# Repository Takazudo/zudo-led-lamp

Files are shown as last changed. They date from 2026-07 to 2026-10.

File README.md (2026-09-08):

# zudo-led-lamp

USB-PD powered LED lamp with fire/wave-like brightness modulation.

Docs: https://zudo-led-lamp.takazudomodular.com/

## Repo layout

- `doc/` — zudo-doc documentation site (source of truth for specs, notes, and build logs)
- `boards/board-p/` — KiCad project: USB-PD front end board
- `boards/board-l/` — KiCad project: driver + control + LED array board
- `boards/swd-adapter/` — KiCad project: ST-LINK/V2 20-pin to Board L 1x5 SWD adapter
- `enclosure/` — parametric starburst enclosure generator and [print/assembly guide](enclosure/README.md)
- `symbols/`, `footprints/` — shared KiCad symbol/footprint/3D libraries for all projects (see `footprints/CLAUDE.md`)

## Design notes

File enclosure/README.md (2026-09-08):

# Straight starburst bands — prototype 03

A **2.4 mm thin base plus six 13 mm single-piece bands**, approximately 116 mm across
and 86.4 mm tall excluding projecting fasteners. All star profiles align straight:
no twist and no assembly seams inside a band.

## Parts and color experiments

| File | Suggested color | Function |
| --- | --- | --- |
| 00-base | Clear | Thin mounting/access plate |
| 01-band-usb | Clear | 13 mm bottom band with USB notch |
| 02-band | Clear | 13 mm interchangeable middle band |
| 03-band | Amber | 13 mm interchangeable middle band |
| 04-band | Teal | 13 mm interchangeable middle band |
| 05-band | Clear | 13 mm interchangeable middle band |
| 06-band-top | Smoke | 13 mm top band without exposed pins |

Print each band in any color. **Bands 02–05 have identical geometry** and can be
reordered. Band body height excludes its 1 mm locating pins, which nest into the
next band and do not add to assembled height.

The current ZIP contains **21 assembly parts and eight fitting coupons**: seven
base/band pieces, eight PCB spacers, three feet and three flat-printable square posts. Replace your old extracted set.
The historical download name remains `smoke-reversing-stls.zip`; its contents are v3.
Find it in `doc/public/assets/enclosure/`, alongside `assembly-step.zip` containing
the complete assembled STEP. Reference electronics/hardware are excluded from print STLs.
The doc page `/docs/architecture/enclosure/` embeds the interactive preview.

## Connections and access

Three Ø2.4 × 1 mm pins enter Ø2.8 × 1.35 mm sockets and key the band orientation.
Three **printed 4 × 4 × 85.4 mm cuboid posts** pass through centered square holes
in the bands, base and feet. The default hole is exactly **4 × 4 mm** in CAD,
matching the requested post size. The posts are exported flat on an 85.4 × 4 mm
long face (only 4 mm tall on the print bed), but appear upright in the assembly.

The feet are **printed Ø12 × 6 mm round pads with centered square through-holes**,
without nut recesses. Try TPU for the feet and a rigid material for the posts.
Their intended assembled position leaves the post ends 1 mm above the bottoms
of the feet and flush with the top band; check that depth when fitting them.

There are no shell nuts, washers or threaded rods in this revision. Straight posts
provide fit-based retention, not positive axial locking or screw clamping. Support
the base when lifting the prototype; verify that parts do not slide unintentionally.

Print the 20 mm-long square-post coupon lying flat and the 13 mm-tall square-hole
coupons before the long posts. Holes of 4.0, 4.2 and 4.4 mm are supplied. Equal
nominal dimensions may bind after printing. If the 4.2 mm coupon fits best, regenerate
with `--post-clearance 0.2`; 0.4 selects 4.4 mm holes. The default remains zero.

The potentiometer opening is now a **30 × 38 mm rounded rectangular finger window**
instead of Ø24 mm. It extends toward the free side of the wheel while preserving the
nearby shared PCB mounting post. Corner radius is 6 mm. The switch retains its
20 × 24 mm opening. The wheel is still recessed: try actual fingertip adjustment
through a base print before committing to all bands.

The first band has an **18 × 13 mm full-height USB notch**. The second band closes
the roof during assembly, avoiding a wide printed bridge. Clearance checks use a
16 × 8 mm overmold to the PCB edge and an 8.4 × 2.6 mm metal-nose corridor.
Actual cable engagement is a physical check. Open top/base vents are not a thermal qualification.

## Print and assemble

1. Print the pin/socket coupons in the intended PETG. The 0.4 mm diametral-clearance
   coupon matches the enclosure. Adjust `socket_diameter` and regenerate if needed.
2. Print the base and spacers; dry-fit both boards and try operating the wheel by finger.
3. Board P uses three 5 mm spacers. Secure its independent hole before fitting the
   two 11 mm shared interboard spacers, three 17.6 mm Board L supports, and Board L.
   LEDs face upward, controls downward. The default 11 mm facing-surface gap is a
   prototype assumption: measure the naturally seated header pair before tightening.
4. PCB hardware: five approximately M3 × 25 mm nylon screws, one M3 × 14 mm nylon
   screw for Board P's independent hole, and six nylon nuts. Verify engagement and
   adjust lengths for your actual hardware.
5. Print the bands flat with pins upward, as separate objects in Bambu Studio.
   No additional rotation is required; an AMS is optional. Exchange middle bands freely.
6. Print the square posts in their supplied long-side-down orientation. Print the
   round feet flat, optionally in TPU using your filament/printer profile. Slide the
   feet, base and bands onto the square posts; keep the bottom post ends recessed
   1 mm above the feet bottoms. No metal shell fasteners are needed.
7. Check cable fit, slider travel, finger access, solder/lead clearance, retention
   and powered temperatures on the physical prototype.

Use the intended PETG profile, initially a 0.4 mm nozzle, 0.2 mm print layers and at
least three walls. Compare one thick band before the batch; solid/100% infill is an
optical starting point, not a tuned profile. Inspect the small locating-socket
bridges in the slicer; avoid supports inside sockets. The feet have open through-holes
and no internal nut-pocket roofs. Follow filament/plate instructions.
Material guidance: https://wiki.bambulab.com/en/knowledge-sharing/transparent-petg

## Regenerate and verify

`uv` and KiCad (`kicad-cli` on PATH) are enough; no CAD GUI is needed.

```sh
uv run enclosure/generate.py
# Optional measured facing-surface gap:
uv run enclosure/generate.py --board-gap 11.0
# Optional fit adjustment after testing the square-hole coupons:
uv run enclosure/generate.py --post-clearance 0.2
cd doc
pnpm generate:enclosure-viewer
pnpm build
```

Pinned CadQuery 2.6.1 and trimesh 4.8.3 run in an isolated uv environment.
The generator checks connected print bodies, watertight meshes, Z=0 placement,
PCB mounting/connector alignment, assembled solid interference and cable clearance.
The manifest records dimensions and source/mesh hashes and takes precedence after
custom regeneration. `--skip-pcb-models` is for debugging, not clearance validation.
Physical fit, fingertip ergonomics, solder, optical appearance and temperature still
need testing. Preview colors are illustrative; no optical or thermal simulation is claimed.

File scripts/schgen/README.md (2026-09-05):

# schgen — schematic generation from board spec modules

The `board-p`, `board-l`, and `swd-adapter` schematics are not hand-drawn. Each
is generated from a Python spec module (`board_p_spec.py`, `board_l_spec.py`,
or `swd_adapter_spec.py`) that lists components, positions, nets, and
no-connects. The spec is the source of truth; the `.kicad_sch` file is a build
artifact of it.

## Files

- `board_p_spec.py`, `board_l_spec.py`, `swd_adapter_spec.py` — per-project
  `COMPONENTS` / `NETS` / `NO_CONNECT` tables. Edit these, not the
  `.kicad_sch` directly.
- `schgen_core.py` — shared generator: reads symbols from
  `symbols/zudo-led-lamp.kicad_sym`, places components, and emits global
  labels for every net (no drawn wires) plus no-connect markers.
- `sexp.py` — tiny, dependency-free KiCad s-expression tokenizer/parser used
  by both the generator and the verifier. No KiCad install required.
- `gen_schematic.py` — CLI entry point: `generate()` a board from its spec.
- `verify_netlist.py` — diffs a kicad-cli netlist export against a spec's
  `NETS`/`NO_CONNECT` tables and prints `PASS`/`FAIL`.
- `verify_swd_adapter.py` — pure-Python end-to-end numeric orientation audit
  from the ST-LINK/V2 20-pin footprint through the adapter and straight cable
  to Board L J3; runs in CI.
- `verify.sh` — wraps the kicad-cli export + `verify_netlist.py` call for one
  board. Local-only (see below); not run in CI.

## Regen + verify workflow

1. Edit the relevant spec module — add/move a component, change a net, etc.
2. Regenerate the schematic:
   ```
   python3 scripts/schgen/gen_schematic.py swd_adapter_spec
   ```
   This rewrites `boards/<board>/<board>.kicad_sch` in place. No KiCad
   install needed — `gen_schematic.py` only depends on `sexp.py`.
3. Verify connectivity against a real netlist export (requires a local KiCad
   install with `kicad-cli` on `PATH`):
   ```
   scripts/schgen/verify.sh swd-adapter
   ```
   This runs `kicad-cli sch export netlist --format kicadsexpr` on the
   regenerated `.kicad_sch`, then diffs the result against the spec's `NETS`
   and `NO_CONNECT` tables via `verify_netlist.py`, printing `PASS`/`FAIL`.
4. Open the regenerated schematic in KiCad's Eeschema at least once (ERC,
   visual sanity) before committing.
5. Commit the spec module and the regenerated `.kicad_sch` together — never
   one without the other.

## kicad-cli availability

`verify.sh` degrades gracefully when `kicad-cli` is not on `PATH`: it prints
a `SKIPPED` marker and exits `0` rather than failing. This is intentional —
netlist verification is a local-only check that needs a real KiCad install
(the CI runner has no KiCad). Install KiCad (kicad-cli ships with the
desktop app; on macOS it resolves from `/Applications/KiCad/KiCad.app`) to
exercise the real path.

## What CI checks instead

CI cannot run kicad-cli, so it enforces a weaker but still useful invariant:
**regen-idempotency**. It runs `gen_schematic.py` for all three projects against the
checked-out tree and fails the build if that changes anything under
`boards/` (`git diff --exit-code boards/`). This catches "spec and committed
schematic have drifted apart" — e.g. someone edited a spec module and forgot
to regenerate, or hand-edited a `.kicad_sch` directly. It does **not** catch
wiring mistakes; only a local `verify.sh` run (or opening the file in KiCad)
does that.

## Low-profile rear controls

Board L fits G-Switch SS-12D01-G020 / C5446803 as SW2, with a reviewed through-hole PCB
footprint and 3D model. Common 2 receives V15_FUSED; pin 1 feeds V15; pin 3 is NC
on the board but becomes fused-feed live in OFF. No external-component export copy
is needed. `verify.sh board-l` checks the normal KiCad netlist and runs
`verify_power_switch.py` to verify fitted identity, NC and the ON/OFF supply graph.

RV1 is ALPS RK10J11E0034 / C470643 with physical stops. The wiper goes through
R27 to PA0 ADC_IN0, with R22 pull-down and C22 filtering. Four mechanical pads and
PA1 are NC. `scripts/pcb/verify-controls.py` checks the schematic/PCB net mapping,
corrected single-unit footprint pads, model bounds and two-board clearance.

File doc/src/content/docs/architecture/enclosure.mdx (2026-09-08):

---
title: Starburst Enclosure — Print and Assembly
description: A thin base plus six straight, interchangeable color bands, with larger fingertip access underneath.
sidebar_position: 37
---

**Prototype 03** combines the earlier thin panels into **six thick, single-piece
bands above a thin base**. All star profiles align straight, with no twist and no
assembly seams inside a band.

[Download current STLs](/assets/enclosure/smoke-reversing-stls.zip)
· [Open the full-size 3D preview](/assets/enclosure/index.html)
· [Assembled STEP (ZIP)](/assets/enclosure/assembly-step.zip)

[Assembled image](/assets/enclosure/assembled.png)
· [Exploded image](/assets/enclosure/exploded.png)
· [Underside controls](/assets/enclosure/underside.png)
· [Post in print orientation](/assets/enclosure/post-flat.png)
· [Original appearance reference](/assets/enclosure/selected-concept.png)

<iframe src="/assets/enclosure/index.html" title="Interactive starburst enclosure: assembled, exploded and underside views" width="100%" height="800" loading="lazy" style={{ border: "0" }} />

Use **Exploded** for the six bands, **PCB & base** for the mounts, and **Underside**
for the enlarged finger opening. Isolate individual parts to download their STLs.
The colors illustrate filament choices, not simulated light transmission.

## Thin base and six straight bands

The default size is approximately **116 mm across × 86.4 mm high**, excluding
projecting fasteners. Base thickness is **2.4 mm**, band thickness **13 mm**, and
foot height 6 mm. Locating pins add 1 mm of print height but nest into the next band.

| File | Body thickness | Suggested color | Function |
| --- | --- | --- | --- |
| `00-base` | 2.4 mm | Clear | PCB mounting and underside access |
| `01-band-usb` | 13 mm | Clear | Bottom band with USB notch |
| `02-band` | 13 mm | Clear | Interchangeable middle band |
| `03-band` | 13 mm | Amber | Interchangeable middle band |
| `04-band` | 13 mm | Teal | Interchangeable middle band |
| `05-band` | 13 mm | Clear | Interchangeable middle band |
| `06-band-top` | 13 mm | Smoke | Top band, no exposed locating pins |

**Bands 02–05 have identical geometry.** Print them in any colors and change their
order freely. The two clear pieces provide two independent color positions.
The first and last bands have distinct functional details; every outer profile aligns.

The ZIP contains **21 assembly parts and eight coupons**: seven base/band pieces,
eight PCB spacers, three round feet and three printed square posts. The historical filename is retained for existing
links, but the contents are v3. Replace the old extracted set rather than mixing revisions.

## Connections

Three **Ø2.4 × 1 mm pins** enter **Ø2.8 × 1.35 mm sockets**. Their asymmetric pattern
keys orientation. The broad band faces meet, with 0.4 mm diametral and 0.35 mm depth
clearance at the short pins. Each band prints flat with pins upward; the top band
has no upward pins.

Three **printed square posts, 4 × 4 × 85.4 mm**, pass through **4 × 4 mm square
holes** in the bands, base and feet. The nominal post and hole dimensions match
exactly, as requested. Each post is a plain cuboid exported on its long face:
**85.4 × 4 mm bed contact and only 4 mm print height**. The preview assembles it
upright; selecting an individual post shows its flat print orientation.

The feet are **Ø12 × 6 mm printed cylinders with centered square through-holes**,
without nut pockets. TPU is an option for the feet; use rigid filament for the posts.
In the assembly the posts end 1 mm above the bottoms of the feet and flush with the
top band. Check insertion depth and foot deformation on the physical print.

This is a **fit-based assembly**, without metal shell rods, nuts or washers. There
is no positive axial lock: straight posts cannot clamp the stack like threaded rods.
Support the base when lifting and check for unintended sliding.

Eight coupons cover both interfaces: the four existing short-pin/socket coupons,
plus a 20 mm flat square-post coupon and three 13 mm-high hole coupons with
**4.0, 4.2 and 4.4 mm square holes**. Exact nominal matching may bind in a real print.
If needed, `--post-clearance 0.2` produces 4.2 mm holes throughout the assembly;
`0.4` produces 4.4 mm holes. Default clearance is zero.

## Larger fingertip opening

The previous Ø24 mm potentiometer hole is replaced by a **30 × 38 mm rounded
rectangular window**, with 6 mm corner radii. It extends toward the free side of
the wheel to allow fingertip approach and sweeping movement. Its offset preserves
the nearby shared PCB post and the web supporting it.

In CAD coordinates, the window spans X14–44 and Y−6–32 mm before corner rounding;
the wheel center is approximately (21.9, 18). The switch has its separate
**20 × 24 mm** opening. Both controls remain recessed underneath. Print the base
first and actually turn the wheel by finger; CAD cannot establish comfort.

## PCB mounting and USB

Board L LEDs face up and its controls face down. Board P remains below it using
`xL = xP + 16.5`, `yL = yP`. Hole positions are read from the KiCad files.
See [Rear Controls](./rear-controls.mdx) for component placement and evidence.

| Spacer | Board L front-view coordinates (mm) | Supports |
| --- | --- | --- |
| `mount-01-17.6mm` | (4, 4) | Board L |
| `mount-02-17.6mm` | (4, 56) | Board L |
| `mount-03-5.0mm` | (20.5, 4) | Board P, shared hole |
| `mount-04-5.0mm` | (29.3, 32.6) | Board P, independent hole |
| `mount-05-5.0mm` | (39.5, 4) | Board P, shared hole |
| `mount-06-17.6mm` | (56, 56) | Board L |
| `interboard-01-11.0mm` | (20.5, 4) | Between boards |
| `interboard-02-11.0mm` | (39.5, 4) | Between boards |

The **11 mm facing-surface gap** remains provisional: measure the naturally seated
header pair before clamping. Do not pull the boards into an assumed spacing with
screws. An underside view mirrors left/right visually; do not mirror the STL files.

The bottom band has an **18 × 13 mm full-height USB notch**. The next band closes
its roof during assembly, so a wide horizontal bridge need not be printed.
The cable check reserves a 16 × 8 mm overmold corridor to the PCB edge and an
8.4 × 2.6 mm metal-nose corridor; actual insertion still needs physical verification.
The open top and base slots provide airflow, with powered thermal testing pending.

## Printing and assembly

1. Print pin/socket coupons in the intended filament. The 0.4 mm-clearance socket
   matches this version. Adjust `socket_diameter` and regenerate if needed.
2. Print the base and spacers; dry-fit the boards and test actual fingertip adjustment.
3. Mount Board P on three 5 mm spacers and secure its independent hole. Fit the two
   11 mm interboard spacers, three 17.6 mm Board L supports, then seat Board L LEDs up.
4. Print each band flat as a separate Bambu Studio object, pins upward. No extra
   rotation is required. Each band can use any color; an AMS is optional.
5. Print the long cuboid posts lying flat in the supplied STL orientation. Print
   the round feet flat, optionally in TPU. Slide feet, base and bands over the
   square posts; set the post bottoms 1 mm above the feet bottoms. Test retention.

PCB hardware starting point: **five M3 × 25 mm nylon screws, one M3 × 14 mm nylon
screw and six nylon nuts**. Check thread engagement and adjust for your hardware.
The shell connection posts and feet are now printed; no metal shell fasteners are
required. The PCB mount still uses the nylon screws listed above. The preview does
not model PCB screw threads or actual solder.

Start with the selected PETG profile, a 0.4 mm nozzle, 0.2 mm print layers and at least
three walls. Compare one thick band first: solid/100% infill is an optical starting
point, not a tuned prescription. Inspect the short locating-socket bridges and avoid supports
inside locating sockets. Follow filament/plate instructions and Bambu's
[transparent PETG guidance](https://wiki.bambulab.com/en/knowledge-sharing/transparent-petg).

## Source and verification

The source is `enclosure/generate.py`. `uv` installs pinned CadQuery and trimesh
in an isolated environment; KiCad exports the placed board/component geometry.
No desktop CAD application is needed to print these STLs.

```sh
uv run enclosure/generate.py
# Optional measured facing-board gap:
uv run enclosure/generate.py --board-gap 11.0
# Optional square-hole fit adjustment after the coupons:
uv run enclosure/generate.py --post-clearance 0.2
cd doc
pnpm generate:enclosure-viewer
pnpm build
```

The [manifest](/assets/enclosure/manifest.json) records dimensions, placements,
source/mesh hashes and verification results. It takes precedence over these default
dimensions after a custom regeneration. Checks cover connected print bodies,
watertight meshes, Z=0 placement, PCB mounts and connector alignment, assembled
interference and cable clearance. The docs build rejects stale source/mesh hashes.
Reference component meshes are excluded from the print ZIP.

The assembled-fit verdict remains **NEEDS BENCH**: verify actual seating, cable fit,
fingertip operation, solder/lead clearance, optical appearance and temperatures.
Existing component evidence and limitations are retained in
[Rear Controls](./rear-controls.mdx). The previous Board P guide correction on Board L
(`Edge.Cuts` → `Dwgs.User`) remains; this revision does not move components.

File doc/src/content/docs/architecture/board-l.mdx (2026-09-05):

---
title: Board L — Driver, Control, LED Array
description: The locked Board L design — 24 warm-white 2835 LEDs in 8 parallel 3-series strings at 500mA, an AL8860 constant-current buck, an AP63203 3.3V rail, an STM32G031 MCU and a stopped ALPS potentiometer, with a complete pin-level net table and worked component math.
sidebar_position: 30
---

Board L is everything that is not USB-PD negotiation: the constant-current LED driver,
the LED array itself, the 3.3 V logic rail, the control MCU, and the knob. It consumes
the switched 15 V rail from [Board P](./board-p.mdx) and nothing else.

The rear PCB [C5446803 slide switch](./power-switch.mdx) disconnects both
converters after F1. RV1 and SW2 are on the rear, leaving the LEDs facing the light chamber. See the
[rear-controls layout and enclosure handoff](./rear-controls.mdx).

## Block diagram

```mermaid
flowchart LR;
  J2["J2 PM254V female 6P\n15V x2, GND x2, ATT, PDOK"];
  F1["F1 PPTC\n750mA hold / 30V"];
  V15["V15 rail\nD10 SMAJ20A\nC10 C11 10uF"];
  RS1["RS1 200mR 2512\nhigh-side sense"];
  U2["U2 AL8860MP-13\nVIN pin 8"];
  SETN["SET node\nU2 pin 1"];
  L1["L1 33uH\n2.1A sat"];
  LEDP["LED_P\narray anode rail"];
  BAL["R30..R37\n8x 33R 2512 ballast"];
  STR["8 strings x 3 series\n24x HL-AM-2835H421W\n3000K, 62.5mA each"];
  LEDN["LED_N = switching node\nU2 SW pins 5,6"];
  D11["D11 SS26 60V\ncatch diode"];
  U4["U4 AP63203WU-7\n3.3V sync buck"];
  V33["V3P3 rail\nC16 C17 22uF"];
  U3["U3 STM32G031F8P6"];
  RV1["RV1 ALPS 10k potentiometer"];
  RT1["RT1 NTC 10k\nin the LED array"];
  RCF["R20 10k / R21 33k / C21 100n\nRC low-pass, 0 to 2.53V DC"];
  CTRL["U2 CTRL pin 4\nanalog dimming"];
  J3["J3 SWD pads"];
  J4["J4 UART pads"];

  J2 --> F1;
  F1 --> SW2["PCB slide switch C5446803\nmaintained ON-OFF"];
  SW2 --> V15;
  V15 --> RS1;
  V15 --> U2;
  RS1 --> SETN;
  SETN --> L1;
  L1 --> LEDP;
  LEDP --> BAL;
  BAL --> STR;
  STR --> LEDN;
  D11 --- LEDN;
  D11 --- V15;
  V15 --> U4;
  U4 --> V33;
  V33 --> U3;
  RV1 -->|"Wiper via RC filter\nPA0 ADC_IN0"| U3;
  RT1 -->|"PA4 ADC_IN4"| U3;
  J2 -->|"ATT / PDOK"| U3;
  U3 -->|"PA6 TIM3_CH1\n20kHz PWM"| RCF;
  RCF --> CTRL;
  J3 --- U3;
  J4 --- U3;
```

## LED array and the brightness number

The [LED candidates](/docs/research/led-candidates/) page left CCT open. For a
fire/candle effect the answer is **warm**, and warm is exactly where the JLCPCB stock
sits: `HL-AM-2835H421W-S1-08-HR3` ([C210315](https://jlcpcb.com/partdetail/C210315)) at
399,813 units, in the 2800–3100 K bin.

Its manufacturer specification (Honglitronic B-17-A-0596 Rev A/2) gives real optical
numbers, which the parts DB does not:

| Parameter | Value (at IF = 60 mA) |
|---|---|
| Luminous flux, 2800–3100 K bin | **27 lm min, 29 lm typical** |
| CCT typical | 3000 K |
| CRI (Ra) | 80 min |
| Forward voltage | 2.6 V min, 3.2 V max (±0.1 V measurement tolerance) |
| Viewing angle | 120° |
| Package rating | 306 mW |

### Arrangement

**8 parallel strings of 3 series LEDs = 24 emitters, 500 mA total, 62.5 mA per string.**

3-series was chosen over 4-series. The [headroom analysis](/docs/research/led-candidates/#voltage-headroom-analysis)
called 4s "tight"; with this part's datasheet Vf ceiling of 3.2 V a 4s string is 12.8 V,
which puts the buck at **~88% duty** by the datasheet's own equations — far outside the
AL8860's recommended 25–75% duty band (DS39014 Rev 5, "Recommended Duty Cycle Range").
3s plus a ballast resistor lands at **77%**, 2 points above the band and far below the
98% maximum — the trade this design accepts. (The worked figures are
[below](#al8860-constant-current-driver); the naive `Vout/Vin` reading gives 85%/74% and
understates both.)

### Brightness

| | Value |
|---|---|
| Typical flux | 24 x 29 lm = **~700 lm** |
| Worst-case bin | 24 x 27 lm = **648 lm** |
| System efficacy | ~700 lm / 6.16 W = **114 lm/W** |

For scale: a 60 W incandescent bulb is about 800 lm, and a typical decorative table lamp
is 300–600 lm. ~700 lm through a diffuser is a genuinely bright ambient lamp, and the
modulation spends most of its time below full scale.

The flux figures are read at the datasheet's 60 mA test point; the design runs 62.5 mA
(+4%), so the real number is marginally higher. It is quoted at the 60 mA value rather
than extrapolated.

### Ballast and current sharing

The parallel strings need ballast — [led-candidates](/docs/research/led-candidates/#current-sharing-considerations-for-parallel-strings)
lists three ways, and per-string resistors are the one that fits: one CC driver per
string would mean eight AL8860s and eight passive sets, and Vf-binned procurement is not
something the JLCPCB catalog can guarantee.

**R30–R37 = 33 Ω, 2512, 1 W** ([C2934070](https://jlcpcb.com/partdetail/C2934070), ±1%):

The design review moved this line from a 250 mW 1206
([C2907384](https://jlcpcb.com/partdetail/C2907384)) to a 1 W 2512. Resistor dissipation
goes as I², so the upsize is headroom against *peak* branch current, not nominal. At the
worst-case branch peak derived below — 88.19 mA, at the locked 0.30 V Vf spread — the
1206 would sit at **103% of its rating** (0.257 W);
at the LED's own 90 mA absolute-maximum forward current it would sit at 107% (0.267 W).
The 2512 runs at 26% of rating at that same 88.19 mA, and its larger copper helps spread
the array's heat.

| Quantity | Value |
|---|---|
| Ballast drop at 62.5 mA | 2.06 V |
| Dissipation per resistor | 129 mW — **13%** of the 2512 part's 1 W rating (was 52% of the old 1206's 250 mW) |
| Total ballast loss | 1.03 W (19% of delivered power) |

Current sharing across the eight strings is bounded by an **assembled-string Vf
spread** — `max(string total Vf) − min(string total Vf)` across the eight 3-LED
strings, not a ±-from-centre figure. And the driver's own datasheet worst case already
consumes most of the LED's headroom before any Vf mismatch exists: total peak current
is **0.6303 A** (the 0.5253 A maximum mean current at the AL8860's maximum sense
threshold over the sense resistor's minimum initial resistance, raised by half the
40% coil ripple the driver sets internally), against ballast of 33 Ω ±1% and a 90 mA
absolute-maximum LED forward current. Each input is a manufacturer-primary datasheet
limit, but the composed 0.6303 A is a calculated stack-up carrying a `NEEDS BENCH`
verdict — a datasheet worst case, not a measured or guaranteed one:

| Assembled-string Vf spread | Hottest branch, peak | vs the 90 mA absolute maximum |
|---|---|---|
| 0 V (perfectly matched) | 80.18 mA | 89.1% |
| **0.30 V (locked acceptance limit)** | **88.19 mA** | **98.0%** |
| 0.3677 V (computed bound) | 90.00 mA | 100.0% |
| 1.80 V (full retained 2.6–3.2 V window, unmitigated) | 128.27 mA | 142.5% |

**Even with perfectly matched strings the design sits at 89% of the LED's
absolute-maximum forward current on a peak basis.** The driver's own datasheet worst
case — maximum sense threshold, minimum sense resistor, full ripple peak — consumes 89%
of the limit before any Vf mismatch exists; the entire Vf-matching budget is the
remaining 9.8 mA. At the full retained 2.6–3.2 V window, unmitigated, the hottest LED
reaches 128.3 mA peak / 114.9 mA mean — 142% / 128% of the absolute maximum. The old
conclusion here landed on exactly 90 mA only because it used nominal current with no
ripple and no resistor tolerance — that result was an artifact of the assumption, not a
property of the design.

On a **mean** basis the picture is comfortable: at the locked 0.30 V limit the hot
branch averages 74.8 mA (83% of 90 mA) and dissipates 194.6 mW at Vf = 2.6 V — **64%**
of the 306 mW package rating (not the smaller derived-not-datasheet figure this page
previously used, from 3.2 V × 90 mA rather than the manufacturer spec). Peak-against-
absolute-maximum is the conservative gate (no pulsed-current rating is retained for this
part); mean is what governs junction temperature. Both readings belong here: peak is the
gate, mean is the thermal reality.

**Locked acceptance limit: 0.30 V**, defined as the full spread across the eight
assembled 3-LED strings, not ±0.30 V. It applies per assembled string, not per LED —
0.30 V over three LEDs is 0.10 V each, exactly the datasheet's own Vf measurement
tolerance. Measurement protocol, summarized: 60 mA DC ±1%, either a single 10 ms pulse at
≤1% duty or a 30 s DC soak, applied identically to all 24 LEDs, at 25 ±3 °C with ≤10 mV
differential instrument uncertainty; sort all 24 LEDs descending by Vf and greedily
assign each to whichever of the eight groups currently has the smallest running sum;
gate on the assembled string totals, not on individual LEDs. Full protocol and scope:
[#35](https://github.com/Takazudo/zudo-led-lamp/issues/35).

Ballast stays **33 Ω, 2512, 1 W** — this finding is about the driver's own current
headroom, not the ballast value, and within the existing inventory there is no lever for
more margin (raising RS1 or increasing the ballast both need a new part). Raised as a
follow-up issue rather than fixed here: see
[#52](https://github.com/Takazudo/zudo-led-lamp/issues/52).

Ballast resistors sit on the **anode side** (between `LED_P` and each string's top LED)
so that the common `LED_N` node — the driver's switching node — stays as one compact
net instead of eight. Note the review's correction to the original rationale: `LED_P`
is **not** a quiet DC rail. The string voltage is essentially fixed, so when `LED_N`
swings 0 → ~15.5 V, `LED_P` swings ~11 → ~26.6 V right along with it — every net in
the LED array is a switching node. The anode-side placement still wins (one compact
`LED_N` beats eight), but no LED-array net may be poured as a large plane.

## AL8860 constant-current driver

`AL8860MP-13` ([C500782](https://jlcpcb.com/partdetail/C500782)), MSOP-8EP.

The AL8860 is a hysteretic buck with **high-side current sensing**: the sense resistor
sits between `VIN` and `SET`, and the LED string floats above an internal low-side NDMOS
switch. That topology is the reason `LED_N` (the common cathode) is a switching node.

| Design point | Value | Source |
|---|---|---|
| Sense resistor RS1 | **200 mΩ** → `I = 0.1 / Rs` = **500 mA** | DS39014 Rev 5, "LED Current Configuration" |
| Output voltage | 3 x 3.0 V + 2.06 V ballast = **11.06 V** | — |
| Duty cycle | **~77%** by the datasheet's own equations (which include the diode and resistive drops; the naive 11.06/15 = 74% understates it) — 2 points above the recommended 25–75% band, far below the 98% max | DS39014 Rev 5, "Inductor Selection" |
| Inductor L1 | **33 µH** | ripple is set internally at ±20% of sense threshold; L sets frequency |
| Switching frequency | `T = ΔI·L·(1/(Vin−Vout) + 1/(Vout+Vd))` → **~440 kHz** | under the 1 MHz max |
| Minimum on-time | 1.69 µs | above the 500 ns recommended minimum |
| RS1 dissipation | 50 mW on a 2 W part | 2.5% |
| L1 DCR loss | 310 mΩ x 0.25 A² = 78 mW | |
| D11 conduction | 26% x 0.5 A x ~0.45 V = 59 mW | |
| Switch conduction | 0.2 Ω x 0.25 A² x 0.74 = 37 mW | |
| **Estimated efficiency** | **~95%** from component losses; **92% used in the budget** | conservative vs the research page's 88% assumption |

Duty cycle across the LED's full Vf bin:

| Vf per LED | String V | Vout with ballast | Duty (datasheet eqns) | Note |
|---|---|---|---|---|
| 2.6 V (bin min) | 7.8 V | 9.86 V | 69% | inside the band |
| 3.0 V (nominal) | 9.0 V | 11.06 V | 77% | design point — 2 points above the recommended 25–75% band |
| 3.2 V (bin max) | 9.6 V | 11.66 V | 81% | accepted, still far below the 98% max duty |

These figures are all against the AL8860's **DSW** parameter — the recommended
buck-switch operating duty-cycle range, 25–75%, guaranteed by design (DS39014 Rev 5,
primary-confirmed). That is a different number from **DSW(MAX)**, the 98%
absolute-maximum duty cycle, and from the separate 5–100% analog-dimming range on the
**CTRL** pin — three distinct datasheet figures that are easy to conflate. The
77%-nominal design point sits 2 points above the DSW band and is unchanged by this
distinction; it is spelled out here because readers currently have to infer it.

The review corrected these duty figures (the original 66/74/78% used `Vout/Vin` without
the diode and resistive terms). The honest statement of the 3s-vs-4s choice is: 3s sits
*slightly above* the recommended band across most of the Vf bin; 4s at ~88% would sit
far above it. 3s is still the right call. If bench accuracy suffers, 22 Ω ballast pulls
nominal duty to ~72% at the cost of ~40% worse current sharing.

**Input rating vs a conditioned clamp point.** AL8860's recommended VIN maximum is 40 V and its
absolute maximum is **42 V** (DS39014 Rev 5, "Absolute Maximum Ratings"). Board P's
SMAJ20A table gives 32.4 V only at 12.3 A, 10/1000 µs, and 25 °C. AL8860 has **7.6 V
recommended / 9.6 V absolute static headroom** against that screening point, which is
why it was selected over PT4115. The actual waveform remains open—see
[Decisions](./decisions.mdx#led-driver-ic-driver-input-rating-vs-a-conditioned-clamp-screening-point).

## AP63203 logic rail (not an LDO)

`AP63203WU-7` ([C780769](https://jlcpcb.com/partdetail/C780769)), TSOT-23-6, fixed 3.3 V.

The [logic-rail research](/docs/research/control-logic-rail/) says an LDO is fine below
~30 mA, and this rail draws ~25 mA worst case. By that rule alone the LDO wins. The
conditioned rail-envelope screen overrides it:

| Candidate | VIN max | Against the conditioned 32.4 V table point |
|---|---|---|
| AMS1117-3.3 | 15 V | No operating margin at the nominal rail; absolute maximum cannot be the design point |
| HT7333-1 | 18 V | **14.4 V below** the conditioned screen, with little transient headroom |
| **AP63203WU-7** | 32 V recommended, **35 V DC / 40 V for 400 ms absolute max** (DS41326 Rev 3) | Static limits cover the screening point by 2.6 V DC / 7.6 V transient |

AP63203 provides the strongest supported static headroom for about $0.60 and a
three-part BOM increase. It does not close the protected-rail proof: actual clamp
current/waveform, effective capacitance, layout, loads, and bench behavior remain open
under issue #34.

Component values from DS41326 Table 2 (AP63203, 3.3 V): L = 3.9 µH, C1 = 10 µF,
C2 = 2 x 22 µF, C3 = 100 nF. Implemented as **L2 = 4.7 µH**
([C167874](https://jlcpcb.com/partdetail/C167874), 78 mΩ DCR — the datasheet asks for
under 100 mΩ, and 2.2–10 µH is its stated acceptable range), C14 = 10 µF, C16/C17 =
2 x 22 µF, C15 = 100 nF bootstrap. `EN` is left open: the block diagram (DS41326
Figure 3) shows an internal current source on EN and the pin description states "leave
open for automatic startup".

## MCU, knob, and dimming path

`STM32G031F8P6` ([C529334](https://jlcpcb.com/partdetail/C529334)), TSSOP-20, 64 KB
flash / 8 KB SRAM, Cortex-M0+, 12-bit ADC.

`RK10J11E0034` ([C470643](https://jlcpcb.com/partdetail/C470643)), stopped single-unit
10 kΩ potentiometer, read by PA0 / ADC_IN0.

### Analog dimming, not PWM dimming

This is the single most consequential control decision, and the AL8860 datasheet decides
it. DS39014 Rev 5 states that for PWM on the CTRL pin, "the PWM frequency is recommended
to be lower than 500 Hz" for high resolution. But the
[modulation research](/docs/research/modulation-algorithms/#pwm-carrier-frequency-choice)
sets the flicker-perception floor at ~300 Hz for peripheral vision. A 500 Hz PWM carrier
clears that by only 1.7x — thin margin for a lamp that is specifically meant to be seen
out of the corner of the eye. Pushing the carrier up to get flicker margin is exactly
what the datasheet says costs dimming accuracy.

**Analog dimming escapes the conflict entirely.** A DC level on CTRL scales the LED
current continuously; the LED current never chops, so there is no flicker frequency to
argue about and no PWM modulation of the inductor to make audible noise. The datasheet's
"Recommended Analog Dimming Range" is **5% to 100%**, a 20:1 span.

The DC level is produced by low-pass filtering an MCU PWM output — the "case (b)" the
modulation research anticipated:

```
PA6 (TIM3_CH1, 20 kHz PWM, 0-3.3 V)
   |
  R20 10k
   +---- R21 33k ---- GND      (divider: 3.3 V x 33/43 = 2.53 V at 100% duty)
   |
  C21 100nF ---- GND           (filter + AL8860 soft-start capacitor)
   |
  U2.CTRL
```

| Quantity | Value |
|---|---|
| Full-scale CTRL voltage, nominal | 3.3 V x 33/43 = **2.53 V** — just past the 2.5 V clamp point, so 100% duty = 100% of I_NOM **nominally** |
| Full-scale CTRL voltage, guaranteed floor | Rail 3.27 V min, R20 max 10.1 kΩ, R21 min 32.67 kΩ → **2.4978 V**, guaranteeing **99.9%** of I_NOM, not 100% |
| Filter cutoff | R20 ∥ R21 = 7.67 kΩ with 100 nF → **208 Hz** |
| PWM carrier | **20 kHz** — ~40 dB of attenuation, leaving tens of millivolts of residual ripple on a 2.53 V span, and above the audio band regardless |
| Animation update rate | **50 Hz** — filter τ is 0.77 ms against 20 ms frames, so no visible lag |
| Duty at the CTRL off threshold (0.3 V) | 11.9% |
| Duty at the 5% current floor (0.41 V) | 16.2% |
| Soft-start from C21 | 100 nF x 1.5 ms/nF = **150 ms** |

The "100% duty = 100% of I_NOM" claim is **nominal-only**. At the guaranteed worst-low
corner (rail at 3.27 V, R20 at its 1% maximum, R21 at its 1% minimum) CTRL's floor is
2.4978 V against the AL8860's 0.3–2.5 V analog-dim range, which guarantees **99.9%** of
I_NOM rather than 100%. Two items stay open alongside that number, not closed by it:

- The floor assumes `PWM_DIM` drives to the rail. No STM32G031 output-level (V_OH)
  rating is retained, so the GPIO's own drop is not covered by evidence. Physically it
  is negligible — the divider draws only 76.7 µA, so even a 50 Ω driver contributes
  ≈3.8 mV — but the 99.9% figure is conditional on an assumption the registry does not
  currently substantiate.
- The worst-high corner (rail at 3.33 V, R20 at its minimum, R21 at its maximum) puts
  **2.567 V** on CTRL, above the 2.5 V top of the analog-dim range. Benign for dimming —
  it simply saturates at full current — but no CTRL absolute-maximum rating is retained
  for the AL8860.

### Safe default-OFF

The AL8860's CTRL pin **floats to ON** ("leave floating for normal operation"). That is
the opposite of what [control-safety](/docs/research/control-safety/) requires, so the
default-off has to be built deliberately. Two independent mechanisms do it:

1. **R21, 33 kΩ pull-down on CTRL.** With PA6 in its reset high-impedance state, CTRL is
   tied toward ground rather than allowed to float up.
2. **C21's 150 ms soft-start.** Even in the worst case where the pull-down fails to hold
   CTRL below the 0.2 V off threshold, the driver's output cannot reach full current for
   150 ms. The STM32G031 reaches firmware GPIO configuration in roughly 1–2 ms after
   power-on reset — two orders of magnitude inside that window. The same protection
   covers brown-out and watchdog resets.

:::caution[The pull-down's bound is asserted but not retained — Gate 3 is a real gate]
The 2026-08-01 design review argued R21 *is* provable from the datasheet: the soft-start
spec (1.5 ms/nF to charge CTRL) bounds the internal bias current at ≤1.67 µA, which into
33 kΩ is **≤55 mV** — at least 3.6x below the 0.2 V off threshold, with PA6 Hi-Z at reset.

**Neither input to that argument is in the evidence registry.** There is no soft-start
rate and no CTRL bias-current fact anywhere under
`.claude/skills/component-al8860mp-13/`; the only retained CTRL fact is
[`fact-al8860-ctrl`](/docs/components/records/al8860mp-13/#fact-al8860-ctrl), which gives
the 0.2 V off threshold, the 0.3–2.5 V analog range and the PWM guidance — no bias
current. The ≤55 mV result therefore cannot be recomputed offline and, by this project's
own rule, `UNSOURCED` evidence cannot close a domain.

Worse, retaining the missing row would not rescue the argument. The soft-start rate is a
**typical** characteristic; the AL8860 publishes no *guaranteed maximum* CTRL source
current. A typical value cannot bound a worst case, so ≤1.67 µA is not a limit that can
be designed against however it is sourced — it is an estimate. R21 remains good practice
and almost certainly works; it is simply not a proof.

So: **mechanism 2 (C21's 150 ms soft-start) is the one that stands on its own**, and
mechanism 1 is a plausible but unevidenced bound. Gate 3's CTRL measurement with the MCU
held in reset (probe TP1) is a gate on this design, not a formality. Closing mechanism 1
properly means retaining the DS39014 soft-start row as a fact on the AL8860 record.
:::

### Knob mapping

RV1 is **ALPS RK10J11E0034 / C470643**, a single-unit 10 kΩ ±30% potentiometer
with **270° ±10° travel and physical stops**. Pin 1 is GND, pin 3 is V3P3,
and pin 2 is the wiper. The four dummy/support terminals remain unconnected.
The exact manufacturer drawing identifies electrical terminals at the two outer
positions and the centre of the five-terminal row; the two intervening terminals
are dummy supports, not a second resistor element.

`RV1.2 → BRIGHT_WIPER → R27 (100 Ω) → BRIGHT_ADC → U3.7 (PA0 / ADC_IN0)`.
R22 is now a 100 kΩ pull-down from BRIGHT_ADC to GND; C22 is 100 nF to GND.
R23, R28 and C23 are removed, and PA1/U3.8 is unconnected. With the pot's
maximum 13 kΩ track resistance, the conservative source resistance is
13 kΩ / 4 + 100 Ω = **3.35 kΩ** before the parallel pull-down is considered.
Use the documented **160.5-cycle ADC acquisition target**, and validate settling
after channel changes against the selected ADC clock, reference and device errata.
An open wiper discharges C22 through R22 with nominal **10 ms** time constant;
this biases an open wiper toward dark but does not detect every wiring or contact fault.

Firmware reads an absolute position rather than counting encoder edges. Calibrate
ADC endpoints, allow inversion after checking clockwise direction from underneath,
average samples, clamp the result and apply the existing brightness/modulation mapping.
The pull-down loads the track, so raw ADC codes are not an ideal unloaded angle scale.
Keep PWM off during reset and initialization; after valid ADC, PD-status and thermal
checks, ramp toward the measured knob position. There is no fixed 40% boot target.
These are implementation requirements: this repository has no executable control firmware.

### Modulation algorithm

Two layers of filtered noise ([approach 1](/docs/research/modulation-algorithms/),
layered as that page suggests) — a slow "breathing" layer and a faster "flicker" layer,
summed around the knob's base brightness. Approach 3 (recorded-flame LUT) is rejected
because no such dataset exists for this project; approach 2's bounded random walk is
folded in as the slow layer's character rather than kept as a separate mode.

This is an algorithm sketch, not executable firmware. The ADC/calibration and startup
helpers below require implementation; initialization must ramp from zero to the
validated absolute position before enabling normal animation.

```c
/* ---- fixed constants (tune against the real diffuser, not on the bench) ---- */
#define FRAME_HZ            50
#define SLOW_ALPHA          12    /* one-pole IIR alpha, /256 - lazy breathing   */
#define FAST_ALPHA          64    /* one-pole IIR alpha, /256 - candle flicker   */
#define SLOW_DEPTH          70    /* /256 of full scale                          */
#define FAST_DEPTH          38    /* /256 of full scale                          */
#define GAMMA               2.2f

/* CTRL-window mapping, from the divider + AL8860 thresholds above */
#define DUTY_FLOOR_Q16      10617 /* 16.2% of 65535 -> CTRL 0.41V -> 5% of I_NOM */
#define DUTY_FULL_Q16       65535 /* 100%          -> CTRL 2.53V -> 100%          */

static int16_t slow_state, fast_state;
static uint8_t gamma_lut[256];    /* lut[i] = round(255 * pow(i/255, GAMMA)) */

/* ---- one animation frame, called at FRAME_HZ ---- */
void animation_frame(void)
{
    /* 1. knob -> base brightness, perceptual 0..255 */
    uint8_t base = brightness_adc_calibrated();   /* averaged/inverted PA0, 0..255 */
    if (!startup_pd_thermal_checks_valid() || base == 0) {
        pwm_set_duty_q16(0);                     /* stop stays dark despite noise */
        return;
    }

    /* 2. two layers of low-pass-filtered noise */
    int16_t slow_raw = (int16_t)random_uniform(-128, 127);
    int16_t fast_raw = (int16_t)random_uniform(-128, 127);
    slow_state += ((slow_raw - slow_state) * SLOW_ALPHA) >> 8;
    fast_state += ((fast_raw - fast_state) * FAST_ALPHA) >> 8;

    int16_t modulated = (int16_t)base
                      + ((slow_state * SLOW_DEPTH) >> 8)
                      + ((fast_state * FAST_DEPTH) >> 8);
    uint8_t perceptual = (uint8_t)clamp_i16(modulated, 0, 255);

    /* 3. thermal derate (NTC on PA4) - see apply_thermal_derate() below */
    perceptual = apply_thermal_derate(perceptual, ntc_temp_c_x10());

    /* 4. hard off, or gamma -> CTRL window */
    if (perceptual == 0) {
        pwm_set_duty_q16(0);                      /* CTRL -> 0V, driver off      */
        return;
    }
    uint8_t g = gamma_lut[perceptual];
    uint32_t duty = DUTY_FLOOR_Q16
                  + ((uint32_t)g * (DUTY_FULL_Q16 - DUTY_FLOOR_Q16)) / 255u;
    pwm_set_duty_q16((uint16_t)duty);
}
```

The pipeline is `modulation -> thermal derate -> gamma LUT -> CTRL duty`, exactly the
composition [control-safety](/docs/research/control-safety/#fault-handling-sketch-over-temperature-derating-hook)
describes. The 256-byte gamma LUT is trivial against 64 KB of flash.

:::caution[Pulse-skip near the bottom of the analog range]
The "no flicker by construction" claim holds where the converter runs continuously. The
AL8860's ripple is set at 40% of the programmed current, so as CTRL dims, the required
on-time shrinks — at the 5% floor it computes to ~45 ns, far below the 500 ns
recommended minimum, and the datasheet's own "Pulse Skip Mode" waveform is what happens
instead: burst-firing at an unpredictable rate that *is* a flicker frequency. This is
inside the manufacturer's sanctioned 5–100% analog range, but Gate 4 must sweep CTRL
while watching `LED_N` on a scope and record where pulse-skip starts; if the burst rate
lands under ~300 Hz, raise the firmware's `DUTY_FLOOR_Q16` above that point.
:::

:::note[The dimming floor is 5%, not zero]
Analog dimming below 5% of I_NOM is outside the AL8860's guaranteed range, so the
effect's minimum is a ~25 mA / ~35 lm glow with a hard step to fully off at perceptual
zero. For a flame effect this is arguably correct — real embers do not go to black — but
it means a very slow fade-to-nothing is not achievable without PWM chopping. Worth
knowing before tuning `SLOW_DEPTH` so far that frames land at perceptual 0 and produce a
visible on/off snap.
:::

### Thermal derate

`RT1` is an `NCP18XH103F03RB` 10 kΩ B=3380 K NTC ([C13564](https://jlcpcb.com/partdetail/C13564))
placed **inside the LED array**, in a **100 kΩ** divider to PA4 (ADC_IN4).

| Board temperature | NTC resistance | PA4 voltage | 12-bit ADC code | Firmware action |
|---|---|---|---|---|
| 25 °C | 10.00 kΩ | 0.300 V | 372 | normal |
| 65 °C | 2.616 kΩ | 0.0841 V | 104 | `DERATE_START` — begin linear roll-off |
| 80 °C | 1.711 kΩ | 0.0555 V | 69 | `CRITICAL` — hard off |

The thresholds sit under the LED's own −40…+85 °C operating range with margin.

The binding limit on this divider's current is Murata's **0.1 mA maximum operating
current**, not the 100 mW power rating this page previously compared against. Murata's
own column header reads "Maximum Operating Current (25 °C)"; the parallel catalog term
"Permissive Operating Current" is defined as the current that keeps the thermistor's
self-heating rise to at most 1 °C. **The outgoing 10 kΩ divider violated it**: 168 µA
worst case at 25 °C — 1.68x the limit — rising to 288 µA at the `CRITICAL` point. That is
why R26 changed. A 33 kΩ divider was evaluated and rejected: with the NTC shorted,
3.33 V / 32.67 kΩ = 101.9 µA already exceeds the limit, and it crosses 100 µA at 119.4 °C
— inside the part's −40…+125 °C range. The selected **100 kΩ** divider's worst case is
**33.6 µA = 33.6%** of the limit — a 2.97x margin that holds at every temperature and
under a shorted-thermistor fault (`V3P3` max 3.33 V, R26 min 99 kΩ at 1%). Self-heating
at 25 °C is now 9.0 µW (30.0 µA through 10 kΩ), roughly 0.009 °C against the 1 mW/°C
typical dissipation constant — self-heating was never the binding constraint; the 0.1 mA
operating maximum is, and the outgoing divider exceeded it by 68% while this page
reported comfort against a rating that does not govern.

Three caveats apply to the table above:

- **Sample time.** The ADC channel must use the **160.5-cycle** sample time. Worst-case
  source impedance (R26 in parallel with the NTC, at R26's maximum) is 43.8 kΩ at
  −20 °C against the datasheet's 50 kΩ allowance at that sample time; the allowance is
  exceeded below about −25 °C, so **the sensing chain's stated validity floor is −20 °C
  at RT1**. C24's 100 nF supplies the sampling charge, so this is a conservative
  requirement, not a hard functional limit for an indoor lamp.
- **Resolution.** 104 − 69 = 35 counts across the 15 °C derate band = 2.37 counts/°C,
  i.e. **0.42 °C per LSB**. This is 7.1x coarser than the outgoing 10 kΩ divider
  (16.7 counts/°C) — adequate for a thermal roll-off, but a real cost of the change and
  stated here rather than buried.
- **Beta-only conversion.** Every resistance-vs-temperature value in the table above is
  computed from the NTC's 10 kΩ ±1% at 25 °C and its B25/50 = 3380 K ±1%, not from a
  guaranteed manufacturer R–T table (none exists for this exact part). Tolerance alone
  gives ±0.75 °C of uncertainty at the `CRITICAL` point, and substituting the typical
  B25/85 = 3434 K moves the same point a further ≈1 °C — so **the trip temperatures
  carry roughly ±2 °C of model uncertainty and are nominal design points, not
  guaranteed trip temperatures.**

The divider is fed from `V3P3`, and the ADC reference (VDDA) is also `V3P3`, so the
conversion is **ratiometric** — the ADC code depends only on the resistance ratio, and
rail tolerance cancels out of the threshold. Rail tolerance still matters for the
*current* envelope above, because that math is not ratiometric; that is why the
threshold table carries no rail-tolerance column while the current figures do. The
derate function is
[control-safety's](/docs/research/control-safety/#fault-handling-sketch-over-temperature-derating-hook)
unchanged.

## Net-connectivity table

Complete pin coverage for every active device. STM32G031F8P6 pin numbers are from ST
DS12992 Rev 4 Table 12 (TSSOP20 column); AL8860 from Diodes DS39014 Rev 5; AP63203 from
Diodes DS41326 Rev 3.

### Power input and protection

| Net | Connected pins (Ref.Pin) | Note |
|---|---|---|
| `VBUS_L` | `J2.1 J2.2 F1.1` | Both paired power contacts converge on the PPTC |
| `V15_FUSED` | `F1.2 SW2.2` | Fused positive feed to the slide-switch common |
| `V15` | `SW2.1 D10.cathode C10.1 C11.1 U2.VIN(8) RS1.1 D11.cathode C12.1 C13.1 U4.VIN(3) C14.1` | The board's 15 V rail. D10 = second SMAJ20A local to Board L, protecting the local converter input; actual transient qualification remains open |

### LED driver (U2, AL8860MP-13, MSOP-8EP)

| Net | Connected pins (Ref.Pin) | Note |
|---|---|---|
| `V15` | `U2.VIN(8) RS1.1 C12.1 C13.1 D11.cathode` | C12 10 µF bulk + C13 100 nF HF, both close to pin 8 |
| `SET` | `U2.SET(1) RS1.2 L1.1` | High-side sense node. RS1 = 200 mΩ between `V15` and `SET`; `I_LED = 0.1/Rs` |
| `LED_P` | `L1.2 R30.1 R31.1 R32.1 R33.1 R34.1 R35.1 R36.1 R37.1` | Array anode rail after the inductor |
| `LED_N` | `U2.SW(5) U2.SW(6) D11.anode LED3.K LED6.K LED9.K LED12.K LED15.K LED18.K LED21.K LED24.K` | **Switching node** — common cathode of all 8 strings. Keep this copper compact |
| `CTRL` | `U2.CTRL(4) R20.2 R21.1 C21.1 TP1.1` | Analog dim input + soft-start cap. TP1 is a bare test pad — Gates 3 and 4 both require probing this node |
| `GND` | `U2.GND(2) U2.GND(3) U2.EP C12.2 C13.2` | EP is a thermal pad — tie to the ground pour, do **not** use it as the electrical return path (DS39014 pin description) |
| No-connect | `U2.NC(7)` | Leave floating |

### LED array (8 strings x 3 series)

Strings are numbered 1–8; LEDs `LED1`–`LED24` in order, so string *n* holds
`LED(3n−2)`, `LED(3n−1)`, `LED(3n)`.

| Net | Connected pins (Ref.Pin) | Note |
|---|---|---|
| `LED_S1_A` | `R30.2 LED1.A` | String 1 anode, after ballast |
| `LED_S1_M1` | `LED1.K LED2.A` | String 1 internal node |
| `LED_S1_M2` | `LED2.K LED3.A` | String 1 internal node |
| `LED_S2_A` | `R31.2 LED4.A` | String 2 — pattern repeats for strings 2..8 |
| `LED_S2_M1` | `LED4.K LED5.A` | |
| `LED_S2_M2` | `LED5.K LED6.A` | |
| `LED_S3_A` … `LED_S8_A` | `R32.2 LED7.A` … `R37.2 LED22.A` | Same pattern; ballast R30+n−1 feeds string n |
| `LED_Sn_M1`, `LED_Sn_M2` | `LED(3n−2).K LED(3n−1).A`, `LED(3n−1).K LED(3n).A` | Two internal nodes per string |
| `LED_N` | `LED3.K LED6.K … LED24.K` | All eight string cathodes join the switching node above |
| `NTC_SENSE` | `RT1.1 R26.2 C24.1 U3.PA4(11)` | NTC top; RT1 physically placed among the emitters |
| `GND` | `RT1.2 C24.2` | |

### Logic rail (U4, AP63203WU-7, TSOT-23-6)

| Net | Connected pins (Ref.Pin) | Note |
|---|---|---|
| `V15` | `U4.VIN(3) C14.1` | C14 = 10 µF input cap |
| `SW_LOGIC` | `U4.SW(5) C15.1 L2.1` | Switching node, L2 = 4.7 µH |
| `BST` | `U4.BST(6) C15.2` | C15 = 100 nF bootstrap, SW to BST |
| `V3P3` | `U4.FB(1) L2.2 C16.1 C17.1 U3.VDD(4) C18.1 C19.1 RV1.3 R24.1 R25.1 R26.1 J3.4` | Fixed-output part — FB ties directly to the output, no divider (DS41326 §9) |
| `GND` | `U4.GND(4) C14.2 C16.2 C17.2` | C16/C17 = 2 x 22 µF per DS41326 Table 2 |
| No-connect | `U4.EN(2)` | Left open for automatic startup — internal current source and 1.18 V threshold per DS41326 Figure 3 |

### MCU (U3, STM32G031F8P6, TSSOP-20), all 20 pins

| Pin | Pin name | Net | Function |
|---|---|---|---|
| 1 | PB7 / PB8 | — | Unused, leave floating (configure as analog input in firmware) |
| 2 | PB9 / PC14-OSC32_IN | — | Unused, no external crystal (HSI16 + PLL to 64 MHz) |
| 3 | PC15-OSC32_OUT | — | Unused |
| 4 | VDD / VDDA | `V3P3` | Supply and ADC reference. `C18` 100 nF + `C19` 1 µF adjacent |
| 5 | VSS / VSSA | `GND` | |
| 6 | PF2-NRST | `NRST` | `C20` 100 nF to GND, and `J3.3` for the programmer |
| 7 | PA0 | `BRIGHT_ADC` | ADC_IN0 — absolute brightness |
| 8 | PA1 | NC | Unused |
| 9 | PA2 | `UART_TX` | USART2_TX → `J4.1` debug pad |
| 10 | PA3 | `UART_RX` | USART2_RX → `J4.2` debug pad |
| 11 | PA4 | `NTC_SENSE` | ADC_IN4 — thermistor divider |
| 12 | PA5 | `PDOK` | GPIO input, 10 kΩ pull-up (`R24`) — informational only |
| 13 | PA6 | `PWM_DIM` | TIM3_CH1 — 20 kHz PWM into the RC filter |
| 14 | PA7 | `ATT` | GPIO input, 10 kΩ pull-up (`R25`) — spare |
| 15 | PB0 / PB1 / PB2 / PA8 | — | Unused |
| 16 | PA11 [PA9] | — | Unused |
| 17 | PA12 [PA10] | — | Unused |
| 18 | PA13 | `SWDIO` | → `J3.1` |
| 19 | PA14-BOOT0 / PA15 | `SWCLK` | → `J3.2`. Boot source depends on the programmed option bytes (`nBOOT_SEL`/`nBOOT0`/`nBOOT1`), not on this pin alone — a blank device boots system memory regardless of BOOT0's state. No external pull is fitted; PA14/BOOT0 is sampled on NRST rising and shares this package pin with PA15/SWCLK. The resolved boot-mode selection is an open programming artifact — see [#46](https://github.com/Takazudo/zudo-led-lamp/issues/46) |
| 20 | PB3 / PB4 / PB5 / PB6 | — | Unused |

:::note[Multiplexed package pins]
TSSOP-20 bonds several die pads to one package pin (pin 1 = PB7+PB8, pin 2 = PB9+PC14,
pin 15 = PB0+PB1+PB2+PA8, pin 19 = PA14+PA15, pin 20 = PB3..PB6). This is normal for
STM32 low-pin-count packages. It matters here only for pin 19: SWCLK (PA14) shares the
pin with PA15, so PA15 must never be configured as an output in firmware.
:::

### Control and interface nets

| Net | Connected pins (Ref.Pin) | Note |
|---|---|---|
| `PWM_DIM` | `U3.PA6(13) R20.1` | 20 kHz PWM out |
| `CTRL` | `R20.2 R21.1 C21.1 U2.CTRL(4) TP1.1` | Filtered DC, 0 to 2.53 V |
| `BRIGHT_WIPER` | `RV1.2 R27.1` | Potentiometer wiper |
| `BRIGHT_ADC` | `R27.2 R22.1 C22.1 U3.PA0(7)` | 100 Ω series, 100 kΩ pull-down, 100 nF shunt |

| `PDOK` | `J2.4 R24.2 U3.PA5(12)` | R24 10 kΩ pull-up — Board P drives this open-drain |
| `ATT` | `J2.3 R25.2 U3.PA7(14)` | R25 10 kΩ pull-up |
| `NTC_SENSE` | `RT1.1 R26.2 C24.1 U3.PA4(11)` | R26 100 kΩ divider top to `V3P3` |
| `NRST` | `U3.PF2-NRST(6) C20.1 J3.3` | |
| `SWDIO` | `U3.PA13(18) J3.1` | |
| `SWCLK` | `U3.PA14(19) J3.2` | |
| `UART_TX` | `U3.PA2(9) J4.1` | |
| `UART_RX` | `U3.PA3(10) J4.2` | |

### Ground

| Net | Connected pins (Ref.Pin) |
|---|---|
| `GND` | `J2.5 J2.6 D10.anode C10.2 C11.2 C12.2 C13.2 U2.GND(2) U2.GND(3) U2.EP C14.2 U4.GND(4) C16.2 C17.2 U3.VSS(5) C18.2 C19.2 C20.2 R21.2 C21.2 C22.2 C24.2 RT1.2 RV1.1 R22.2 J3.5 J4.3` |

RV1 has four dummy/support terminals, all electrically unconnected.

### Connectors and pad groups

| Ref | Part | Pins | Note |
|---|---|---|---|
| `J2` | PM254V-11-06-H85 female, C2832269 | 6 | Direct mate for Board P's PZ254V-11-06P male `JOUT1`; mirrors its pin map exactly — see [Board P](./board-p.mdx#jout1-pin-assignment-locked) |
| `J3` | 1x5, 2.54 mm | SWDIO, SWCLK, NRST, 3V3, GND | **Footprint only.** Hand-fit a pin strip for bring-up; not in the assembly BOM |
| `J4` | 1x3, 2.54 mm | TX, RX, GND | Footprint only |
| `RV1` | RK10J11E0034 / C470643 | 1 endpoint, 2 wiper, 3 endpoint; four isolated supports | Rear stopped potentiometer |

## What the design review changed (2026-08-01)

This historical review predates the RV1 replacement; its encoder-specific changes are superseded.
An independent electrical review confirmed the then-captured netlist matched this page
pin-for-pin (including all 24 LED polarities and all four IC pinouts against their
datasheets) and made these changes, reflected above:

1. **Ballast R30–R37: 1206 250 mW → 2512 1 W** (C2934070). The old part exceeded its
   rating at the design's own worst-case string current.
2. **R27/R28 100 Ω added in series with the encoder phases.** C22/C23 otherwise
   discharge into the EC11 contacts on every closure — a contact-erosion fix that
   costs one Basic line.
3. **TP1 test pad added on `CTRL`.** Gates 3 and 4 both mandate measuring this node;
   it previously had nothing to probe.
4. **Duty-cycle figures corrected** (77% nominal, not 74%) and the **pulse-skip
   flicker risk at deep dimming** documented with a Gate-4 check.
5. **`LED_P` acknowledged as a switching node** — the whole LED array switches, and
   the layout guidance now says so.
6. An **open-string cascade** note: the driver holds *total* current, so each open
   string raises the survivors' share. See the corrected numbers below — the original
   "one open is tolerable" reading used nominal mean current and does not survive the
   datasheet worst case.

### Open-branch cascade — one open LED already exceeds the absolute maximum

The AL8860 regulates **total** current, so an open branch does not reduce output — it
redistributes. Re-running the published
[`calc-led-hot-branch-peak`](/docs/components/integration/#calc-led-hot-branch-peak) with
the branch count as a free parameter (same model, same retained inputs, hot branch at
minimum ballast tolerance and the rest at maximum):

| Branches | Vf spread | Hot branch, peak | vs 90 mA abs max | Hot branch, mean | vs 90 mA |
|---|---|---|---|---|---|
| 8 (intact) | 0 V | 80.18 mA | 89.1% | 66.81 mA | 74.2% |
| 8 (intact) | 0.30 V | 88.19 mA | 98.0% | 74.83 mA | 83.1% |
| **7 (one open)** | **0 V** | **91.60 mA** | **101.8%** | 76.33 mA | 84.8% |
| **7 (one open)** | **0.30 V** | **99.45 mA** | **110.5%** | 84.18 mA | 93.5% |
| 6 (two open) | 0.30 V | 114.44 mA | 127.2% | 96.64 mA | 107.4% |
| 5 (three open) | 0.30 V | 135.41 mA | 150.5% | 106.74 mA | 126.7% |

**One open LED already puts the survivors over the 90 mA absolute maximum on a peak
basis**, even with perfectly matched strings — the earlier "1 open → 71 mA/string" figure
was the nominal *mean* (500/7), not the datasheet worst-case peak, and understated it.
On a mean basis one open is still inside the limit (84.8–93.5%), so the failure mode is
accelerated ageing of the survivors, not immediate loss.

The AL8860's open-load protection does **not** help: it acts only when the entire LED
path opens ([`fact-al8860-faults`](/docs/components/records/al8860mp-13/#fact-al8860-faults)).
One branch of eight is still a valid load, so regulation simply continues at the same
total current. Raising the ballast does not help either — total regulated current is
unchanged.

The only real mitigations are lowering the total setpoint (RS1 240 mΩ gives ~417 mA and
holds the seven-branch worst case to 84.18 mA, at the cost of ~17% brightness and a new
BOM line) or per-branch current limiting. **Neither is applied**: this is a post-fault
condition on a lamp that is already visibly degraded, and the normal-operation headroom
it shares a root cause with is the open decision tracked in
[#52](https://github.com/Takazudo/zudo-led-lamp/issues/52). Recorded here so the number is
not lost; the setpoint decision belongs to that issue.

## Power budget

Against the 45 W / 3.0 A PD contract cap.

| Item | Voltage | Current | Power |
|---|---|---|---|
| LED array (24 emitters, 8 x 3s) | 9.0 V/string | 500 mA total | **4.50 W** |
| Ballast resistors (8 x 33 Ω) | 2.06 V | 500 mA | **1.03 W** |
| AL8860 conversion loss (η = 92% assumed) | — | — | 0.48 W |
| *LED channel input* | 15 V | 401 mA | *6.01 W* |
| Logic rail output (3.3 V, 25 mA worst case) | 3.3 V | 25 mA | 0.083 W |
| AP63203 loss (η ≈ 75% at this light load) | — | — | 0.028 W |
| *Logic rail input* | 15 V | 7.4 mA | *0.11 W* |
| F1 PPTC (90 mΩ typical) | — | 409 mA | 0.02 W |
| **Board L total** | 15 V | **409 mA** | **6.14 W** |
| Board P — Q1 conduction (65 mΩ @ V_GS −4.5 V) | — | 409 mA | 0.011 W |
| Board P — U1 quiescent (160 µA) | 15 V | 0.16 mA | 0.002 W |
| Board P — R11 100 kΩ gate pull-up | 15 V | 0.15 mA | 0.002 W |
| **System total** | 15 V | **~410 mA** | **~6.16 W** |

| Margin | Value |
|---|---|
| Against the 45 W cap | **13.7% used, 7.3x margin** |
| Against the 3.0 A cap | **13.7% used, 7.3x margin** |
| Worst case if Board P's R14 draws continuously (see [the open question](./board-p.mdx#one-number-this-pass-could-not-resolve)) | 6.64 W / 443 mA — **14.8% used, 6.8x margin** |

:::caution[F1's hold-current margin shrinks with ambient temperature]
The 750 mA hold rating is a 25 °C number. The PPTC's own thermal derating table gives
**0.41 A hold at 85 °C** ambient — against this design's ~409–443 mA worst-case load,
that margin can reach zero well before the fuse's own 85 °C ambient limit, let alone the
LED array's warmer local environment. The failure mode is a nuisance trip (the lamp goes
dark, then self-resets after cooling), not damage — F1 is resettable — but this is a real
operating constraint, not a fixed margin, and belongs in any enclosure thermal review.
:::

:::note[The 25 mA logic-rail budget is a load cap, justified against a down-rated inductor]
L2 (FNR4030S4R7MT, [C167874](https://jlcpcb.com/partdetail/C167874)) is rated for
**2.0 A** max-design heating current, but the AP63203's own recommended full-load
envelope wants a 2.7 A inductor (2 A load x the datasheet's 1.35x current headroom) —
primary-confirmed on both sides, a **−0.7 A** margin against that envelope. That gap is
acceptable here only because **this rail's actual draw is 25 mA**, three orders of
magnitude below the 2.7 A envelope the rating gap describes — the justification is load,
not rating, and the 25 mA figure above is the budget cap this design must not exceed. The
R26 NTC-divider change (100 kΩ, up from 10 kΩ) reduces this rail's draw further, by
roughly 135 µA (165 → 30 µA) — far below this table's resolution, so no power-budget
retabulation is needed.
:::

### The binding constraint is thermal, not the contract

The 45 W figure is a ceiling, not a target. Scaling this lamp to use it would mean ~7x
this dissipation inside a closed 3D-printed enclosure with no forced air — which the
[thermal budget](/docs/research/thermal-budget/) page's own numbers say plain FR-4 cannot
shed. **~6 W is the design's real ceiling**, set by board thermals, and the design sits
at it deliberately.

### Dissipation hot spots

| Site | Count | Each | vs limit |
|---|---|---|---|
| LED (nominal) | 24 | 0.19 W | 62% of the 306 mW package rating; ~19% of the ~1 W/site FR-4 guideline |
| LED (hot branch, mean, at the locked 0.30 V spread limit) | 3 | 0.195 W | 64% of the 306 mW package rating — comfortable on this thermal/mean basis |
| Ballast resistor, 2512 1 W | 8 | 0.129 W | 13% nominal; 26% at the 88.19 mA worst-case branch peak, 27% at the LED's 90 mA absolute-maximum rating |
| L1 (33 µH, 310 mΩ) | 1 | 0.078 W | — |
| D11 SS26 | 1 | 0.059 W | — |
| RS1 (200 mΩ, 2 W) | 1 | 0.050 W | 2.5% |
| U2 AL8860 | 1 | ~0.10 W | θJA 56 °C/W → ΔT ≈ 6 °C |
| U4 AP63203 | 1 | ~0.03 W | θJA 89 °C/W → ΔT ≈ 3 °C |

No site exceeds its rating on this thermal (mean) basis, and the two ICs barely warm.
The number to watch is not in this table: it is the **peak-current** comparison in
[current sharing](#led-array-and-the-brightness-number-ballast-and-current-sharing) — even at zero Vf spread the hot
branch's datasheet worst-case peak sits at 89.1% of the LED's 90 mA absolute-maximum
forward current, rising to 98.0% at the locked 0.30 V acceptance limit. That is a
driver-headroom finding, not a thermal one; see
[#52](https://github.com/Takazudo/zudo-led-lamp/issues/52). If a built board shows
visibly uneven strings, the assembly-time acceptance gate is what catches it, not a
bench thermal reading.

## References

- [LED candidates](/docs/research/led-candidates/) — the 2835/5730/COB comparison and the current-sharing analysis
- [Driver ICs](/docs/research/driver-ics/) — the PT4115 / AL8860 / TPS92511 comparison
- [Thermal budget](/docs/research/thermal-budget/) — the 1 W/site FR-4 guideline
- [Logic rail](/docs/research/control-logic-rail/) — the LDO-vs-buck dissipation math
- [MCU candidates](/docs/research/mcu-candidates/) — CH32V003 / STM32 / PY32 and their toolchains
- [Knob candidates](/docs/research/control-knob/) — current stopped-pot selection and historical encoder research
- [Modulation algorithms](/docs/research/modulation-algorithms/) — gamma, flicker thresholds, the three approaches
- [Safe default-OFF](/docs/research/control-safety/) — the hardware-not-firmware principle
- Diodes Incorporated DS39014 Rev 5 (AL8860) and DS41326 Rev 3 (AP63200/1/3/5)
- ST DS12992 Rev 4 (STM32G031x4/x6/x8), Table 12 pin assignment
- Honglitronic B-17-A-0596 Rev A/2 (HL-AM-2835H421W-S1-08-HR3)

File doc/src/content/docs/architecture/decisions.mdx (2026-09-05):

---
title: Decisions — Chosen vs Rejected
description: Every architecture slot recorded as a decision — what was picked, what was rejected, and the reason, traced back to the power and research pages.
sidebar_position: 50
---

One row per slot. "Rejected" here means *considered and not chosen*, not *bad* — most of
the rejected options are perfectly good parts that lost on one specific axis.

## Board topology

| | |
|---|---|
| **Chosen** | Two boards: Board P (USB-PD front end) + Board L (driver, control, LED array) |
| **Rejected** | Three boards, with the LED array on an aluminum MCPCB daughterboard |
| **Rejected** | One combined board |

Board P must be separate — it is a reusable switched-15 V sink module and its
[bring-up sequence](/docs/power/lessons-from-zudo-pd/#standalone-board-p-bring-up-sequence)
requires testing it completely alone before anything is attached.

The MCPCB daughterboard was rejected on the [thermal budget](/docs/research/thermal-budget/)'s
own numbers: that page puts the plain-FR-4 ceiling at roughly **1 W per LED site** and
reserves metal core for the concentrated-COB case (3.6 W in one 13.4 mm package). This
design runs **0.19 W per site**. A third board would buy nothing thermally and would cost
a second interconnect carrying the driver's ~440 kHz switching node down a wire harness.

The split boundary is still designed in — the array is a self-contained block on four
nets (`LED_P`, `LED_N`, `NTC_SENSE`, `GND`) — so the enclosure phase can lift it onto a
daughterboard later without touching anything else.

## LED

| | |
|---|---|
| **Chosen** | `HL-AM-2835H421W-S1-08-HR3` ([C210315](https://jlcpcb.com/partdetail/C210315)), 3000 K, 24 pieces, 8 parallel strings of 3 series, 62.5 mA per string |
| **Rejected** | CXA1304 COB (C510489 / C510492 / C510494) |
| **Rejected** | SMD5730 family (C2843887, C210353, C210346) |
| **Rejected** | Cool-white 2835 (C2843876, C210329) |

**CCT decided it.** This is a fire/candle lamp; 3000 K warm white is the aesthetic
requirement, and it is the only place a warm bin coincides with real JLCPCB stock
(399,813 units). Every 5730 candidate is 4000 K or cooler, which reads as daylight, not
flame.

The COB was rejected twice over: **all three CXA1304 SKUs show zero stock**, and at 3.6 W
in one package it would force the MCPCB the board split just rejected. The
stock-available fallback ([C22398559](https://jlcpcb.com/partdetail/C22398559)) has a
scanned datasheet with no machine-readable Vf or flux data — not something to design a
thermal budget around.

**3-series, not 4-series.** [Headroom analysis](/docs/research/led-candidates/#voltage-headroom-analysis)
called 4s "tight". Against this part's datasheet Vf ceiling of 3.2 V, a 4s string is
12.8 V, putting the buck at **~88% duty** by the datasheet's own equations — far outside
the AL8860's recommended 25–75% DSW band. 3s plus ballast lands at **77%**: 2 points
above the band rather than inside it, and far below the 98% DSW(MAX). See
[Board L](./board-l.mdx#al8860-constant-current-driver) for the worked figures — the
older 85%/74% pair used `Vout/Vin` without the diode and resistive terms.

## Current sharing between parallel strings

| | |
|---|---|
| **Chosen** | Per-string ballast resistors, 33 Ω 2512 FOJAN FRC2512F33R0TS ([C2934070](https://jlcpcb.com/partdetail/C2934070)); generator evidence places R30–R37 one per branch, while the primary specification gives 1 W nominal power and a calculated 5.745 V RCWV at 33 Ω |
| **Rejected** | One CC driver per string |
| **Rejected** | Vf-binned procurement, no ballast |

[led-candidates](/docs/research/led-candidates/#current-sharing-considerations-for-parallel-strings)
lists exactly these three. One driver per string means **eight** AL8860s and eight
complete passive sets on a board whose entire output is 5.5 W — absurd. Vf-binned
procurement is a supply guarantee the JLCPCB catalog cannot make.

Ballast costs **1.03 W (19% of delivered power)** and that is the honest price of the
choice. What it buys: strong sharing within a matched lot — not unconditional safety. At
the datasheet's full 2.6–3.2 V Vf window the hottest branch would still reach 142.5% of
the LED's 90 mA absolute maximum, which is why incoming lots are gated on the ≤0.30 V
string-spread acceptance bound (issue #35); within that bound the datasheet worst-case
branch peak stays at 98% of the absolute maximum (see board-l's current-sharing analysis
against the primary-confirmed 306 mW limit).

33 Ω specifically is a two-sided optimisation: larger ballast improves sharing but pushes
the duty cycle further past the driver's recommended band; smaller ballast does the
reverse. 33 Ω puts nominal duty at **77%** — accepted 2 points above the 25–75% DSW band
for the sharing it buys. It is **not** "the largest value that keeps duty under 75%": no
ballast value on this rail does that, because 3s alone is already at 69–81% across the
Vf bin. If Gate 4 shows a duty-band problem, 22 Ω pulls nominal to ~72% at the cost of
~40% worse current sharing.

## LED driver IC

| | |
|---|---|
| **Chosen** | `AL8860MP-13` ([C500782](https://jlcpcb.com/partdetail/C500782)) |
| **Rejected** | PT4115 ([C347356](https://jlcpcb.com/partdetail/C347356)) |
| **Rejected** | TPS92511 ([C114277](https://jlcpcb.com/partdetail/C114277)) |

### Driver input rating vs a conditioned clamp screening point

The [driver research](/docs/research/driver-ics/#rail-constraint-a-conditioned-tvs-screening-point)
screened each candidate against the SMAJ20A's **32.4 V** table point. That point is
specified only at 12.3 A, a 10/1000 µs pulse, and 25 °C; it is a conservative
selection reference, not a prediction or universal ceiling for the installed rail.
The [ratings matrix](/docs/power/ratings-matrix/) keeps the actual waveform open, and the
same screening point is published canonically as
[`fact-high-diode-smaj20a-clamp`](/docs/components/records/high-diode-smaj20a/#fact-high-diode-smaj20a-clamp)
with its exact conditions attached.

| Candidate | VIN operating | VIN absolute max | Against the conditioned 32.4 V screening point |
|---|---|---|---|
| PT4115 | 6–30 V | not confirmable from a primary datasheet in the research pass | Does not cover the screening point; no confirmed absolute-max fallback |
| **AL8860** | 4.5–**40 V** ([`fact-al8860-vin-recommended-max`](/docs/components/records/al8860mp-13/#fact-al8860-vin-recommended-max)) | **42 V** (DS39014 Rev 5, [`fact-al8860-vin-absolute-max`](/docs/components/records/al8860mp-13/#fact-al8860-vin-absolute-max)) | Covers the screening point by 7.6 V operating / 9.6 V absolute |
| TPS92511 | 4.5–65 V | — | Covers the screening point with the widest margin |

PT4115 is rejected by this conservative screening rule, not because 32.4 V has been
proven as the installed rail waveform. AL8860 provides more static headroom at the same
cost, while the actual transient still requires the source-impedance, parasitic,
simulation, and bench evidence tracked in issue #34.

TPS92511 offers more static voltage headroom, but was rejected on two counts: its 500 mA maximum
sits exactly at this design's operating current with **zero headroom**, and the research
pass could not confirm its IADJ formula or its full passive count from a primary
datasheet, so it is not schematic-ready. The AL8860 is characterised end to end.

The AL8860 also brought the decisive control-side property nobody was looking for: a
CTRL pin with a **guaranteed 5–100% analog dimming range**
([`fact-al8860-ctrl`](/docs/components/records/al8860mp-13/#fact-al8860-ctrl)), which is what made
flicker-free dimming possible (see below).

The cross-component behaviour of the whole driver stage — the sense resistor, inductor,
catch diode, ballast and LED envelope together — is published as
[`rule-al8860-led-stage`](/docs/components/integration/#rule-al8860-led-stage), including the exact statement of
what it refuses to promote to a PASS.

## Driver passive set

| Slot | Chosen | Reasoning |
|---|---|---|
| Sense resistor RS1 | 200 mΩ 2512 ([C459674](https://jlcpcb.com/partdetail/C459674), [record](/docs/components/records/rlp25feer200/)) | `I = 0.1/Rs` → exactly 500 mA. 50 mW on a 2 W part |
| Inductor L1 | 33 µH ([C177245](https://jlcpcb.com/partdetail/C177245), [record](/docs/components/records/fxl0630-330-m/)) | ~440 kHz switching, 1.69 µs on-time (above the 500 ns minimum), 2.1 A max-design Isat against 0.6 A peak |
| Catch diode D11 | SS26 60 V ([C7420363](https://jlcpcb.com/partdetail/C7420363), [record](/docs/components/records/ro-ss26/)) | Rejected SS24 (40 V) — it leaves zero margin against the AL8860's own 40 V input ceiling for a negligible price difference, exactly as the [driver research](/docs/research/driver-ics/) argued |
| Input caps | 10 µF 1206 + 100 nF 0603 | Datasheet asks 10 µF or higher X7R; see the [X5R deviation note](./bom.mdx#extended-part-fee-economics) |

## Logic rail

| | |
|---|---|
| **Chosen** | `AP63203WU-7` ([C780769](https://jlcpcb.com/partdetail/C780769)) — 3.3 V fixed synchronous buck |
| **Rejected** | HT7333-1 LDO ([C5451671](https://jlcpcb.com/partdetail/C5451671)) |
| **Rejected** | AMS1117-3.3 LDO ([C6186](https://jlcpcb.com/partdetail/C6186)) |
| **Rejected** | XL7015E1 buck ([C73013](https://jlcpcb.com/partdetail/C73013)) |

This is the one place where this pass **overrides** a research recommendation. The
[logic-rail page](/docs/research/control-logic-rail/) says an LDO is fine below ~30 mA,
and the actual budget is ~25 mA, so on dissipation grounds the LDO wins.

The rail envelope overrules it. AMS1117's 15 V absolute maximum leaves no operating
margin at the *nominal* rail voltage—an absolute maximum is not an operating target.
HT7333's 18 V ceiling has little transient headroom. As a conservative screen, it also
sits **14.4 V under** SMAJ20A's conditioned 32.4 V table point; that subtraction does
not predict the installed waveform, but it exposes evidence that the LDO choice cannot
close.

AP63203's absolute maximum is **35 V DC and 40 V for 400 ms** (DS41326 Rev 3). Its
static limits cover the conditioned 32.4 V screening point, so it is the strongest
candidate and costs about $0.60 plus three passives. This does not make the real clamp
event zero-risk: source impedance, waveform, effective capacitance, layout, and bench
behavior remain open.

XL7015E1 has still more static voltage headroom (80 V), but needs a feedback divider and a
150 kHz-class inductor whose researched candidate showed only **238** units in stock.
AP63203 is fixed-output, needs no divider, and its inductor is a 250,000-unit part.

## MCU

| | |
|---|---|
| **Chosen** | `STM32G031F8P6` ([C529334](https://jlcpcb.com/partdetail/C529334)), TSSOP-20 |
| **Rejected** | CH32V003F4P6 ([C5187096](https://jlcpcb.com/partdetail/C5187096)) |
| **Rejected** | PY32F002AF15P6TU ([C5292059](https://jlcpcb.com/partdetail/C5292059)) |
| **Rejected** | STM32C011F4P6TR ([C7373263](https://jlcpcb.com/partdetail/C7373263)) |

The [MCU research](/docs/research/mcu-candidates/) frames this as cost versus toolchain
friction and calls it "a preference call, not a technical blocker". At prototype
quantity the cost axis is noise: the whole spread is about **$1**, against ¥8,460 of
Extended-part setup fees. Toolchain friction, by contrast, is paid in hours during
bring-up.

So the decision is toolchain-first, and STM32 wins that axis by the research's own
assessment ("best-supported path on macOS by a clear margin" — official vendor tools,
Homebrew, OpenOCD, and PlatformIO all first-class, no community forks).

CH32V003 is rejected specifically on its **proprietary single-wire SDI** debug interface,
which only WCH-LinkE programmers speak. A one-vendor-probe dependency is a real cost on a
board that will be debugged interactively.

G031 over C011 for **64 KB flash versus 16 KB**: it keeps the recorded-flame LUT
modulation approach reachable without a board respin, for about $0.40. Hardware headroom
that removes a future respin is cheap at this price.

## Knob

**Current choice (2026-09-06): ALPS RK10J11E0034 / C470643**, single-unit 10 kΩ
±30%, 270°±10° travel with physical stops. It replaces the tall EC11 encoder and
provides absolute brightness position. The earlier encoder decision used the stock
information then available; it is superseded by this stocked low-profile wheel.

Use PA0 ADC_IN0, R27 100 Ω, R22 100 kΩ pull-down and C22 100 nF. Calibrate and
average ADC input, verify installed direction, and ramp from dark to the position
after valid PD/thermal checks. Do not restore the old fixed 40% startup target.

## Control scheme

### What the knob controls

| | |
|---|---|
| **Chosen** | **Base brightness** |
| **Rejected** | Speed |
| **Rejected** | Depth |
| **Rejected** | Mode-cycled combination via a push-button gesture |

Three reasons, in order of weight:

1. **A lamp knob that does not change brightness is a surprise.** Every other mapping
   requires the user to learn the device.
2. **Brightness is the parameter with a safety meaning.** Turning it down is also turning
   down heat, and turning it fully down is off. Speed and depth have no such property,
   and neither does a mode-cycled knob whose current mode is invisible.
3. **The selected potentiometer has no mode button.** The stopped absolute wheel
   controls brightness directly; no gesture is needed.

Speed and depth become firmware constants. They want tuning against the real diffuser
anyway — which does not exist yet, because the enclosure is out of scope — so freezing
them in firmware costs nothing now and is a one-line change later.

### Dimming method

| | |
|---|---|
| **Chosen** | **Analog dimming** — 20 kHz MCU PWM, RC low-passed to a DC level on CTRL |
| **Rejected** | Direct PWM on CTRL |

The AL8860 datasheet recommends PWM below **500 Hz** for good dimming resolution. The
[modulation research](/docs/research/modulation-algorithms/#pwm-carrier-frequency-choice)
puts the peripheral-vision flicker threshold near **300 Hz**. A 500 Hz carrier clears
that by 1.7x — thin for a lamp that is deliberately meant to be seen out of the corner of
the eye, and raising the carrier is exactly what the datasheet says degrades accuracy.

Analog dimming dissolves the conflict: LED current never chops, so there is no flicker
frequency at all, and no PWM modulation of the inductor to become an audible whine. The
datasheet's guaranteed **5–100%** analog range (20:1) is ample for a flame effect.

:::note[This is not free]
Analog dimming cannot reach true zero gracefully — below 5% of I_NOM the AL8860 is
outside its guaranteed range, so the effect bottoms out at a ~35 lm glow and then steps
to hard off. For a flame this is arguably right; for a design that needed a smooth fade
to black it would be the wrong choice. Recorded here so the constraint is not
rediscovered as a bug.
:::

The 20 kHz carrier is chosen to sit above the audio band entirely and to give the
208 Hz RC filter 40 dB of attenuation. It is an MCU-side frequency only — it never
reaches the driver as a switching signal.

### Modulation algorithm

| | |
|---|---|
| **Chosen** | Two layers of one-pole low-pass-filtered noise (slow "breathing" + faster "flicker"), summed |
| **Rejected** | Single-layer filtered noise |
| **Rejected** | LUT playback of recorded flame data |

[modulation-algorithms](/docs/research/modulation-algorithms/)
notes that layering 2–3 filtered-noise generators "adds realism at the cost of a bit more
CPU/RAM" — on a 64 MHz Cortex-M0+ running a 50 Hz animation loop, that cost is
unmeasurable, so take the realism. The bounded-random-walk approach's character is folded
into the slow layer rather than kept as a separate mode.

The LUT approach is rejected because **the dataset does not exist.** It needs a real
flame's luminance curve extracted from video, which is a separate project. The G031's
64 KB of flash keeps the door open for it.

### Safe default-OFF

| | |
|---|---|
| **Chosen** | 33 kΩ pull-down on CTRL **plus** the 100 nF filter cap doubling as a 150 ms soft-start |
| **Rejected** | Firmware-only default-off |
| **Rejected** | MCU internal pull-down alone |

[control-safety](/docs/research/control-safety/) is unambiguous that this must be a
hardware guarantee. The wrinkle the research could not know — because the driver was not
picked yet — is that the AL8860's CTRL pin **floats to ON**, so a pull-down is mandatory
rather than merely prudent.

The 2026-08-01 review argued R21 *is* bounded: the AL8860's soft-start rate (1.5 ms/nF to
charge CTRL) implies an internal bias current of ≤1.67 µA, which into 33 kΩ is ≤55 mV —
3.6x below the 0.2 V off threshold. **That argument currently has no retained fact.**
Neither the 1.5 ms/nF rate nor the ≤1.67 µA bound appears anywhere under
`.claude/skills/component-al8860mp-13/`; the record's only CTRL fact is
[`fact-al8860-ctrl`](/docs/components/records/al8860mp-13/#fact-al8860-ctrl), which gives
the thresholds and the dimming range but no bias current. Under this project's own rule
that `UNSOURCED` evidence cannot close a domain, **mechanism 1 is not closed** and
[Gate 3](./next-steps.mdx#bring-up-sequence-gate-3-—-board-l-power-section-alone-mcu-unprogrammed)'s CTRL
measurement is a real gate, not a confirmation.

The soft-start capacitor is the mechanism that stands on its own: the driver
physically cannot reach full current for 150 ms, and the MCU takes control within about
1–2 ms of power-on reset. Two mechanisms, one of them currently evidence-backed. An MCU
internal pull-down was rejected because it depends on firmware configuring it — which is
the very window being protected.

## Interconnect

| | |
|---|---|
| **Chosen** | Direct XFCN 2.54 mm 1x6 pair: [PZ254V-11-06P male C492405](https://jlcpcb.com/partdetail/XFCN-PZ254V_1106P/C492405) + [PM254V-11-06-H85 female C2832269](https://jlcpcb.com/partdetail/XFCN-PM254V_11_06H85/C2832269), power contacts doubled |
| **Rejected** | JST VH 2-pin ([C160315](https://jlcpcb.com/partdetail/C160315)) plus a signal connector |
| **Rejected** | Molex KK 2510 ([C2847671](https://jlcpcb.com/partdetail/C2847671)) |

The [interconnect research](/docs/research/led-interconnect/) framed the small-header
class's 3 A contact rating against VH's 10 A headroom. That framing assumed the load
was the 3 A contract cap. **It is 410 mA.** Each doubled contact carries 205 mA — 6.8%
of nameplate, a **14x** derated margin. The headroom problem VH exists to solve does not
occur in this design.

The selected direct header pair also fits the six required conductors exactly (2 power +
2 ground + ATT + PDOK) and eliminates the previously unresolved cable housing, crimps,
wire, and completed-harness BOM. Its tradeoff is mechanical: it is unkeyed and requires
reviewed PCB alignment, standoff, and retention.

Molex KK was never a real alternative — the research page includes it explicitly to show
the 3 A-per-contact ceiling is a whole-class property, not an XH quirk.

## Protection

| | |
|---|---|
| **Chosen** | Second SMAJ20A ([C571370](https://jlcpcb.com/partdetail/C571370)) local to Board L's input |
| **Chosen** | PPTC, 750 mA hold / 1.5 A trip / 30 V ([C976305](https://jlcpcb.com/partdetail/C976305)) |
| **Rejected** | Relying solely on Board P's D5 |
| **Rejected** | No fuse (relying on the PD source's 3 A limit) |

The local TVS costs one BOM line already on the order (D5 is the same part) and clamps
transients the ~30 cm harness can develop on its own inductance — the whole point of the
[TVS margin rule](/docs/power/lessons-from-zudo-pd/#tvs-margin-rule) is to clamp close to
what you are protecting.

The PPTC exists because there is a **7x gap between what the source will deliver and what
the board needs**: the PD contract allows 3 A, and Board L draws 410 mA. Without a fuse,
a Board L fault — a shorted LED string, a failed driver — can pull 45 W through a 2.5 mm
harness before anything intervenes. A 750 mA hold bounds that at under 2x the normal
draw.

**Conditioned open point:** the PPTC's 30 V rating
([`fact-bhfuse-voltage-max`](/docs/components/records/bsmd1206-075-30v/#fact-bhfuse-voltage-max)) is
**2.4 V below** the SMAJ20A's
32.4 V table value at 12.3 A, 10/1000 µs, and 25 °C. That subtraction is a useful
screening lead, not an installed-waveform result or an accepted over-rating. Actual
source impedance, clamp current, duration, parasitics, and fuse stress remain part of
the issue #34 simulation and bench gate.

## Summary of open conditioned risks

| Risk | Evidence status | Where |
|---|---|---|
| U1 STUSB4500 VDD, conditioned 4.4 V over its mirror-stated absolute maximum at the D5 table point | **UNSOURCED / waveform OPEN**, not accepted | [ratings matrix](/docs/power/ratings-matrix/), [`calc-stusb-vdd-clamp-overage`](/docs/components/integration/#calc-stusb-vdd-clamp-overage) |
| Q1 exact UMW (Youtai Semiconductor) AO3401A VDS, conditioned 2.4 V magnitude over absolute maximum at that table point | **Waveform OPEN**, not accepted | [ratings matrix](/docs/power/ratings-matrix/), [`calc-q1-vds-clamp-overage`](/docs/components/integration/#calc-q1-vds-clamp-overage) |
| F1 PPTC, conditioned 2.4 V over its 30 V rating at that table point | **Waveform and pulse stress OPEN**, not accepted | this page, above; [`rule-rail-envelope`](/docs/components/integration/#rule-rail-envelope) |
| Duty cycle 81% at the LED bin's Vf maximum, above the AL8860's 25–75% recommended DSW band (guaranteed by design, now primary-confirmed) | steady state, bounded — 98% DSW(MAX) is the hard maximum | [Board L](./board-l.mdx#al8860-constant-current-driver) |
| Even at zero Vf spread, the LED stage's datasheet worst-case peak current sits at 89.1% of the LED's absolute-maximum forward current — 98.0% at the locked 0.30 V acceptance limit | steady state, datasheet-bounded but bench-unverified (the composed peak carries a `NEEDS BENCH` verdict); residual driver-side headroom raised as [#52](https://github.com/Takazudo/zudo-led-lamp/issues/52) | [Board L](./board-l.mdx#led-array-and-the-brightness-number-ballast-and-current-sharing), [`calc-led-hot-branch-headroom`](/docs/components/integration/#calc-led-hot-branch-headroom) |
| R21's ability to hold CTRL low rests on a soft-start-derived ≤1.67 µA CTRL bias bound that **no retained fact carries** — the AL8860 record has no soft-start rate and no bias-current fact | **UNSOURCED**, not closed; Gate 3 (probe TP1) is a real gate, not a confirmation. C21's 150 ms soft-start is the independent mechanism that does stand | [Board L](./board-l.mdx#mcu-knob-and-dimming-path-safe-default-off), this page above |
| The whole Board P topology has never run on hardware | as-built and bench evidence OPEN | [input-protection evidence gate](https://github.com/Takazudo/zudo-led-lamp/issues/34) |

Each of those conditioned figures is published as a calculation on the
[integration page](/docs/components/integration/), with the expression, every input fact, and the conditions under
which the number means anything — so the arithmetic can be recomputed rather than
trusted. These first three rows are conditioned arithmetic, not permission to energize or
call either protected input chain PASS. The current no-PD gate is tracked in
[issue #34](https://github.com/Takazudo/zudo-led-lamp/issues/34).

## Historical toggle decision — superseded by the short slide switch

The previous revision chose **Dailywell 1MS1T1B1M1QES-5 / C496154**, the earlier toggle fallback,
with live JLCPCB stock and wave-solder assembly support verified during planning.
The WR11AS choice on 2026-09-05 used external distributor stock and missed the
JLCPCB sourcing requirement; that decision is superseded.

SW2 mounts on the rear PCB, clear of Board P and the pillars, and cuts the fused
positive feed to both converters. Common 2 feeds pin 1 in ON; pin 3 is unwired
but live in OFF. Board P remains powered. The EC11 retained brightness control in that revision.
Use the exact solder-lug SKU in the reviewed plated-slot footprint and support its
threaded bushing in the enclosure. The old J5 pads and external harness are removed.
See [selection, mounting and qualification](./power-switch.mdx).

## Low-profile controls replace the tall controls (2026-09-06)

The current power control is **G-Switch SS-12D01-G020 / C5446803**, maintained
SPDT rated 1 A at 24 V DC. Common 2 receives V15_FUSED; throw 1 feeds V15;
throw 3 stays isolated on the PCB and becomes live in OFF. The corrected family
model retains the 3.5 mm case, 2 mm actuator and 0.5 mm shoulder, about 6 mm
mounted height. RV1 replaces SW1 with the stopped ALPS wheel. Board P, pillars
and J2 alignment remain fixed; enclosure and soldering fit still need prototypes.

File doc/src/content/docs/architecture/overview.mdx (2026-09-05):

---
title: Prototype Architecture — Overview
description: The locked prototype architecture for the lamp — two lamp boards plus a separate SWD adapter, a 24-LED warm-white array at 500mA, an AL8860 constant-current buck, an STM32G031 control MCU, and a stopped potentiometer mapped to brightness. Decisions, not options.
sidebar_position: 10
---

This section is the **locked prototype architecture**: the thing KiCad work starts
from. Everything here is a decision with a recorded reason that traces back to the
[power](/docs/power/board-p-front-end/) and [research](/docs/research/led-candidates/)
sections. Where those pages enumerated options, this section picks one and says why —
see [Decisions](./decisions.mdx) for the chosen-vs-rejected record.

:::warning[Nothing here is bench-confirmed]
Board P's topology was never validated on working hardware (see
[Lessons Carried From zudo-pd](/docs/power/lessons-from-zudo-pd/)), and Board L is a
new design that has never existed as a PCB. This is a datasheet-grounded paper design.
Treat the first build as the first real test, and follow the bring-up gates in
[Next Steps](./next-steps.mdx).
:::

## Headline numbers

| Parameter | Locked value |
|---|---|
| Lamp board count | **2** — Board P (USB-PD front end) + Board L (driver, LEDs, control); the SWD adapter is a separate service accessory |
| PD contract | 15 V / 3 A (45 W cap) |
| System draw | **~6.2 W, ~410 mA** — 13.7% of the contract cap, **7.3x margin** |
| LED array | **24x** SMD2835 warm white, 8 parallel strings of 3 series |
| CCT / CRI | 3000 K (2800–3100 K bin), CRI Ra ≥ 80 |
| Drive current | **500 mA** total, 62.5 mA per string |
| Light output | **~700 lm typical, ≥620 lm worst-case bin** |
| Driver | AL8860MP-13 constant-current buck, hysteretic, ~440 kHz |
| Logic rail | 3.3 V from an AP63203 synchronous buck |
| MCU | STM32G031F8P6 (Cortex-M0+, 64 KB flash, TSSOP-20) |
| Knob | ALPS RK10J11E0034 stopped potentiometer → **base brightness** |
| Dimming | Analog (RC-filtered 20 kHz PWM into the driver's CTRL pin) — no visible flicker by construction |
| Board L dissipation | ~6.1 W spread over 24 LED sites + 8 ballast resistors — plain FR-4, no MCPCB |

## System block diagram

```mermaid
flowchart TD;
  CHG["USB-C PD charger\n15V PDO required"];

  subgraph BP["Board P — USB-PD front end (existing spec)"];
    J1["J1 TYPE-C-31-M-17\nreceptacle"];
    U1["U1 STUSB4500QTR\nPD sink controller"];
    Q1["Q1 AO3401A\nload switch"];
    D5["D5 SMAJ20A\n20V standoff, 32.4V clamp"];
    J2P["J2/J3 pogo pads\nNVM I2C + debug"];
    JOUT1["JOUT1 PZ254V male 6P"];
    J1 --> U1;
    U1 -->|"VBEN"| Q1;
    D5 --- U1;
    J2P --- U1;
    Q1 --> JOUT1;
    U1 -->|"ATT / PDOK"| JOUT1;
  end;

  subgraph BL["Board L — driver + control + LED array"];
    J2L["J2 PM254V female 6P"];
    F1["F1 PPTC 750mA/30V"];
    V15["15V rail\nD10 SMAJ20A + bulk caps"];
    U2["U2 AL8860MP-13\nCC buck, Rs=200mR"];
    ARR["LED array\n8 strings x 3s\n8x 33R ballast\n24x HL-AM-2835H421W"];
    U4["U4 AP63203WU-7\n3.3V synchronous buck"];
    V33["3.3V logic rail"];
    U3["U3 STM32G031F8P6\nCortex-M0+"];
    RV1["RV1 ALPS 10k pot\nabsolute ADC position"];
    RC["R20 10k + R21 33k + C21 100n\nRC low-pass, 0 to 2.53V"];
    J3L["J3 SWD pads\nJ4 UART pads"];
    J2L --> F1;
    F1 --> SW2["PCB slide switch C5446803\nmaintained ON-OFF"];
    SW2 --> V15;
    V15 --> U2;
    U2 -->|"L1 33uH + D11 SS26"| ARR;
    ARR -->|"NTC RT1 10k"| U3;
    V15 --> U4;
    U4 --> V33;
    V33 --> U3;
    RV1 --> U3;
    U3 -->|"PA6 PWM 20kHz"| RC;
    RC -->|"analog CTRL"| U2;
    J3L --- U3;
    J2L -->|"ATT / PDOK"| U3;
  end;

  CHG -->|"USB-C cable"| J1;
  JOUT1 -->|"switched 15V x2, GND x2, ATT, PDOK"| J2L;
```

## Board split

**Two boards, no LED daughterboard.** Board P must be its own PCB (it is a reusable
switched-15 V sink module, and it has to be bench-brought-up alone before anything is
connected to it). Everything else lands on Board L.

The case for a third board — an LED module on aluminum MCPCB — was evaluated and
**rejected**. The [thermal budget](/docs/research/thermal-budget/) page sets the plain-FR-4
ceiling at roughly **1 W per LED site**; this design runs **0.19 W per site** across 24
sites. That is squarely in that page's "many small sites, generous pour" regime, not the
concentrated-COB regime that forces metal core. A third board would add a second
interconnect carrying the driver's switching node over a cable — a real EMI cost — to
solve a thermal problem this design does not have.

:::note[The split boundary is still designed in]
The LED array is drawn as a self-contained block with a **4-net interface**: `LED_P`
(array anode rail), `LED_N` (common cathode = the driver's switching node), `NTC_SENSE`,
and `GND`. If the later enclosure phase forces the emitters onto a separate plane from
the knob, the array can be lifted onto a daughterboard across exactly those four nets
without touching the rest of Board L. The reason it is not split *now* is the `LED_N`
switching node: running a ~440 kHz, 15 V-swing node down a wire harness is an EMI
problem that only pays for itself if the mechanics actually demand it.
:::

## Interfaces

| Interface | Physical | Nets |
|---|---|---|
| Charger → Board P | USB-C receptacle (J1) | CC1, CC2, VBUS, GND |
| Board P → Board L | Direct XFCN 1x6, 2.54 mm pair: `PZ254V-11-06P` male on Board P and `PM254V-11-06-H85` female on Board L | 1,2 = switched 15 V (paired); 3 = ATT; 4 = PDOK; 5,6 = GND (paired). Unkeyed: verify physical pin-1 alignment before power |
| Board P programming | J2 pogo pads 1x4 (I2C NVM + reset), J3 pogo pads 1x8 (debug) | SCL, SDA, GND, RESET |
| Board L programming | J3 pad group 1x5, 2.54 mm (SWD) | SWDIO, SWCLK, NRST, 3V3, GND |
| Board L debug | J4 pad group 1x3, 2.54 mm (UART) | PA2 TX, PA3 RX, GND |
| Power control | C5446803 slide switch assembled on rear Board L | Fused positive feed / switched V15 return; Board P remains powered |
| User control | ALPS RK10J11E0034 stopped potentiometer, rear low-profile wheel | Endpoints and wiper |

The XH connector's per-contact current math is inherited unchanged from
[Board P's downstream interface](/docs/power/board-p-front-end/#downstream-interface):
3 A/contact nameplate, doubled contacts per rail. Against this design's actual 410 mA
draw that is **14x** derated margin per contact, not the 1.6x the connector was sized
for against the 3 A contract cap. The doubling stays anyway — it costs nothing, it is
already in Board P's spec, and it keeps the harness reusable if a brighter revision
raises the current.

## Lamp power

The [C5446803 slide switch](./power-switch.mdx) turns off the LED driver and MCU supply
by opening Board L’s fused positive feed. Board P remains connected to USB-PD.
The short slide switch is assembled on the rear PCB; ON restarts the MCU after sufficient rail decay; rapid toggles need verification.

## What the knob does

The knob sets **base brightness**, and nothing else. Speed and depth of the fire/wave
modulation are firmware constants. The full reasoning is in
[Decisions](./decisions.mdx#control-scheme); the short version is that a lamp knob that
does not change brightness is a surprise. RV1 has fixed end stops and absolute position;
there is no push-button mode gesture. Firmware must start dark and ramp to the validated
position, with endpoint calibration, averaging and installed-direction verification.

## Where to go next

| Page | Contents |
|---|---|
| [Board P](./board-p.mdx) | Locked front-end spec, full net table, interface pin assignment |
| [Board L](./board-l.mdx) | Driver/control/LED design, full pin-level net table, all component values with worked math |
| [Final BOM](./bom.mdx) | Every part, C-number, tier, stock, and the Extended-fee arithmetic |
| [Decisions](./decisions.mdx) | Chosen vs rejected per slot, with reasons |
| [Next Steps](./next-steps.mdx) | The KiCad phase — bring-up order, footprint pipeline, risks |

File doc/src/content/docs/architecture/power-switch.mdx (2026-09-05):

---
title: Lamp power switch — G-Switch C5446803
description: The short rear slide switch, exact terminal connections, OFF behavior and prototype checks.
sidebar_position: 35
---

The selected switch is **G-Switch SS-12D01-G020 / C5446803**, a maintained SPDT
slide switch on the rear of Board L. It replaces the tall Dailywell toggle. RV1,
the stopped ALPS potentiometer, sets brightness independently.
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

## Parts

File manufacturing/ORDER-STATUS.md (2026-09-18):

# Order placed — 2026-09-19

The user reported the JLCPCB order complete in this session. The retained
manufacturing release is `jlcpcb/2026-09-19/`; no order number or receipt was
provided, and factory acceptance/shipping has not been independently checked.

Board L top/bottom and Board P top placement captures were reviewed in-session.
The user manually rotated Board L RV1 by 180 degrees before sharing its bottom
preview. That correction is now retained in the CPL and future export settings;
the KiCad footprint geometry remains unchanged.

The archive records the local manufacturing data and that reported placement
correction. It is not a downloaded copy of JLCPCB's final factory production data.
Existing warnings and assembly/bring-up considerations remain in the order notes.

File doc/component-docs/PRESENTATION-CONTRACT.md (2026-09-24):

# Component evidence stays readable in native zudo-doc

Presentation contract for [#136](https://github.com/Takazudo/zudo-led-lamp/issues/136),
under [#135](https://github.com/Takazudo/zudo-led-lamp/issues/135). Baseline:
`de6b355107d8b6adaa1a706358fe5c02315f272a`. This contract changes presentation;
the publication policy and evidence remain authoritative and unchanged.

## One new fact primitive earns its place

Add **`EvidenceFact({ children })`**, an SSR component with no authored attributes.
Its children are ordinary Markdown. It groups one fact's ID, value, unit,
conditions, exact verdict, provenance and full citation in reading order. Use a
plain `div.zld-evidence-fact`; do not add a tab stop, landmark, disclosure,
client island, generated heading or hidden data payload. A subtle token-colored
separator and compact paragraph spacing distinguish adjacent facts. Retain native
body typography, links and code styling. Facts form one vertical sequence at all
widths: no masonry, parallel cards or rearrangement of the evidence order.

Keep coverage and sources as Markdown. Keep `EvidenceAnchor`, `EvidenceTable`
and pin-only `EvidenceDetails`. Keep the existing `ComponentReferences` descriptor
API and preview islands for the accepted Documents and package behavior below.
No source popover, coverage widget, new page shell or framework package change.

The new primitive solves a specific repeated problem: a seven-column fact row
separates a value from its conditions, verdict and locator when the content area
is narrow. The primitive's spacing and boundary keep those claims together while
leaving their complete content readable in raw Markdown and static exports.

## The comparisons select visible evidence over horizontal scanning

These are alternatives for the **actual native record route**, with its header,
sidebar and TOC consuming width, not standalone page designs.

| Area | Treatment A | Treatment B | Decision and cost |
| --- | --- | --- | --- |
| Facts and repeated citations | Current seven-column Markdown table in `EvidenceTable`: Fact, Value, Unit, Conditions, Verdict, Provenance, Evidence. A repeated full locator occupies each row's last column. | One `EvidenceFact` per fact: identifier, value/unit, conditions, verdict/provenance, then full linked locator. Class headings remain outside the primitive. | **B.** All of one fact can be read vertically without moving between horizontal scroll positions. More vertical length is acceptable; keep spacing compact and class navigation intact. |
| Citation deduplication | Print a short source ID at each fact and move the locator into source detail, a footnote, or a popover. | Keep the exact locator inline in its fact; link it to the source. Print a separate source ID only when the locator does not already contain it. | **B.** Locators identify different rows/pages in the same source; source-level grouping cannot replace them. Repeated source IDs inside exact locators are retained. No hover dependency or new citation component. |
| Coverage | A table of domain/status/reason/facts/blockers, or bordered `CoverageDomain` cards with the same fields. | Native `###` domain headings; one compact ID/status paragraph; full reason; ordinary lists of fact and blocking links. | **B.** Long reasons need full width; cards repeat structure already supplied by headings and introduce needless wrappers. A wide coverage table makes the critical reason difficult to read on a phone. |
| Sources | Current heading plus ten separate metadata bullets, or a `SourceReference` card taking a descriptor. | Native `###` document title, ID/authority paragraph, a two-column metadata table, full locator paragraph, then availability and document URL together. | **B.** The table aligns short labels while long locator/URL text gets full width. Markdown preserves all content without another descriptor or component API. |

Do not collapse repeated facts across different records or classes. Fact identity,
conditions and ownership determine whether two claims are distinct. The source
list remains complete even when several facts cite the same source or the selected
document shortcut points to just one of several sources.

## Every section has an explicit rendering decision

The table is exhaustive for `landing.ts`, `catalog.ts`, `record.ts` (including the
records index), and `integration.ts`. Examples use the normal Markdown constructs
shown in the next section; they are not new components unless named here.

| Section and reader question | Existing pain; Markdown treatment | Component alternative; decision |
| --- | --- | --- |
| Landing orientation / How to read: what is published? | Long introductory text; retain a short orientation and the existing four distinct evidence explanations as a list. | Intro card: rejected; ordinary prose needs no wrapper. |
| Landing Corpus: how much is published? | Many counts can look like a grade; retain the labeled Item/Count table and non-approval explanation. | Statistic tiles: rejected; they suggest scoring and take more space. |
| Landing Raw agent resources / Sections: where next? | Navigation is separated from the introduction; keep the existing resource link and package `CategoryNav`. | Custom navigation/search: rejected; package navigation remains authoritative. |
| Records index: where is an exact record? | Long list; keep inventory order and subordinate adjacency, linked MPN, exact record ID and function in each item. | Search/filter island: rejected; native search already owns discovery. |
| Catalog How to read / Parts at a glance: compare which states? | Seven wide columns; preserve the complete comparison table in `EvidenceTable label="parts-index"`, exact separate Fit/Identity/Sources/Open domains and denominator. | Per-part cards: rejected for comparison; they scatter the state columns. |
| Catalog full Part entries: exact identity and every placement? | Fourteen bullets per entry obscure scan groups; keep each `###` MPN, then three small labeled Markdown groups: identity; placements and fit; evidence state and links. | Catalog-entry wrapper: rejected; use two-column identity metadata and ordinary state paragraphs/list links. Preserve every old field and both record/resource links. |
| Record orientation / subordinate relation: whose evidence? | Parentage can disappear among metadata; retain explicit subordinate paragraph and linked parent before Identity. | Relationship badge: rejected; cannot replace the explanation or missing-parent state. |
| Identity: which exact orderable? | A long uniform bullet list mixes identity with evidence state; use a two-column Field/Recorded value table for Record ID, kind, MPN, manufacturer, function, LCSC, package, inventory line, aliases and owner. Follow with labeled Fit, Identity state, Source state and Coverage paragraphs. | Identity card: rejected; Markdown already provides label/value alignment. Preserve the absent-LCSC wording and optional-field rules. |
| Documents and package: which document and shared assets? | Current three-column card layout misaligns previews and emits its major heading internally. | **Existing `ComponentReferences`**: accepted full-width document row followed by paired preview stages; see fixed API below. |
| Placements: where is it fitted? | Multiple boards/refdes must not be summarized away; retain the Board/Reference designator table and explicit empty sentence. | Placement chips/map: rejected; no extra interaction helps this small comparison. |
| Coverage: what remains open? | Long repeated metadata and fact lists precede facts; use the selected native heading/paragraph/list treatment. | Coverage cards/table: rejected as above. Coverage remains before Facts. |
| Facts / class gloss: exact claim under which conditions? | Seven-column rows split related claims; preserve class order, `###` class heading and gloss, then **`EvidenceFact`** per fact. | Selected primitive; no one-heading-per-fact TOC explosion. Empty Facts remains explicit. |
| Calculation dependencies: can I recompute it? | Expressions and long cross-record dependencies form wide cells; keep `## Calculation dependencies`, one labeled Markdown block per calculated fact, linked fact ID, exact expression and dependency list. | Calculator / derived-value card: rejected; no evaluation, rounding or recomputation occurs. Preserve current section-presence rules and explicit missing expression/input wording. |
| Pin maps: which symbol/pad mapping? | Dense lookup rows distract; keep map `###` ID, anchor, symbol/footprint/pin count and `EvidenceDetails label="pin-assignments"` around the existing `EvidenceTable`. | New pin viewer: rejected. Native disclosure is allowed only for the assignment table; empty-map/pin wording stays visible. |
| Interactions: what spans records? | Repeated long metadata lists; keep `###` ID, records involved, conditions, exact verdict, and linked fact list. Compact the metadata paragraphs; do not group unrelated interactions. | Interaction card: rejected; these are prose and graph links, with no new behavior needed. |
| Record Cross-component rules: where is the complete refusal? | Verdict could look like record approval; keep existing rule links with domain and exact **rule** verdict, the explanation and full integration link. | Duplicated abbreviated rule card: rejected; full rule/refusal remains on integration page. |
| Sources: what supports these facts? | Ten similar bullet labels per source; use the selected Markdown source layout. | Source descriptor/card: rejected as above. Source availability is distinct from record source state. |
| Record / integration Legend: what do these terms mean? | Long explanatory text is useful reference; retain native subgroup headings and two-column tables derived from terms actually present, including unknown-term fallback. | Tooltip glossary: rejected; definitions must exist in static output. |
| Record / integration Raw agent resource: what is authoritative? | Repeated boilerplate; retain authority explanation and exact owning-bundle links or explicit absence. | Resource card: rejected; a normal link is sufficient. |
| Integration orientation / Rules at a glance: which cross-part question? | Wide state comparison; retain the normal explanatory list and `EvidenceTable label="rules-index"` with all index fields. | Status dashboard: rejected; no aggregate approval exists. |
| Integration rule body: what may be concluded? | A verdict can dominate the qualification; keep `##` rule ID, domain, **verdict immediately followed by refusal**, then conditions, records and fact links. | Rule wrapper/admonition: rejected; exact labeled prose is already prominent and requires no invented severity. |
| Integration conditioned calculations / results: which inputs give which recorded result? | Long conditions and variable cases; keep calculation headings, expression/result key, full conditions/input links and existing result tables. Wider tables retain keyboard-scrollable `EvidenceTable`. | Interactive arithmetic: rejected; recorded values and union of case input keys remain authoritative. |
| Integration source-to-bench chain: which stage has evidence? | Fact-link cells can become dense; keep ordered Stage/Status/Facts table in `EvidenceTable label="evidence-chain"`, shared exact fact links and explicit no-fact wording. | Timeline/progress bar: rejected; implies completion propagates across stages. |

Ordinary prose shortening may remove presentation boilerplate only when its
meaning is retained. Never shorten a recorded condition, reason, locator, refusal,
glossary term or verdict. Do not rename existing major headings except the fixed
Documents and package heading; preserve their current heading-derived links.

## Authors can read the complete claim without decoding props

The following AO3401A fact is copied from the baseline projection to illustrate
shape, not to re-author evidence. Production values always come from the public
view model through existing safe AST builders.

```mdx
---
title: "AO3401A"
---

## Facts

### ABSOLUTE_MAXIMUM

<EvidenceFact>

<EvidenceAnchor id="fact-umw-ao3401a-vds" />

**Fact:** `fact-umw-ao3401a-vds`

**Value:** -30 · **Unit:** `V`

**Conditions:** drain-source absolute maximum, Ta=25 degC

**Verdict:** PASS - primary-source confirmed · **Provenance:** PRIMARY-SPEC

**Evidence:** [src-umw-ao3401a: page 1 absolute maximum table row VDS](#src-umw-ao3401a)

</EvidenceFact>
```

The example's source target is supplied by the source entry on a complete page.
Keep a scalar unchanged. For a structured value, render every key/value pair using
the existing `factValueEntries` / `entryValue` behavior; never stringify it into a
new summary. Preserve `NONE` units. For a calculated locator that lacks the source
ID, use `**Evidence:** [source ID](#source-id) — exact CALCULATED locator`; the
separate Calculation dependencies block retains expression and every dependency.

These generic snippets illustrate the other selected structures. Words such as
“recorded reason” stand for evidence supplied by the renderer, not replacement
wording. Pair heading-derived links with the original stable evidence anchors.

```mdx
## Coverage

### Domain name

<EvidenceAnchor id="cov-example" />

**Coverage ID:** `cov-example` · **Status:** OPEN

**Reason:** The exact recorded reason.

**Facts in this domain:**

- [fact-example](#fact-example)

**Blocked by:**

- [fact-example](#fact-example)

## Sources

### Exact document title

<EvidenceAnchor id="src-example" />

**Source ID:** `src-example` · **Authority:** MANUFACTURER_PRIMARY

| Field | Recorded value |
| --- | --- |
| Document number | Exact recorded number |
| Revision | Exact recorded revision |
| Document date | Exact recorded date |
| Retrieved | Exact retrieval date |
| Printed page | Exact printed label |

**Locator:** Exact source-level locator.

**Availability:** SOURCE UNAVAILABLE

**Document URL:** [https://example.invalid/document.pdf](https://example.invalid/document.pdf)
```

Use the existing explicit no-facts / no-blocker explanation for an open coverage
domain with no recorded blocker. Do not invent a blocker or omit the reason.
For a source with no publishable URL, retain “no link is published for this
source”. Availability and URL are consecutive paragraphs with no intervening
metadata. A valid URL must never be rendered as proof of availability.

Catalog entries reuse the Identity table pattern, followed by `**Placements:**`
with every board/refdes, `**Fit:**`, separate evidence-state labels and existing
part-named links. Calculation dependencies reuse the linked fact paragraph,
`**Expression:**` and a normal `**Depends on:**` list. Interactions and rules reuse
normal labeled paragraphs and the shared fact-reference builder. Landing, counts,
navigation, pins and legends retain their documented Markdown examples in the
current generated pages; no new authoring syntax is required.

## Documents and package retains the accepted API and behavior

The generator emits `## Documents and package` as a real Markdown heading, then
the legacy `<EvidenceAnchor id="component-references-heading" />`, then the
existing `<ComponentReferences descriptor="…" />`. Preserve the historical
`#component-references` target used by the footprint-null fallback as an alias
where that branch exists. The descriptor remains its validated v1 hex encoding;
do not widen it into a container for facts or other ordinary prose.

`ComponentReferences` stops emitting its internal h2 and duplicate heading ID.
It renders the document label/title on the left and authority/availability aligned
on the right when space permits; narrow content stacks them. A second row pairs
footprint and model preview stages with equal stage heights and aligned tops,
stacking at narrow **content** widths. Keep Datasheet PDF / Specification PDF /
Mechanical drawing PDF labels truthful, all selected metadata, package identity
and caveat, and no-JS/error explanations on the page. The footprint-null branch
retains its explicit explanation and source information; it must not manufacture
preview geometry. Selected source fields remain readable in Markdown/LLM output
through ordinary generated content, not only the encoded descriptor.

Enlargement contains only media and an icon close button. Accessible title,
labels and instructions may be nonvisual. No visible title, filename, caption,
status prose, caveat, instruction or “Close” text inside either dialog. Preserve
icon-close, Escape, backdrop dismissal, focus trapping/return, scroll lock, a
single active modal, repeated-open/navigation cleanup, bounded viewport and
initial portrait model fit. Thumbnail/enlarge interaction must open the dialog
after hydration, rather than navigate to raw SVG. Keep useful static fallback
links on the page when JavaScript or an asset fails.

## SSR, semantics and the existing publication boundary are mandatory

- Register `EvidenceFact` in `src/chrome-bindings.tsx` through `mdxExtras` and add
  exactly `EvidenceFact: []` to `ALLOWED_COMPONENT_ATTRIBUTES`. Implementation
  file: `ui/evidence-fact.tsx`; public props: `children?: ComponentChildren`.
  Use `containerComponent("EvidenceFact", {}, children)` in the renderer. No
  evidence text in JSX attributes, unsafe string interpolation, raw HTML or
  serialization bypass. Do not weaken attribute/delimiter guards.
- Ordinary Markdown h2/h3/h4 nodes own section names and native desktop/mobile
  TOC discovery. No major heading hidden inside an SSR component. Existing
  evidence anchors stay exactly once at their original claim; keep all existing
  anchor destinations and heading links, including class/source/map headings.
- All facts, conditions, verdicts, refusals, coverage gaps, source metadata,
  dependencies and exact IDs must be visible by default in the page, present
  without JavaScript, and readable in Markdown and LLM exports. Pin assignments
  alone may remain in native details; they still exist in all static outputs.
- `EvidenceFact` has no client bundle or hydration dependency. Actual preview
  islands retain static route-import reachability; `mdxExtras` alone does not
  guarantee island hydration. Preserve the package route/chrome bindings.
- Reuse scoped project styles and existing package tokens. Correct intrinsic
  sizing/wrapping at the overflowing component; never mask missing text with
  global `overflow-x: hidden`, clipping, line clamping, tiny fonts or truncation.
  Long IDs/URLs/conditions must wrap. Dense comparison tables may scroll locally
  using the existing keyboard-focusable `EvidenceTable`, with visible focus.
- Keep original data order, field values and units, value keys, class/provenance
  distinctions, availability/authority, conditions, exact verdict/refusal,
  expressions/dependency edges, source locators, relation/placement/fit state,
  coverage reasons/blockers, legends and agent-resource links. Preserve every
  existing empty-state sentence/branch, including calculation/evidence-chain
  section-presence rules. No inferred approval, severity or aggregate score.
- All 35 currently published records, their full catalog entries, indexes,
  landing and integration pages use the selected common renderers. No MPN/route
  special case. Future public records and empty/adversarial fixtures use the same
  behavior. Publication matrices, preflight decisions and denied fields stay
  unchanged. Regenerate production MDX; never hand-edit it.
- Preserve frontmatter title/description identity terms (MPN, LCSC, board/refdes,
  record and integration rule IDs). Verify search against its existing
  300-character body excerpt behavior; adding full-body search is out of scope.

## Concrete routes and generic cases define the verification set

All record paths below start at `/docs/components/records/`. This selection was
checked against the generated baseline and the central inventory; examples do
not authorize changing component evidence.

| Route | Shape to inspect |
| --- | --- |
| `umw-ao3401a/` | Accepted reference, exact locators, repeated source citations, record SOURCE UNAVAILABLE alongside selected source AVAILABLE, open coverage with no blockers. |
| `c14663/` | CC0603KRX7R9BB104; nine placements across Board P/L, long identifiers and conditions. |
| `rlp25feer200/` | Subordinate RLP25FEER200; parent link, calculated fact values, expression and cross-record input links. |
| `stusb4500qtr/` | Dense IC: 23 facts; long coverage/repeated citations, multiple unavailable ST sources and pin lookup. |
| `ap63203wu-7/` | Largest current fact count: 27; several fact classes, calculations and long source text. |
| `c529334/` | STM32G031F8P6; retained locators with unavailable evidence must stay visibly qualified. |
| `c492404/` | Subordinate hand-fit/DNP SWD header, placements in two board contexts and its published pin map. |
| `/docs/components/integration/#rule-usb-pd-nvm-load-switch` | Exact refusal before arithmetic, conditioned expressions and cross-record links. |
| `/docs/components/integration/#rule-evidence-chain` | Ordered stages with gaps; no implication of board approval. |
| `/docs/components/`, `/docs/components/catalog/`, `/docs/components/records/` | Counts, complete comparison index, all full entries and parent/subordinate order. |

Generic public-model fixtures additionally cover structured/empty values,
calculated facts with missing expression or no inputs, empty sections, unavailable
source with present or absent URL, absent parent/owner, zero placement, multiple pin maps, open domain
without blockers, multiple source IDs with identical titles, long hostile text
(`{`, `<`, pipes and quotes), and future records. Use existing fixture builders;
do not manufacture private/electrical evidence in production bundles.

For #137/#138, focused SSR/serialization and renderer tests assert exact retained
content/links and allow-list behavior. Corpus tests compare all public claim
fields and anchor destinations against the baseline, not just page counts or a
single AO3401A snapshot. Run type/generator checks without a worker browser build.

For #140, one guarded production build/browser pass checks the routes above at
1600×1000 and 390×844, both themes, actual package breakpoints and content widths
with sidebar/TOC open. Inspect screenshots, not only DOM geometry. Confirm native
TOC headings/targets (especially Documents and package), mobile On this page,
search identifiers, keyboard/local table scrolling, no page overflow, source and
dependency navigation, static/LLM completeness and all dialog behaviors above.
Any synthetic long/empty/asset-error route belongs only to the verification
fixture surface, never the generated production corpus.

## Ownership keeps implementation lanes independent

- **#137:** add `EvidenceFact`, safe allow-list/binding support, scoped fact styles
  and focused SSR/safety tests. No coverage/source widget. Existing table/details
  behavior remains available for the selected uses.
- **#138:** apply this structure in all renderers and regenerate the entire
  corpus; own the external Documents and package Markdown heading/legacy anchors
  and static claim text. Preserve the references descriptor API.
- **#139:** own `ComponentReferences` layout/internal-heading removal and the
  existing footprint/model dialog behavior. Do not edit generator-owned pages.
- **#140:** verify integrated corpus parity and actual native UX, including the
  new facts and Markdown coverage/source decisions as well as accepted previews.

## Native screenshots support the fact boundary; final spacing still needs verification

On 2026-09-25 the manager captured the actual built native routes at 1600×1000
and 390×844 under the shared heavy guard. Local review artifacts are under
`/home/takazudo/repos/circuits/zudo-led-lamp/.git/x-wt-135-shots/` (not committed):

- `native-ao-{coverage,facts,sources}-{desktop,mobile}.png`: current AO3401A.
- `native-dense-{coverage,facts,sources}-{desktop,mobile}.png`: current STUSB4500.
- `probe-{ao,dense}-facts-{desktop,mobile}.png`: temporary DOM/CSS treatment B in
  those same native routes; no prototype code was committed.

Direct visual review of AO desktop/mobile facts and the AO/dense mobile probe
confirms the design problem: desktop table columns split IDs and citations into
short fragments, and mobile initially exposes only the leading table columns.
The vertical treatment gives conditions and locators the content width while
keeping each claim together. The manager also measured no document horizontal
overflow at 390 for the probe. This supports `EvidenceFact`; its final Markdown
children keep explicit labels that the illustrative probe did not all show.

Direct review of native AO coverage/mobile and sources/desktop confirms repeated
metadata consumes substantial height. The coverage/source alternatives above
were assessed structurally against this real route; their selected Markdown
rearrangements have not yet been rendered as implementation. They require the
focused integrated screenshots in #140. No coverage/source component is justified
by the observed content shapes.

The dense mobile DOM probe shows a class/gloss/first-fact spacing overlap. It is
not a passed final UI: #137 must keep normal block flow around the primitive and
#140 must inspect dense class headings, glosses and adjacent fact boundaries for
overlap at narrow widths. The initial CLI baseline also appeared to overflow;
the manager's later native CDP comparison is the more useful design capture, and
the production pass must measure overflow independently rather than infer success
from either image. Dark-theme and media behavior remain governed by the accepted
issue references and require integrated verification. These observations assess
the presentation decision, not production SSR, export or interaction parity.

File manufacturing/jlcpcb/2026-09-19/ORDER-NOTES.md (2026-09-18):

# JLCPCB order files

The `jlcpcb/2026-09-19/` release requests JLCPCB soldering for every intended
fitted component, including Board L J3 and SWD-adapter J1/J2. These three
previously hand-fit connectors are explicit **release population overrides**.
Original design sources retain their default population settings; the release's
`source/` snapshots, BOMs and CPLs use the assembly overrides consistently.

For each board, upload `<board>-gerbers.zip` for the PCB, `bom.csv` for component
selection, and `cpl.csv` for placement. Do not upload the overall handoff ZIP as a
single PCB: it contains three separate designs.

| Board | PCB | Assembly |
| --- | --- | --- |
| board-p | 27 × 40 mm, 2 layers, FR4, 1.6 mm, 35 µm outer copper | Top-side parts, including through-hole JOUT1 |
| board-l | 60 × 60 mm, 2 layers, FR4, 1.6 mm, 35 µm outer copper | Both sides; top SMD, bottom J2/J3/RV1/SW2 through-hole parts |
| swd-adapter | 36 × 18.1 mm, 2 layers, FR4, 1.6 mm, 35 µm outer copper | Both connectors on top, through-hole assembly |

Select a JLCPCB assembly service that accepts the listed through-hole parts and
Board L's two-sided component installation. Quantity, finish, mask color, stock,
assembly-service eligibility and price are selected in the quote; none are
reserved or purchased by this export. Copper and thickness above are taken from
the board stackups, not an independently approved factory quote.

## Before releasing the order

- **Board L RV1 requires assembler confirmation.** ALPS specifies manual
  soldering for RK10J11E0034 / C470643, while JLCPCB's listing describes wave
  soldering. Request a manufacturer-compatible process from JLCPCB, plus seating
  and retention confirmation for this project's 1.6 mm board. RV1 is included in
  the BOM/CPL; it has not been silently moved to user hand-soldering.
- Compare each JLCPCB placement preview with `assembly-top.svg` and
  `assembly-bottom.svg` (bottom drawing is mirrored to view from underneath).
  Native KiCad rotations are used with recorded JLCPCB corrections. **Board L
  RV1 is corrected from 0° to 180°**, matching the user's manual 180° rotation
  before the reviewed bottom preview on 2026-09-19. This corrects JLCPCB's library
  orientation only; no PCB geometry was rotated. Do not rotate RV1 another 180°
  after uploading the corrected CPL. Check all IC pin-1 marks, LED/diode polarity, USB-C mating direction,
  and connector keys/pin 1 before checkout.
- Read the retained DRC/ERC reports. The initial DRC has no errors or unconnected
  items, but existing silkscreen warnings remain. Board P also has one duplicate
  SCL via, a short dangling gate-track stub and three PCB-only mounting-hole
  parity warnings. SWD adapter J2 differs from the library copy; its numeric
  orientation is covered by `verify_swd_adapter.py`. These exports do not
  change no copper or mechanical geometry. A redundant zero-length SW2
  silkscreen line is omitted in the release snapshot because KiCad 10.0.0 exports
  it as invalid zero-aperture Gerber draws; the surrounding outline is retained.
  This cleanup adds an expected SW2 library-copy mismatch warning in the release
  snapshot. The source Board L has 58 silk warnings; the snapshot has those 58
  plus that one mismatch. ERC has six unspecified-pin warnings each on Boards
  P/L and none on the adapter, with zero ERC errors on all three.
- The existing project component evidence retains prototype/continuity and
  programmed-state checks. PCB fabrication and assembly do not program the
  STUSB4500 NVM or STM32 firmware. The Board P VREG_2V7 external-load question
  remains open before NVM-programming bench work.

Board P **R17/R18 (external Rd) and D6/D7 (optional CC protection) remain DNP**.
Pogo/test pads and mounting holes are not orderable components. `excluded.csv`
records exclusions; no user-soldered component is required by the fitted variant.

## Traceability and coordinates

The exact MPN/LCSC identity comes from the generator specs and validated component
inventory, checked against each PCB's schematic-derived `LCSC` property. Some
imported `LCSC Part` fields contain stale generic-footprint values; those are
normalized only in release snapshots and recorded in `checks/export-validation.json`.

All Gerbers, drills and CPLs use the same drill/place origin. CPL X/Y values are
the native KiCad CSV coordinates in millimetres, with no bottom-side X mirror and
no second Y inversion. This follows JLCPCB's current KiCad 10 guide. The older
personal conversion skill negates Y again; this release uses its BOM converter
only, avoiding that coordinate mismatch.

- [JLCPCB KiCad BOM/CPL guide](https://jlcpcb.com/help/article/how-to-generate-the-bom-and-centroid-file-from-kicad)
- [JLCPCB Gerber/drill guide](https://jlcpcb.com/help/article/how-to-generate-gerber-and-drill-files-in-kicad-7)
- [ALPS RK10J catalog](https://tech.alpsalpine.com/cms.media/product_catalog_rv_03_rk10j_en_780020d1ea.pdf)
- [JLCPCB RV1 listing](https://jlcpcb.com/partdetail/C470643)

`manifest.json` records source hashes, component counts, origins, population
overrides and field corrections. `source/` retains the actual export input with
refilled zones; `raw/` retains netlists and original position exports. `checks/`
contains commands and validation results.

`manufacturing/jlcpcb-rotation-corrections.json` is the part-number-locked source
for future export rotation corrections; `rotation-corrections.json` in the release
retains a copy. Raw KiCad positions remain unchanged for traceability.

`gerber-top.png` and `gerber-bottom.png` are independently rendered from each
actual Gerber ZIP, not screenshots of the PCB editor. Verification uses
`gerbonara==1.6.3` and `resvg-py`; run
`python3 scripts/pcb/verify-jlcpcb.py manufacturing/jlcpcb/NEW-RELEASE`
in an environment with those packages installed.

To regenerate into a **new, empty** release directory:

```sh
python3 .claude/skills/component-spec-audit/scripts/validate.py
python3 scripts/pcb/export-jlcpcb.py manufacturing/jlcpcb/NEW-RELEASE
```

The script requires KiCad 10 and the personal
`jlcpcb-bom-generate-from-kicad/scripts/convert_to_jlcpcb.py` BOM converter
(`--converter` can supply its path). It never overwrites an existing board release.

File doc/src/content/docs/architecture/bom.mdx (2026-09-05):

---
title: Final BOM
description: The complete prototype bill of materials for Board P and Board L — every part with a lookup-verified LCSC number, JLCPCB tier, stock, and the Extended-part fee arithmetic that dominates the order cost.
sidebar_position: 40
---

This is the **final** BOM, not a candidate list. Every C-number below was re-verified
individually against the local JLCPCB parts database (snapshot dated **2026-07-25**;
per-part data-fetch dates within the snapshot range from 2026-05-23 to 2026-07-03).
The XFCN `JOUT1`/`J2` mating pair was separately checked against live JLCPCB/LCSC
inventory and manufacturer drawings on **2026-08-20**; its rows carry that date.

This page intentionally covers the two assembled lamp boards. The separate
[ST-LINK/V2 SWD adapter](./swd-adapter.mdx) has only two hand-fit/DNP connector
lines, `C4749199` and `C492404`; their current identity and evidence live in the
component catalog rather than the lamp-PCBA cost arithmetic below.

Every fitted line below also has a canonical component record — the exact orderable
identity, every board placement, the sources behind it and which coverage domains are
still open. Browse them in the [component catalog](/docs/components/catalog/); the
cross-component rules that span several of these parts at once are on the
[integration page](/docs/components/integration/). This page keeps the ordering,
tier and cost reasoning, which lives nowhere else.

:::warning[Stock is a point-in-time read]
Stock figures are from the snapshot, not a guarantee. Re-check every line immediately
before ordering — and pay particular attention to the four lines flagged below with
stock under 25,000. Tier assignments (Basic / Preferred / Extended) can also change; the
fee arithmetic at the bottom of this page is only as good as the tier data on the day
you order.
:::

## Low-profile control replacement (2026-09-06)

| Ref | Qty | Selected part | Dated JLCPCB stock / order quantity |
|---|---:|---|---|
| RV1 | 1 | ALPS RK10J11E0034 / [C470643](https://jlcpcb.com/partdetail/C470643) | 6,939 / 6,677 |
| SW2 | 1 | G-Switch SS-12D01-G020 / [C5446803](https://jlcpcb.com/partdetail/C5446803) | 3,709 / 3,698 |

Both controls replace the prior EC11 encoder and Dailywell toggle. Stock is a dated
observation, not a reservation. ALPS specifies manual soldering and insertion
(t:2 mm); supplier listing availability does not approve this board's assembly.
Verify seating/retention and soldering on the 1.6 mm PCB with the assembler.

R22 changes to 100 kΩ C25803; R27 remains 100 Ω C22775 and C22 remains 100 nF
C14663. R23, R28 and C23 are removed. Four RV1 dummy/support terminals remain
unconnected. Refresh the BOM/CPL and quote from the revised design rather than
reusing the old stock and Extended-fee snapshot below. See [rear controls](./rear-controls.mdx).

## Board P — USB-PD front end

Adopted unchanged from the [power-section audit](/docs/power/board-p-front-end/#component-list-lcsc-parts-and-rough-cost).

| Ref | Qty | Part | LCSC | Package | Tier | Stock | Role |
|---|---|---|---|---|---|---|---|
| U1 | 1 | STUSB4500QTR | [C2678061](https://jlcpcb.com/partdetail/C2678061) | QFN-24-EP 4x4 | Extended | 4,562 | PD sink controller |
| Q1 | 1 | AO3401A | [C347476](https://jlcpcb.com/partdetail/C347476) | SOT-23 | Extended | 862,120 | Load switch (P-FET) |
| J1 | 1 | TYPE-C-31-M-17 | [C283540](https://jlcpcb.com/partdetail/C283540) | 6P SMD right-angle | Extended | 33,876 | Primary 20 V/5 A rating; project numeric contact mapping/incoming continuity OPEN |
| D5 | 1 | SMAJ20A | [C571370](https://jlcpcb.com/partdetail/C571370) | SMA | Extended | 3,770 | Primary VRWM 20 V; numeric pad/orientation and actual clamp waveform OPEN |
| C1 | 1 | CL31A106KBHNNNE 10 µF 50 V | [C13585](https://jlcpcb.com/partdetail/C13585) | 1206 | **Basic** | 1,877,266 | VDD bulk |
| C2, C35 | 2 | CC0603KRX7R9BB104 100 nF 50 V | [C14663](https://jlcpcb.com/partdetail/C14663) | 0603 | **Basic** | 12,618,106 | VDD HF decouple, gate–source soft-start. The C1711 → C14663 swap recommended on the [Board P page](./board-p.mdx) was applied at KiCad capture — one Extended line removed, reel shared with Board L |
| C30, C34 | 2 | CL10A105KB8NNNC 1 µF 50 V | [C15849](https://jlcpcb.com/partdetail/C15849) | 0603 | **Basic** | 5,979,916 | VREG decoupling |
| R11 | 1 | 100 kΩ ±1% | [C25803](https://jlcpcb.com/partdetail/C25803) | 0603 | **Basic** | 7,990,119 | Gate pull-up (default OFF); shares Board L's R26 reel |
| R12 | 1 | 150 kΩ ±1% | [C22807](https://jlcpcb.com/partdetail/C22807) | 0603 | **Basic** | 414,154 | Gate series — re-ratioed from 56 kΩ by the design review to keep V_GS inside ±12 V at a 20 V mis-contract |
| R13, R14 | 2 | 470 Ω ±1% | [C23179](https://jlcpcb.com/partdetail/C23179) | 0603 | **Basic** | 1,899,614 | DISCH + pin-18 series |
| R15, R16 | 2 | 4.7 kΩ ±1% | [C23162](https://jlcpcb.com/partdetail/C23162) | 0603 | **Basic** | 7,433,362 | I2C pull-ups |
| R19, R20 | 2 | 0 Ω | [C21189](https://jlcpcb.com/partdetail/C21189) | 0603 | **Basic** | 6,153,233 | CC1DB/CC2DB bridges |
| R21 | 1 | 10 kΩ ±1% | [C17414](https://jlcpcb.com/partdetail/C17414) | 0805 | **Basic** | 10,726,008 | RESET pull-down (run state); shares Board L's reel. Added by the design review with the J2.4 reset line |
| JOUT1 | 1 | PZ254V-11-06P male | [C492405](https://jlcpcb.com/partdetail/XFCN-PZ254V_1106P/C492405) | THT 1x6, 2.54 mm | Extended | 98,021 (live 2026-08-20) | Direct Board L interface; unkeyed, verify pin 1 |
| J2, J3 | — | Pogo pads 1x4 / 1x8 | — | Bare copper | — | — | NVM I2C + debug, no part |

**DNP — footprint only, not populated:**

| Ref | Part | LCSC | Package | Tier | Stock | Note |
|---|---|---|---|---|---|---|
| R17, R18 | 5.1 kΩ ±1% | [C23186](https://jlcpcb.com/partdetail/C23186) | 0603 | **Basic** | 3,775,920 | External Rd — rework insurance only, never populate on a powered build |
| D6, D7 | PESD24VS1UB | [C85382](https://jlcpcb.com/partdetail/C85382) | SOD-523 | Extended | 109,452 | CC-line ESD, enclosed/production builds only |

## Board L — driver, control, LED array

| Ref | Qty | Part | LCSC | Package | Tier | Stock | Role |
|---|---|---|---|---|---|---|---|
| U2 | 1 | AL8860MP-13 | [C500782](https://jlcpcb.com/partdetail/C500782) | MSOP-8-EP | Extended | **4,000** | CC buck LED driver, 4.5–40 V, 1.5 A |
| U3 | 1 | STM32G031F8P6 | [C529334](https://jlcpcb.com/partdetail/C529334) | TSSOP-20 | Extended | 12,551 | Control MCU, Cortex-M0+, 64 KB |
| U4 | 1 | AP63203WU-7 | [C780769](https://jlcpcb.com/partdetail/C780769) | TSOT-23-6 | Extended | 11,392 | 3.3 V synchronous buck, 3.8–32 V |
| D10 | 1 | SMAJ20A | [C571370](https://jlcpcb.com/partdetail/C571370) | SMA | Extended | **3,770** | Local 15 V input TVS; numeric pad/orientation and actual waveform OPEN |
| D11 | 1 | SS26 | [C7420363](https://jlcpcb.com/partdetail/C7420363) | SMA | *Preferred* | 282,808 | Catch diode, 60 V/2 A Schottky |
| L1 | 1 | FXL0630-330-M 33 µH | [C177245](https://jlcpcb.com/partdetail/C177245) | SMD 7x6.6 mm | Extended | 228,367 | LED buck inductor, 2.1 A max-design Isat (retained value; the 2.5 A figure is a typical-labeled catalogue column), 310 mΩ |
| L2 | 1 | FNR4030S4R7MT 4.7 µH | [C167874](https://jlcpcb.com/partdetail/C167874) | SMD 4x4 mm | Extended | 252,195 | Logic buck inductor, shielded, 78 mΩ |
| RS1 | 1 | RLP25FEER200 200 mΩ ±1% 2 W | [C459674](https://jlcpcb.com/partdetail/C459674) | 2512 | Extended | **20,654** | High-side sense → 500 mA |
| R30–R37 | 8 | 33 Ω ±1% 1 W | [C2934070](https://jlcpcb.com/partdetail/C2934070) | 2512 | Extended | 85,468 | Per-string ballast — upsized from a 250 mW 1206 by the design review (the 1206 exceeded its rating at the worst-case 90 mA string) |
| R20, R24, R25 | 3 | 10 kΩ ±1% | [C17414](https://jlcpcb.com/partdetail/C17414) | 0805 | **Basic** | 10,726,008 | CTRL filter series, PDOK/ATT pull-ups |
| R22, R26 | 2 | 100 kΩ ±1% | [C25803](https://jlcpcb.com/partdetail/C25803) | 0603 | **Basic** | 7,990,119 | Brightness ADC pull-down and NTC divider top — R26 moved off the 10 kΩ line by the design review; the outgoing 10 kΩ divider exceeded the NTC's 0.1 mA maximum operating current by 68%. Shares Board P's R11 reel |
| R27 | 1 | 100 Ω ±1% | [C22775](https://jlcpcb.com/partdetail/C22775) | 0603 | **Basic** | 7,325,193 | Brightness wiper series resistor |
| R21 | 1 | 33 kΩ ±1% | [C4216](https://jlcpcb.com/partdetail/C4216) | 0603 | **Basic** | 696,981 | CTRL pull-down + divider (default-OFF) |
| C10, C11, C12, C14 | 4 | CL31A106KBHNNNE 10 µF 50 V | [C13585](https://jlcpcb.com/partdetail/C13585) | 1206 | **Basic** | 1,877,266 | Input bulk + both buck input caps |
| C13, C15, C18, C20–C22, C24 | 7 | CC0603KRX7R9BB104 100 nF 50 V | [C14663](https://jlcpcb.com/partdetail/C14663) | 0603 | **Basic** | 12,618,106 | HF decouple, BST, NRST, CTRL filter, brightness ADC filter, NTC filter |
| C16, C17 | 2 | CL21A226MAQNNNE 22 µF 25 V | [C45783](https://jlcpcb.com/partdetail/C45783) | 0805 | **Basic** | 1,734,789 | 3.3 V output caps per DS41326 Table 2 |
| C19 | 1 | CL10A105KB8NNNC 1 µF 50 V | [C15849](https://jlcpcb.com/partdetail/C15849) | 0603 | **Basic** | 5,979,916 | MCU VDD bulk |
| RT1 | 1 | NCP18XH103F03RB 10 kΩ B=3380 K | [C13564](https://jlcpcb.com/partdetail/C13564) | 0603 | Extended | 398,625 | NTC, placed inside the LED array |
| F1 | 1 | BSMD1206-075-30V | [C976305](https://jlcpcb.com/partdetail/C976305) | 1206 | Extended | 73,979 | PPTC, 750 mA hold / 1.5 A trip / 30 V |
| J2 | 1 | PM254V-11-06-H85 female | [C2832269](https://jlcpcb.com/partdetail/XFCN-PM254V_11_06H85/C2832269) | THT 1x6, 2.54 mm | Extended | 42,315 (live 2026-08-20) | Direct mate for Board P JOUT1; mirrors its pin map |
| RV1 | 1 | RK10J11E0034 | [C470643](https://jlcpcb.com/partdetail/C470643) | Insertion, low-profile wheel | Verify quote | **6,939** | Single-unit 10 kΩ ±30%; 270°±10° stops |
| SW2 | 1 | SS-12D01-G020 | [C5446803](https://jlcpcb.com/partdetail/C5446803) | THT short slide switch | Verify quote | **3,709** | Maintained SPDT, 1 A at 24 V DC |
| LED1–LED24 | 24 | HL-AM-2835H421W-S1-08-HR3 (2800–3100 K) | [C210315](https://jlcpcb.com/partdetail/C210315) | SMD2835-2P | Extended | 399,813 | 3000 K, CRI 80, 29 lm typ @ 60 mA |

**Footprint only — not in the assembly BOM:**

| Ref | Suggested part | LCSC | Package | Tier | Stock | Note |
|---|---|---|---|---|---|---|
| J3 | PZ254V-11-05P 1x5P | [C492404](https://jlcpcb.com/partdetail/C492404) | THT 2.54 mm | Extended | 251,600 | SWD. Hand-fit a pin strip during bring-up rather than paying an Extended fee for a debug-only connector — the same reasoning that put pogo pads on Board P |
| J4 | Pogo pads 1x3 | — | Bare copper | — | — | UART debug, no part — same bare-copper style as Board P's J2/J3 |

## Sourcing risks

Four lines carry stock low enough to matter on a small order. None is a design flaw —
they are the specialty parts — but each needs a re-check before ordering.

| Part | Stock | Risk and fallback |
|---|---|---|
| D5 / D10 SMAJ20A ([C571370](https://jlcpcb.com/partdetail/C571370)) | **3,770**, and **two boards need it** | Lowest-stock line in the whole design. Do not make a same-name or different-standoff substitution: exact vendor identity, conditioned clamp table, pad orientation, and both rail waveforms must be re-audited in the [ratings analysis](/docs/power/ratings-matrix/) and against the canonical record ([`rec-high-diode-smaj20a`](/docs/components/records/high-diode-smaj20a/)) |
| U2 AL8860MP-13 ([C500782](https://jlcpcb.com/partdetail/C500782)) — canonical record [`rec-al8860mp-13`](/docs/components/records/al8860mp-13/) | **4,000** | Fine for a prototype run. `AL8860WT-7` (TSOT-25) is pin-compatible in function but showed 0 stock and is limited to 1 A — it would still cover this design's 500 mA if the MSOP part disappears |
| RV1 RK10J11E0034 / C470643 | **6,939** | Current stopped-pot choice; do not substitute an encoder without circuit/firmware revision |
| RS1 RLP25FEER200 ([C459674](https://jlcpcb.com/partdetail/C459674)) | **20,654** | Any 200 mΩ ±1% 2512 sense resistor rated 1 W or better substitutes directly; the value, not the manufacturer, is what sets 500 mA — see [`fact-rlp25-resistance`](/docs/components/records/rlp25feer200/#fact-rlp25-resistance) |

## Extended-part fee economics

JLCPCB charges a one-time setup fee — **~¥470 (roughly $3)** — per unique **Extended**
part number, per order. Basic and Preferred parts do not incur it. The fee is per order,
so a part used on both boards is charged **twice** when the boards are ordered as two
separate PCBA jobs, which they must be.

| | Board P | Board L |
|---|---|---|
| Unique fitted part numbers | 14 | 22 |
| of which **Basic** | 9 | 8 |
| of which **Preferred** | 0 | 1 |
| of which **Extended** | **5** | **13** |

Board P Extended lines: `C2678061`, `C347476`, `C283540`, `C571370`, `C492405` — one
fewer than the original plan, because the C1711 → C14663 100 nF swap was applied.

Board L Extended lines: `C500782`, `C529334`, `C780769`, `C571370`, `C177245`,
`C167874`, `C459674`, `C2934070`, `C13564`, `C976305`, `C2832269`, `C2991196`, `C210315`.

| | Value |
|---|---|
| Extended lines charged | 5 + 13 = **18** |
| Setup fee total | 18 x ¥470 ≈ **¥8,460** (roughly **$54**) |
| Component cost, both boards, single-unit quantity | roughly **$8** |

**The setup fees are about seven times the parts cost.** That is the shape of every
small JLCPCB PCBA order and it is worth internalising before optimising anything else:
one avoided Extended line saves more than the entire resistor and capacitor content of
both boards combined. It also amortises to nothing on a reorder — a second batch of the
same design pays no setup fee at all.

Two reductions were already taken:

- **Board L's 10 µF caps use [C13585](https://jlcpcb.com/partdetail/C13585) (1206, Basic)
  rather than the 1210 X7R part the driver research listed
  ([C2918502](https://jlcpcb.com/partdetail/C2918502), Extended).** Saves ¥470 and shares
  a reel with Board P. The trade is X5R instead of the X7R the AL8860 datasheet asks for
  — X5R is rated to +85 °C, which covers this lamp's envelope, but if a build shows input
  ripple problems, C2918502 is the datasheet-strict swap.
- **Both boards' 100 nF caps now share [C14663](https://jlcpcb.com/partdetail/C14663)
  (0603, Basic).** Board P originally specified [C1711](https://jlcpcb.com/partdetail/C1711)
  (0805, Extended); the swap was applied at KiCad capture and is already counted in the
  arithmetic above.

Two more are available if the budget matters:

- Dropping `RT1` (NTC) and `F1` (PPTC) would save ¥940 and remove the thermal-derate
  and over-current protections. Both were added deliberately; this is the price of them.
- Ordering both boards as a single panelised PCBA job, if JLCPCB permits it for the
  design, would collapse the shared `C571370` TVS line from two charges to one — ¥470
  saved. The two connector halves are different orderables and do not collapse.
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

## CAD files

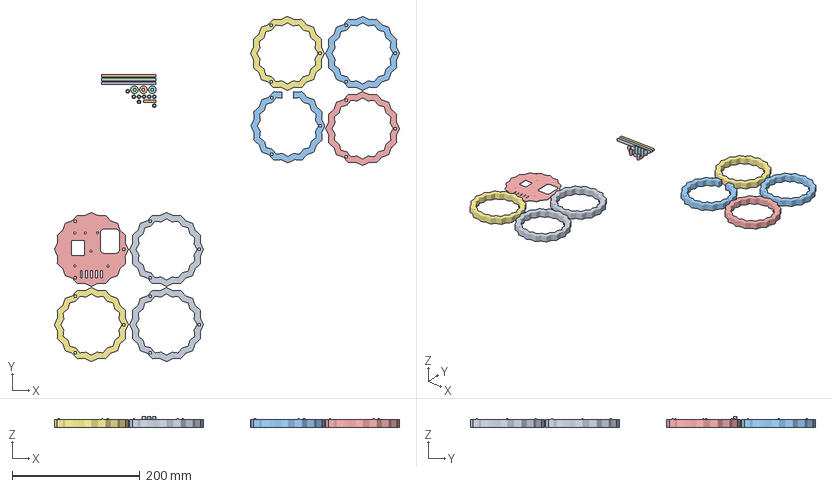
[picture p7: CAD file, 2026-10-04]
_3dp/p1s-led-enclosure.3mf
540.6 x 540.6 x 17.6 mm
02-band.stl
post-01-flat.stl
06-band-top.stl
post-03-flat.stl
05-band.stl x 2
post-02-flat.stl
foot-01.stl
03-band.stl
foot-02.stl
01-band-usb.stl
foot-03.stl
00-base.stl
mount-06-17.6mm.stl
04-band.stl
mount-02-17.6mm.stl
mount-01-17.6mm.stl
test-square-post-flat.stl
mount-05-5.0mm.stl
mount-04-5.0mm.stl
interboard-02-11.0mm.stl
interboard-01-11.0mm.stl
mount-03-5.0mm.stl

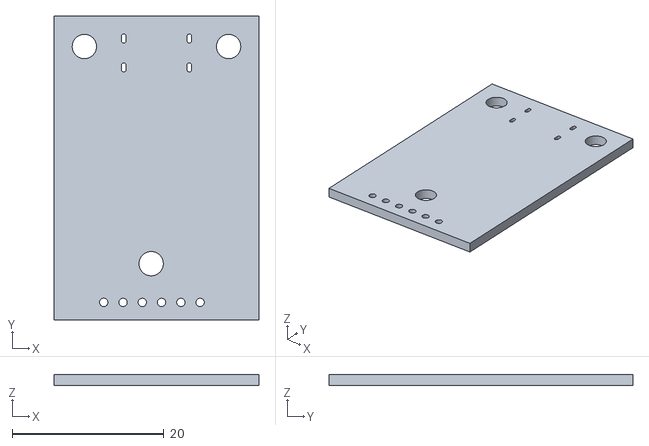
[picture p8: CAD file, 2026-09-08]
doc/public/assets/enclosure/preview/board-p-substrate-reference.stl
27.0 x 40.0 x 1.51

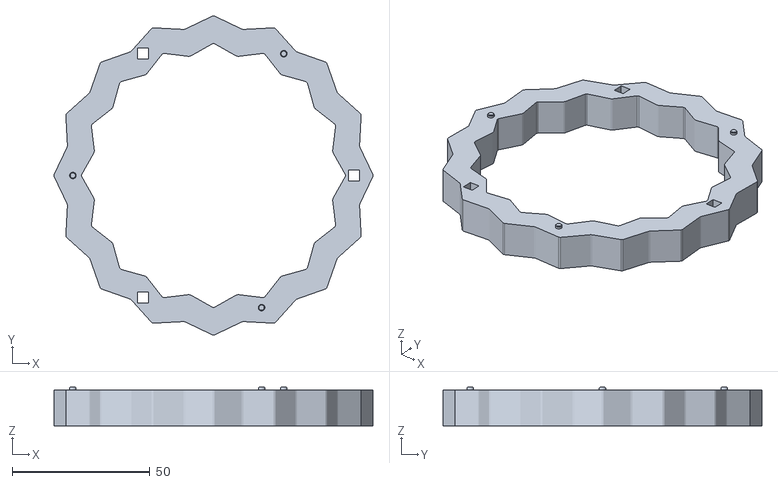
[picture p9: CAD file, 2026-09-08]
doc/public/assets/enclosure/stl/02-band.stl
115.7 x 115.7 x 14.0

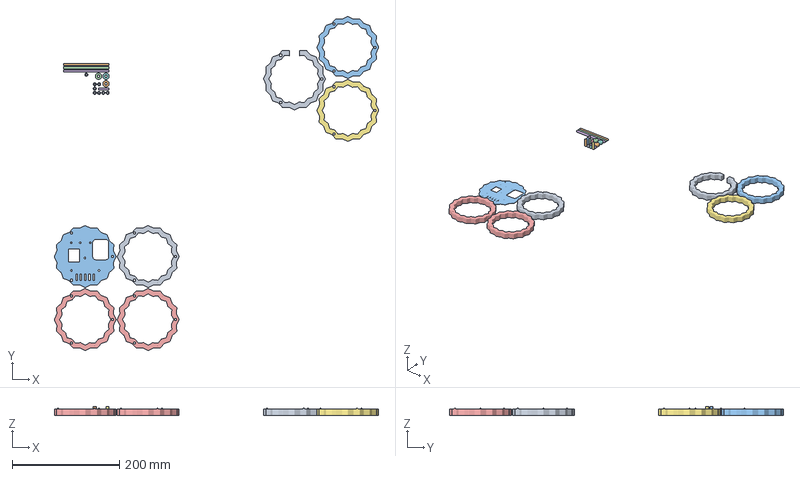
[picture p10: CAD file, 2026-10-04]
_3dp/h2d-led-enclosure.3mf
606.5 x 624.2 x 17.6 mm
02-band.stl
post-01-flat.stl
06-band-top.stl
post-03-flat.stl
03-band.stl
post-02-flat.stl
05-band.stl
foot-01.stl
01-band-usb.stl
foot-02.stl
00-base.stl
foot-03.stl
04-band.stl
test-square-post-flat.stl
mount-06-17.6mm.stl
mount-05-5.0mm.stl
mount-04-5.0mm.stl
mount-02-17.6mm.stl
mount-01-17.6mm.stl
interboard-02-11.0mm.stl
interboard-01-11.0mm.stl
mount-03-5.0mm.stl

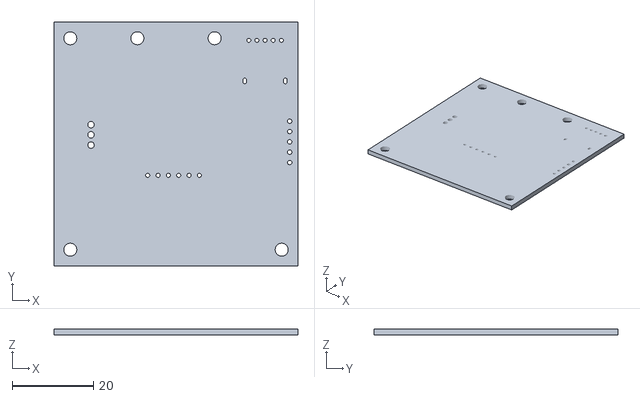
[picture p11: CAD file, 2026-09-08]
doc/public/assets/enclosure/preview/board-l-substrate-reference.stl
60.0 x 60.0 x 1.51

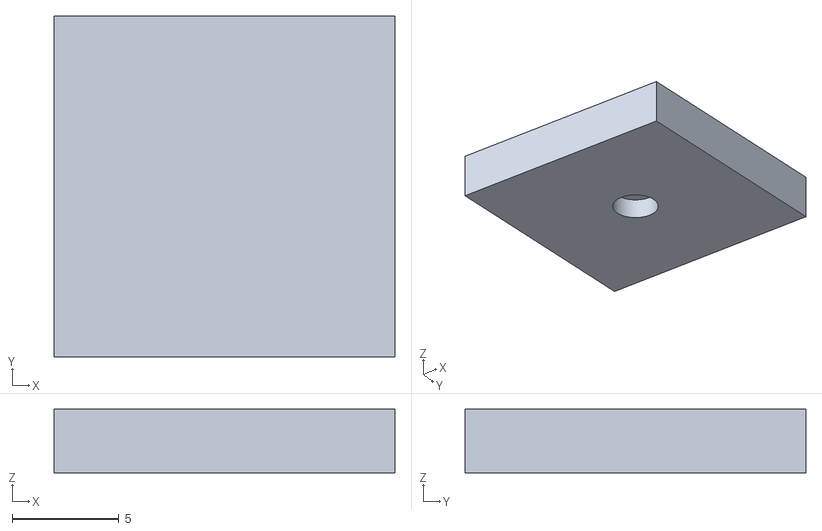
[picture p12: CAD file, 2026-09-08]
doc/public/assets/enclosure/stl/test-socket-clearance-0.6.stl
16.0 x 16.0 x 3.00

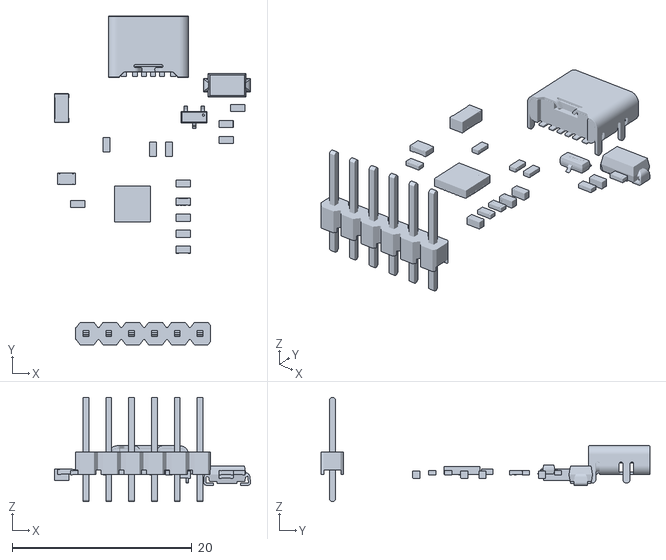
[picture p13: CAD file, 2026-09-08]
doc/public/assets/enclosure/preview/board-p-components-reference.stl
21.8 x 36.6 x 11.6

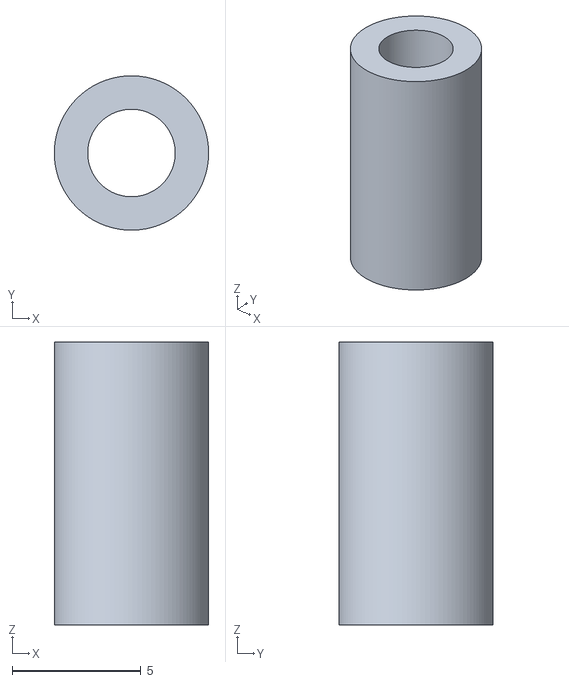
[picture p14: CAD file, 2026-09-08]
doc/public/assets/enclosure/stl/interboard-02-11.0mm.stl
6.00 x 6.00 x 11.0

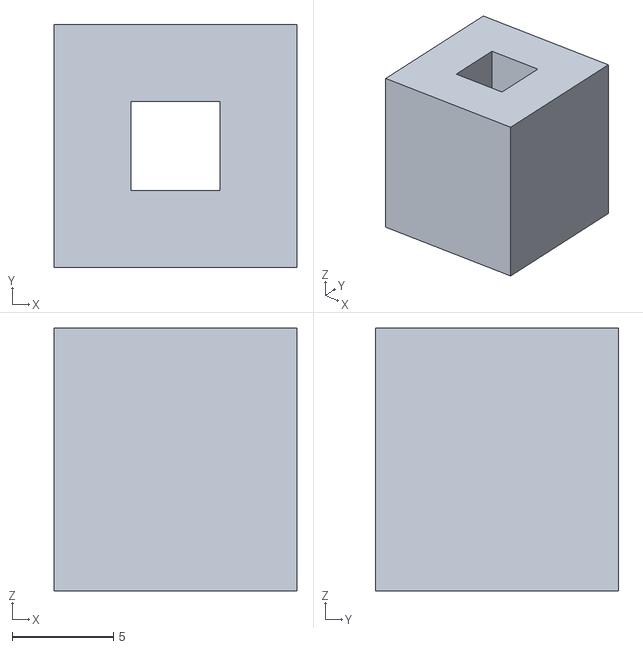
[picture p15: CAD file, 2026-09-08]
doc/public/assets/enclosure/stl/test-square-hole-4.4.stl
12.0 x 12.0 x 13.0

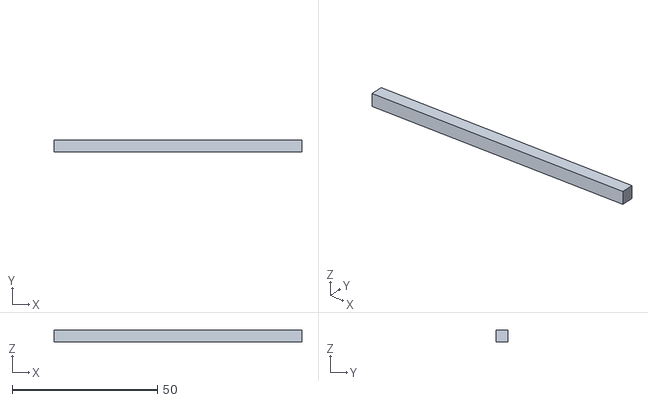
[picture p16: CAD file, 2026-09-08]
doc/public/assets/enclosure/stl/post-02-flat.stl
85.4 x 4.00 x 4.00

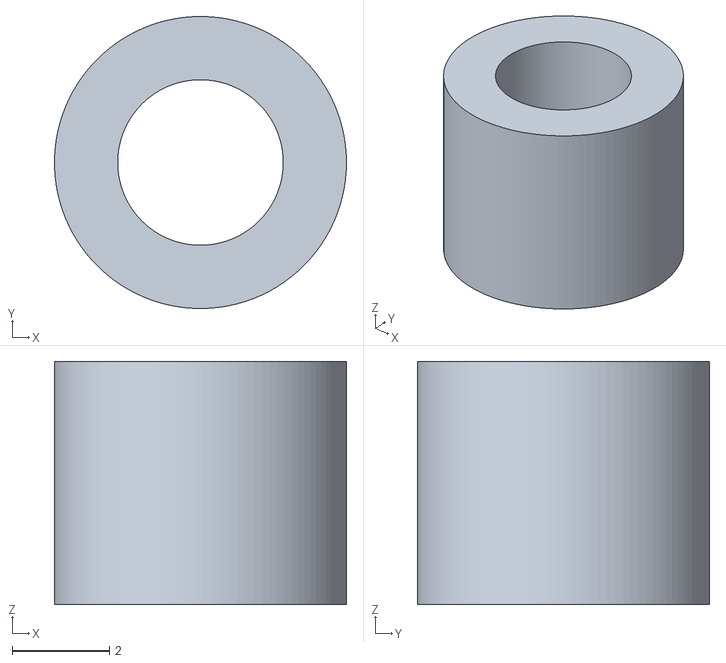
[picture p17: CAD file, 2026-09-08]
doc/public/assets/enclosure/stl/mount-04-5.0mm.stl
6.00 x 6.00 x 5.00

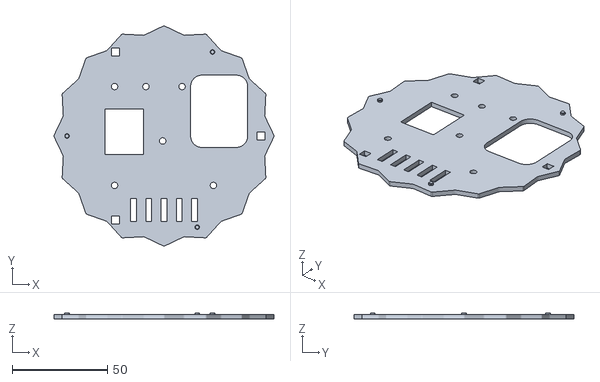
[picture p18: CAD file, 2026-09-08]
doc/public/assets/enclosure/stl/00-base.stl
115.7 x 115.7 x 3.40

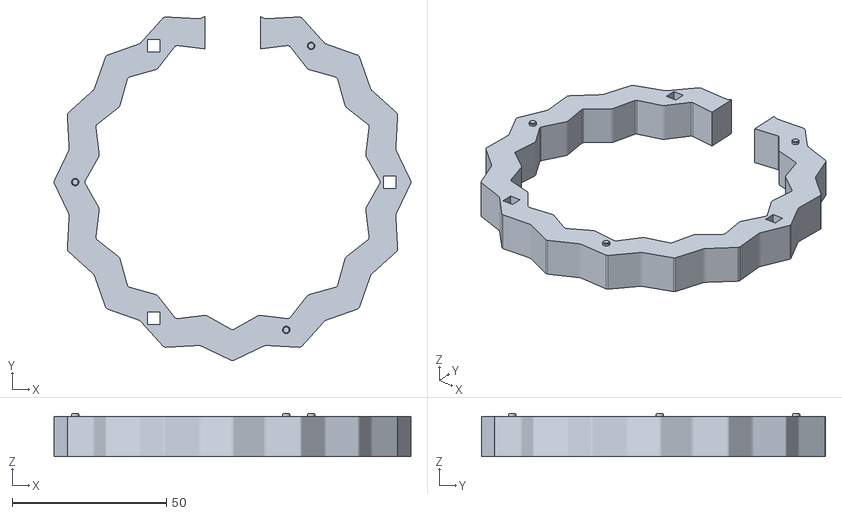
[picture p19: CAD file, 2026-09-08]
doc/public/assets/enclosure/stl/01-band-usb.stl
115.7 x 111.5 x 14.0

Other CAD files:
doc/public/assets/enclosure/stl/test-socket-clearance-0.4.stl
doc/public/assets/enclosure/stl/06-band-top.stl
doc/public/assets/enclosure/stl/foot-01.stl
doc/public/assets/enclosure/stl/foot-02.stl
doc/public/assets/enclosure/stl/foot-03.stl
doc/public/assets/enclosure/stl/mount-01-17.6mm.stl
doc/public/assets/enclosure/stl/mount-02-17.6mm.stl
doc/public/assets/enclosure/stl/mount-06-17.6mm.stl
doc/public/assets/enclosure/stl/test-pin-2.4.stl
doc/public/assets/enclosure/stl/test-socket-clearance-0.2.stl
doc/public/assets/enclosure/stl/test-square-hole-4.0.stl
doc/public/assets/enclosure/stl/test-square-hole-4.2.stl
doc/public/assets/enclosure/stl/test-square-post-flat.stl

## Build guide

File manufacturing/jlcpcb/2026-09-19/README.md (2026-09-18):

# JLCPCB upload sets

Prepared for quoting and placement review; read ORDER-NOTES.md before checkout.

| Board | Gerber ZIP | BOM | CPL | Fitted parts |
| --- | --- | --- | --- | --- |
| board-p | [board-p-gerbers.zip](board-p/board-p-gerbers.zip) | [bom.csv](board-p/bom.csv) | [cpl.csv](board-p/cpl.csv) | 19 |
| board-l | [board-l-gerbers.zip](board-l/board-l-gerbers.zip) | [bom.csv](board-l/bom.csv) | [cpl.csv](board-l/cpl.csv) | 67 |
| swd-adapter | [swd-adapter-gerbers.zip](swd-adapter/swd-adapter-gerbers.zip) | [bom.csv](swd-adapter/bom.csv) | [cpl.csv](swd-adapter/cpl.csv) | 2 |

All intended fitted components, including all connector headers, are requested
for JLCPCB soldering. Intentional Board P DNP options remain excluded.

RV1 CPL rotation is corrected from 0 to 180 degrees, matching the user-adjusted
JLCPCB bottom preview on 2026-09-19. Do not apply that correction a second time.

Board L RV1: confirm manufacturer-compatible soldering and 1.6 mm board seating
with JLCPCB. Stock and their placement preview still need checkout review.

Checks: no DRC/ERC errors; no unrouted connections; BOM/CPL identities and
population match; Gerber/drill ZIPs independently parsed and rendered.
Existing DRC/ERC warnings are retained under each board/checks directory.

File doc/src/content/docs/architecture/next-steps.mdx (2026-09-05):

---
title: Next Steps — The KiCad Phase
description: What happens after this architecture is locked — schematic capture order, the footprint and CPL rotation pipeline, BOM/CPL export, the staged bring-up sequence, and the open questions that need bench answers.
sidebar_position: 60
---

The architecture is locked; the next phase is KiCad data, which was explicitly out of
scope for this epic. This page is the handover: what to build, in what order, with which
tools, and which gates must pass before the next step is allowed.

## Fit and validate the rear controls

Board L now includes the routed JLCPCB **C5446803 SW2 slide switch** and rear RV1 stopped potentiometer.
The [rear-controls handoff](./rear-controls.mdx) gives PCB coordinates, the actual
3D render, and enclosure constraints. SW2 is included in the BOM/CPL; check both
control bodies in the enclosure and check terminal fit and front lead projection.
Follow the [bring-up sequence](./power-switch.mdx), including inrush, bounce,
rail decay, contact reliability and service back-power. These checks remain
unperformed until hardware exists.

## Schematic capture order

Capture Board P first even though it is the already-solved board — it forces the shared
symbol/footprint library into existence against a circuit whose net table is already
settled, so Board L's capture is not simultaneously debugging the library.

1. **Board P** — from the [locked net table](./board-p.mdx#net-connectivity-table).
   The C1711 → [C14663](https://jlcpcb.com/partdetail/C14663) 100 nF swap noted on that
   page was applied at capture (one Extended fee removed).
2. **Board L power section** — J2, F1, D10, the input bulk caps, and both converters.
   Verify the 15 V rail on its own before any load exists downstream of it.
3. **Board L LED array** — the eight ballast/string blocks. Draw one string as a
   hierarchical sheet and instantiate it eight times rather than copy-pasting; the
   [net table](./board-l.mdx#net-connectivity-table-led-array-8-strings-x-3-series) names the nets in exactly
   that repeating pattern.
4. **Board L control** — U3, RV1, RT1, the CTRL RC filter, the pad groups.

Run ERC after each stage, not once at the end.

## Layout notes worth having up front

| Concern | Guidance |
|---|---|
| **The whole LED array switches**, not just `LED_N` | `LED_N` (common cathode + SW pins) swings 0 → ~15.5 V at ~440 kHz — and because the string voltage is fixed, `LED_P` and every per-string net swing the same 15.5 V_pp right along with it. Keep **all** array copper compact; pour **no** array net as a large plane, `LED_P` included |
| D11's loop is the one that matters | The D11–U2–C12/C13 loop is the only high-di/dt commutation loop in the converter. D11's anode must sit immediately at U2 pins 5/6 with C12/C13 closing the loop to pins 2/3. Putting D11 out near the array would turn the whole array into the commutation loop |
| Ballast on the anode side | R30–R37 sit between `LED_P` and each string's top LED, deliberately, so `LED_N` stays one compact net instead of eight |
| RS1 is a **high-side** sense resistor | It sits between `V15` and `SET`, not in the ground return. Kelvin-connect it and keep the `SET` trace short — this is the node that sets LED current |
| U2 exposed pad | Tie to the ground pour for heat, but the datasheet is explicit that it must **not** be the electrical ground return path — pins 2 and 3 are |
| LED thermal pours | The [thermal budget](/docs/research/thermal-budget/) is clear that the ~1 W/site figure assumes a generous via-stitched pour per pad; a token pad does not hit it. At 0.19 W/site there is margin, but do not spend it all on cramped copper |
| RT1 placement | Physically **inside** the LED array, not near the board edge — it is measuring the array's temperature, and the derate thresholds assume that |
| RV1 and the board edge | Reserve the full Ø14±0.2 mm wheel envelope and finger access; its centre is offset from the footprint origin. Verify the low-profile housing and 1.6 mm PCB fit |

## Footprint pipeline

The LCSC parts here mostly have EasyEDA footprints, and pulling them in is faster than
drawing them — but it is also where the
[CPL rotation gotcha](/docs/power/lessons-from-zudo-pd/#jlcpcb-cpl-rotation-gotcha) bites.

1. **`easyeda2kicad`** to import symbols and footprints for the LCSC parts, especially
   the ones with no KiCad-official equivalent (U1 STUSB4500, U2 AL8860, J1 receptacle,
   RV1 potentiometer and SW2 slide switch).
2. **`kicad-jlcpcb-tools`** for the BOM/CPL export rather than KiCad's built-in export —
   it carries a community-maintained rotation database.
3. **Add explicit rotation overrides in its Corrections Manager** for every
   EasyEDA-derived footprint family on these boards, before trusting a single generated
   CPL. The failure mode zudo-pd hit is a generic rule like `^SOT-23 → -90°` matching an
   EasyEDA footprint that is *already drawn in JLCPCB's pin-1 convention* and applying a
   bogus 90° correction. On these boards that pattern threatens at minimum: Q1 (SOT-23),
   U4 (TSOT-23-6), U2 (MSOP-8-EP), U1 (QFN-24-EP), and U3 (TSSOP-20).
4. **Check the rendered CPL against the assembly preview by eye**, part by part, for
   every polarised or oriented device. JLCPCB's own pre-production review caught a QFN
   rotation problem on zudo-pd's v2 board and **missed** the SOT-23 over-correction on
   the same order — it is not a safety net.

## BOM and CPL export

Use the `jlcpcb-bom-generate-from-kicad` skill to produce the JLCPCB-format BOM and CPL
from the KiCad project. Then reconcile against the [Final BOM](./bom.mdx) page: every
C-number must match, and the DNP lines (Board P's R17/R18 and D6/D7) plus the
footprint-only pad groups (Board L's J3 and J4) must be **absent** from the assembly BOM,
not present with zero quantity.

Re-verify stock on the four flagged lines — `C571370`, `C500782`, `C2991196`, `C459674` —
on the day of ordering, per the [sourcing risks](./bom.mdx#sourcing-risks) table.

:::danger[Stale `LCSC Part` fields inside shared footprints — check before ordering]
The EasyEDA-imported `.kicad_mod` files each carry an `(property "LCSC Part" "C…")` naming
the *one* part they were downloaded for, but generic packages are shared across many
parts. The embedded value is wrong for most users of that footprint:

| Footprint | Embedded | Actually used by |
|---|---|---|
| `C0805` | `C1711` (retired 0805 100 nF) | **only** C16/C17 = 22 µF `C45783` — the embedded part is on neither board |
| `R0603` | `C25803` (100 kΩ) | nine resistor values **and** RT1, the `C13564` NTC |
| `R2512` | `C459674` (RS1 sense) | also R30–R37, the `C2934070` ballasts |
| `C0603` | `C15849` (1 µF) | also the eight `C14663` 100 nF parts |
| `R1206` | `C2907384` | nothing — retired with the 1206 ballast |

`kicad-jlcpcb-tools` resolves a part by scanning **board-footprint** fields and taking the
first whose name begins with `LCSC`/`JLC` — and both the schematic-supplied `LCSC` field
and the footprint's own `LCSC Part` qualify, so the stale one can win. KiCad's own
`sch export bom` reads schematic fields and is not affected; the risk is specific to the
plugin workflow this page mandates.

**Remedy:** delete every `LCSC`/`JLC` property from the shared package footprints, in
**both** `footprints/kicad/` and `footprints/kicad/zudo-led-lamp.pretty/`, keeping the two
copies byte-identical (`cmp -s`). Part identity then comes only from the schematic, which
`scripts/schgen/schgen_core.py` emits per instance from the spec's LCSC column.

**Editing a footprint means regenerating its preview.**
`doc/component-docs/footprint-previews/check.ts` verifies a per-package
`canonicalInputSha256` over the footprint bytes, so any `.kicad_mod` change must be
followed by `pnpm --dir doc generate:footprint-previews`, which renders through the
digest-pinned KiCad 9.0.9 container. That path is working — the container is cached and
regeneration was verified to reproduce the committed SVG bytes exactly — so expect the
cleanup diff to be the property deletions plus exactly 22 refreshed hashes in
`manifest.json`. Do not hand-edit the manifest.

Until the cleanup lands, treat a generated BOM's part numbers as unverified and diff every
line against [the BOM](./bom.mdx) by hand.
:::

:::note[Docker is needed only for footprint previews]
Nothing on the board path needs it. Schematic generation is pure Python,
`scripts/schgen/verify.sh` uses a local `kicad-cli`, and layout, DRC and fab export are
ordinary KiCad. `check:footprint-previews` verifies committed bytes with no KiCad at all —
only *regeneration* requires the container.

The pinned digest publishes **linux/amd64 only**, so an ARM host must emulate. The
renderer passes `--platform linux/amd64` for exactly this reason; a first-time setup on
Apple Silicon still needs the image pulled with the same flag:

```sh
docker pull --platform linux/amd64 kicad/kicad@sha256:e638b79b0321f29395a5b783e94bb9f3c73303e8da15da27b8f5cb4b67a37729
```

Emulated amd64 was verified to render byte-identical output, so the reproducibility
contract holds on ARM. Note the renderer is pinned to KiCad **9.0.9** while the schematics
are generated for KiCad **10** — deliberate, since the pin exists for byte reproducibility,
not compatibility. A local KiCad 10 renders the same geometry but formats coordinates to
six decimals instead of four, which changes every hash.
:::

## Bring-up sequence

The order here is not a suggestion. Each numbered step is a gate.

### Gate 1 — Board P NVM programming, on a 5 V-only source

:::danger[This gate protects the whole build]
A fresh, unprogrammed STUSB4500 ships with **PDO3 = 20 V/1.0 A at the highest priority**.
Plug it into any 20 V-capable PD charger before programming and it will negotiate 20 V
onto a board margined for a 15 V rail. **First-ever power-up must use a 5 V-only USB-C
charger** — an ordinary phone charger with no PD profile above 5 V, or a USB-A-to-C
cable, which supplies 5 V with no CC negotiation at all. The chip's I2C and NVM only need
5 V VDD.
:::

Write the NVM via the J2 pogo pads, then **read back and verify**: `SNK_PDO_NUMB = 2`
(PDO3 removed entirely, not merely deprioritised), PDO2 = 15 V/3 A, and
`POWER_ONLY_ABOVE_5V = 1`. That last bit has a history of not persisting on the first
write. Do not proceed until read-back is clean.

### Gate 2 — Board P standalone on a 15 V charger, nothing on JOUT1

Probe the J3 debug pads:

| Pad | Expected |
|---|---|
| 3 (`VREG_2V7`) | ≈2.7 V regardless of negotiation state — confirms the chip is alive before you judge negotiation |
| 4 (`VBUS_IN`) | ≈15 V once negotiated |
| 8 (`VBEN`) | pulled low once negotiation succeeds |
| JOUT1 pins 1/2 (`VBUS_OUT`) | 0 V until the contract is live, then tracking `VBUS_IN` |

A chip that negotiates but a switch that never turns on points at the Q1 gate network,
not the STUSB4500. And do not judge Board P by downstream rails — they can legitimately
read 0 V while the chip is perfectly healthy.

Two things this gate **cannot** measure, so don't chase them: J3 pads 6/7 (`ATT`/`PDOK`)
float — the pull-ups live on Board L, so with nothing on JOUT1 these open-drain lines
read garbage. Probe pad 8 (`VBEN`) instead. And before Gate 3, **ring out the harness
pin-for-pin**: both ends are the same 6-pin XH housing, and a reverse-crimped harness
puts 15 V onto Board L's ground with F1 on the wrong side of the fault to help.

**Also measure here:** the steady-state voltage across R14. This settles the
[open question](./board-p.mdx#one-number-this-pass-could-not-resolve) about whether the
pin-18 network draws ~32 mA continuously (0.48 W in a 100 mW resistor) or only during a
discharge event. A drop near zero confirms the sense-only reading.

Use a **single-port** PD charger with an explicit **15 V** entry in its PDO list. Every
multi-port GaN charger in zudo-pd's testing failed; the one that worked was single-port —
see [Charger Compatibility](/docs/power/charger-compatibility/).

### Gate 3 — Board L power section alone, MCU unprogrammed

Connect Board L. Before anything else, confirm the LED array is **dark**. Then:

| Measurement | Expected |
|---|---|
| `V15` at F1's output | ≈15 V, minus a few tens of mV across the PPTC |
| `V3P3` | 3.30 V ±3% |
| `CTRL`, with the MCU held in reset | **below 0.2 V** |

That last one is a real gate, not a formality: the
[safe default-OFF](./board-l.mdx#mcu-knob-and-dimming-path-safe-default-off) analysis
rests on a CTRL bias-current bound that no retained fact carries, so nothing on paper
closes it. If CTRL reads above 0.2 V, lower R21 and scale R20 down by the **same ratio**
so the R21/(R20+R21) divider still delivers ~2.53 V at full duty — concretely
**R21 33 kΩ → 10 kΩ together with R20 10 kΩ → 3.3 kΩ**, which gives
3.3 V × 10/13.3 = 2.48 V.

:::danger[Change both, in that pairing]
Dropping R21 to 10 kΩ while leaving R20 at 10 kΩ halves full-scale CTRL to 1.65 V; the
reverse pairing (R21 3.3 kΩ, R20 10 kΩ) collapses it to 0.82 V. Either one silently caps
the lamp well below I_NOM and invalidates the firmware's `DUTY_FULL_Q16` mapping.
:::

### Gate 4 — LED array at fixed current, no firmware

Drive CTRL from a bench supply at 2.5 V. Confirm:

- Total current into `LED_P` ≈ 500 mA
- **Per-string current across each of the eight ballast resistors** — this is the
  measurement the whole ballast analysis exists to validate. The prediction is ±15%
  around 62.5 mA for a same-reel spread. If any string exceeds ~90 mA, the imbalance is
  worse than the datasheet's own bound and the ballast value needs raising
- Switching frequency at `LED_N` ≈ 440 kHz
- Board temperature after 30 minutes, at RT1 and at the hottest-looking LED

Then sweep CTRL from 0.3 V to 2.5 V (drive and measure at **TP1**) and confirm smooth,
monotonic dimming with no flicker, buzz, or dropout — **with a scope on `LED_N`** (probe
D11's anode). Record the CTRL level below which the driver enters pulse-skip / burst
mode: at deep dimming the required on-time falls below the AL8860's 500 ns minimum and
the converter burst-fires at an unpredictable rate. If that burst rate is under
~300 Hz at the firmware's intended floor, raise `DUTY_FLOOR_Q16` above the recorded
point. Any audible noise here is worth chasing before firmware exists — it is far
harder to attribute once an animation is running.

### Gate 5 — Firmware

No executable control firmware is in this repository. Implement PA0/ADC_IN0
absolute-position acquisition first, with suitable sample time for up to 3.35 kΩ
source resistance, endpoint calibration, averaging and underside-direction inversion
if required. Then bring up PWM/CTRL mapping, gamma, modulation and thermal derating.
Initialize PWM off; only after valid ADC, PD-status and thermal checks, ramp toward
the knob's current position. Verify power-on, watchdog/reset and rapid OFF/ON behavior.

Open the wiper connection and measure the R22/C22 nominal 10 ms discharge toward
dark. This does not prove detection of all contact or wiring faults; a short to
V3P3 can look like a valid high setting. Validate the fault policy and ADC settling
on hardware, with the actual wheel and operating temperature.

## Open questions for the bench

| Question | Why it matters | How to answer |
|---|---|---|
| ~~Does Board P's R14 draw continuously?~~ **Resolved: no** | ST DS12499 §2.2.12 names the 50 mA figure as a discharge-event current; the sense role is high-impedance | Gate 2 measurement kept as confirmation only |
| ~~Does R21 hold CTRL below 0.2 V?~~ **Resolved: yes** | The AL8860 soft-start spec bounds CTRL bias at ≤1.67 µA → ≤55 mV across R21 | Gate 3 measurement (at TP1) kept as confirmation only |
| Where does pulse-skip start on the dimming sweep? | Burst-firing below the AL8860's minimum on-time is a flicker frequency; sets the real firmware floor | Gate 4 — scope on `LED_N` during the CTRL sweep |
| Real string-to-string imbalance | Sets whether 33 Ω of ballast is enough | Gate 4 — measure all eight ballast drops |
| Actual driver efficiency | The budget assumes 92%; component losses suggest ~95%; the research assumed 88% | Gate 4 — input power versus `LED_P` output power |
| Is 440 kHz switching audible? | Analog dimming should prevent it, but the inductor still switches | Gate 4 — listen in a quiet room, at several brightness levels |
| Is ~700 lm the right brightness through a diffuser? | The diffuser does not exist yet | Only answerable once the enclosure phase starts |
| Does the wheel turn brighter clockwise from underneath? | Endpoint polarity must match the user-facing direction | Measure endpoints and apply firmware inversion if needed |

## One pre-layout decision this design has not made

**Should L1 move to the far side of the LED array?** Board L currently orders the power
path `V15 → RS1 → SET → L1 → LED_P → ballast → strings → LED_N → U2.SW`, which makes every
net in the 24-LED array a switching node (`LED_N` 0 → ~15.5 V, `LED_P` ~11 → ~26.6 V at
~440 kHz). That is why the layout table above says to pour **no** array net as a plane —
which directly contradicts the [thermal budget](/docs/research/thermal-budget/)'s
requirement of a generous via-stitched pour per LED pad. The design cannot satisfy both.

Reordering to `V15 → RS1 → SET(= array anode) → ballast → strings → LED_N → L1 → SW_LED →
U2.SW`, with D11's anode on the new `SW_LED` node, resolves it:

- **Electrically equivalent where it matters.** L and the LED string are in series either
  way, so the inductor voltage, ripple, average current and duty are unchanged. The
  freewheel path becomes `SW_LED → D11 → V15 → RS1 → SET → array → L1`, so RS1 still
  carries the freewheel current and still senses *average* LED current — the property the
  AL8860's high-side sense depends on.
- **The array stops switching.** `SET` and `LED_N` become quiet: the residual is the
  ripple across the ballasts (~0.8 V pp from the nominal 0.2 A pp total, plus an
  unretained LED dynamic-resistance term), against ~15.5 V pp today. Only the compact
  `SW_LED` triangle — L1, U2 pins 5/6, D11's anode — swings.
- **Nothing else moves.** Ballasts stay anode-side, the eight cathodes still meet at one
  net, D11's anode still sits at U2 pins 5/6, and the commutation loop is unchanged.

Two caveats before acting. First, no retained fact records which ordering the AL8860's
typical application circuit uses; `fact-al8860-topology` says only "hysteretic buck with
integrated NDMOS and high-side current sense". The reasoning above stands on its own, but
the datasheet-figure confirmation is **not in the evidence registry** and should be
retained before this is treated as a reference-design correction rather than a project
choice. Second, this is a **connectivity change**, which the root `CLAUDE.md` says the
audit skills do not authorize on their own.

Procedure if adopted: edit the three `NETS` rows in `scripts/schgen/board_l_spec.py`,
regenerate both boards, then re-pin the affected `PROJECT_STATE` records — the
`src-*-generator` sources in `component-al8860mp-13` and
`component-honglitronic-hl-am-2835h421w-s1-08-hr3` are sha256-locked to
`board_l_spec.py` at revision `410bc1a`, so `fact-al8860-project-nets`,
`fact-fxl-project-nets`, `fact-ss26-project-nets` and `fact-c210315-topology` cannot be
truthfully updated until the new spec is committed and re-hashed. `validate.py` also locks
the AL8860 pin map in `fixtures/golden/real-pin-maps.json`. Do the spec edit and the
evidence re-pin in one commit, or the gate goes red.

## Evidence the registry is missing but the design leans on

Three numbers the design depends on are asserted in prose and retained in no fact file.
None is a wiring error; all three need a source refresh (`validate.py --online`) rather
than a hardware change.

| Gap | Status | Action |
|---|---|---|
| AL8860 CTRL soft-start rate and the ≤1.67 µA bias bound behind the safe default-OFF proof | **Load-bearing.** Not retained, and a *typical* soft-start figure cannot bound a worst case even once retained — the part publishes no guaranteed maximum CTRL source current | Retain the row as typical, keep Gate 3's CTRL measurement as the real gate, and decide whether safe default-OFF needs a hardware guarantee rather than a resistor |
| `PA0 = TIM2_CH1`, `PA1 = TIM2_CH2` (AF2) — the whole hardware-quadrature knob | Not retained (`grep -r TIM2 .claude/skills/` is empty), but independently confirmed correct against ST's datasheet. No mitigation needed | Retain the AF-mapping row on `rec-c529334` |
| STM32G031 option-byte boot default used to justify omitting a BOOT0 strap | Not retained; `fact-c529334-boot` explicitly says the programmed values are unknown. Independently confirmed that no strap is needed given the SWD/NRST header | Retain RM0444 + errata, and keep an option-byte readback as a production gate |

## Risks carried into the KiCad phase

| Risk | Severity | Mitigation |
|---|---|---|
| Board P's topology has **never** run on hardware — four PCBA orders failed before it was fixed on paper | High | Gates 1 and 2 exist precisely for this. Budget for a second Board P spin |
| CPL rotation over-correction on EasyEDA-derived footprints | High — it silently produces a mis-assembled board | Explicit Corrections Manager overrides plus a manual CPL review; do not rely on JLCPCB's pre-production check |
| Charger incompatibility | Medium | Buy or borrow a single-port PD charger with an explicit 15 V PDO before ordering boards, so a negotiation failure is not ambiguous between "bad board" and "bad charger" |
| SMAJ20A stock (3,770 units, needed on both boards) | Medium | Order both boards' quantity in one go; do not substitute a different standoff voltage |
| String imbalance worse than predicted | Medium | Raise the ballast value; costs duty-cycle headroom. Detected at Gate 4, before firmware |
| The 5% analog dimming floor reads as a visible snap to off | Low | Bias the modulation to stay above the floor, or accept the ember-never-goes-black behaviour |
| Enclosure thermal behaviour is completely unmodelled | Low for the prototype, real for the finished lamp | Enclosure is out of scope for this epic; the thermal derate hook and RT1 exist so the firmware can respond once it is not |

## References

- [Lessons Carried From zudo-pd](/docs/power/lessons-from-zudo-pd/) — NVM trap, bring-up sequence, CPL rotation, Extended-fee economics
- [Charger Compatibility](/docs/power/charger-compatibility/) — the 15 V-PDO purchase rule and the tested-charger evidence
- [Board L](./board-l.mdx) — the design these gates are validating
- [Final BOM](./bom.mdx) — what to order, and the stock lines to re-check first

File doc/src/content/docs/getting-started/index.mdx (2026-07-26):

---
title: Getting Started
sidebar_position: 1
---

Welcome to zudo-led-lamp. Choose a topic below to get started.

<CategoryNav category="getting-started" />

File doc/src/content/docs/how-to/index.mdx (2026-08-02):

---
title: How-To
sidebar_position: 1
---

Operational runbooks for this repository — hosting, CI, and deployment — plus the
guide to reusing this site's evidence-projection pattern in another project.

<CategoryNav category="how-to" />

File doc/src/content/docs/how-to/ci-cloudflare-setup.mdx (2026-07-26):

---
title: Cloudflare Hosting & CI Setup
sidebar_position: 2
---

How the `doc/` site is hosted on Cloudflare Workers, and the human step
that turns on CI deploys.

:::tip[Status: fully configured]
`CLOUDFLARE_API_TOKEN` and `CLOUDFLARE_ACCOUNT_ID` are both set, and the
pipeline is verified end-to-end — production and PR previews both deploy
from CI. The manual token steps below are kept as the runbook for rotating
the token or re-creating it in another repo.
:::

## What's already configured

- **Hosting.** The site deploys to Cloudflare Workers static assets
  (`doc/wrangler.toml`, worker name `zudo-led-lamp`), served at the custom
  domain `https://zudo-led-lamp.takazudomodular.com/`. The
  `[[routes]]`/`custom_domain = true` entry and `workers_dev = true` are
  fully declarative — a plain `wrangler deploy` attaches both the custom
  domain and the `*.workers.dev` subdomain on its own; no manual Cloudflare
  API call is needed. This was verified with the first production deploy
  (done manually from an OAuth-authenticated local `wrangler`, from this
  worktree) — the site is already live.
- **`doc/zfb.config.ts`** sets `siteUrl` to the same host as the
  `wrangler.toml` route, and `adapter: "@takazudo/zfb-adapter-cloudflare"`
  so `pnpm build` emits `dist/_worker.js`.
- **Versions are pinned.** `doc/package.json` pins `wrangler` as an exact
  devDependency and `packageManager` (pnpm). CI resolves the wrangler
  version it runs from that pin, so a `wrangler` upgrade is a normal
  dependency bump, not a silent CI drift.
- **`.github/workflows/main-deploy.yml`** — on every push to `main` that
  touches `doc/`: install, type check, build, then deploy to production.
- **`.github/workflows/pr-checks.yml`** — on every PR targeting `main` or
  a `base/**` worktree branch that touches `doc/`: install, type check,
  build, then deploy a preview (`wrangler versions upload --preview-alias
  pr-<N>`) and post/update a sticky PR comment with the preview URL.
- **Secret gating.** Both workflows read a secret-readiness step before
  touching Cloudflare — if `CLOUDFLARE_API_TOKEN` isn't set yet, the
  deploy/preview steps are skipped with an explicit `::notice::`, and the
  job still finishes **green**. Nothing goes red just because the token is
  missing.
- **`CLOUDFLARE_ACCOUNT_ID`** repo secret is already set (from `wrangler
  whoami` on an authorized local session).

## The manual token step (done — kept as a runbook)

CI cannot deploy or produce PR previews until `CLOUDFLARE_API_TOKEN` exists
as a repo secret. This has been done; the steps remain here for rotating the
token, since creating one needs a human with Cloudflare dashboard access:

1. Go to [Cloudflare Dashboard → My Profile → API
   Tokens](https://dash.cloudflare.com/profile/api-tokens) → **Create
   Token**.
2. Use the **"Edit Cloudflare Workers"** template. It already grants
   `Account → Workers Scripts → Edit` and `Zone → Workers Routes → Edit` —
   the pair `wrangler deploy` needs to both upload the worker and attach the
   custom domain declared in `wrangler.toml` (no separate Cloudflare API
   "cutover" step exists in this repo; the domain attach happens through
   `wrangler deploy` itself). When the token-creation UI asks for **Zone
   Resources**, make sure it includes `takazudomodular.com` — a token scoped
   to "All zones from an account" or explicitly excluding that zone will
   fail the domain attach with a permission error.
3. Set the secret:
   ```sh
   gh secret set CLOUDFLARE_API_TOKEN --repo Takazudo/zudo-led-lamp
   ```

## Smoke test

Open any pull request that touches `doc/`. Expect `pr-checks.yml` to post a
sticky comment on the PR:

- **Before the token exists:** the comment says "Preview pending" — this is
  expected, not a bug.
- **After the token exists:** the comment updates in place with a working
  `https://pr-<N>-zudo-led-lamp.<subdomain>.workers.dev` preview link.

Either way, the PR check itself should be green — only the presence of a
working preview link changes.

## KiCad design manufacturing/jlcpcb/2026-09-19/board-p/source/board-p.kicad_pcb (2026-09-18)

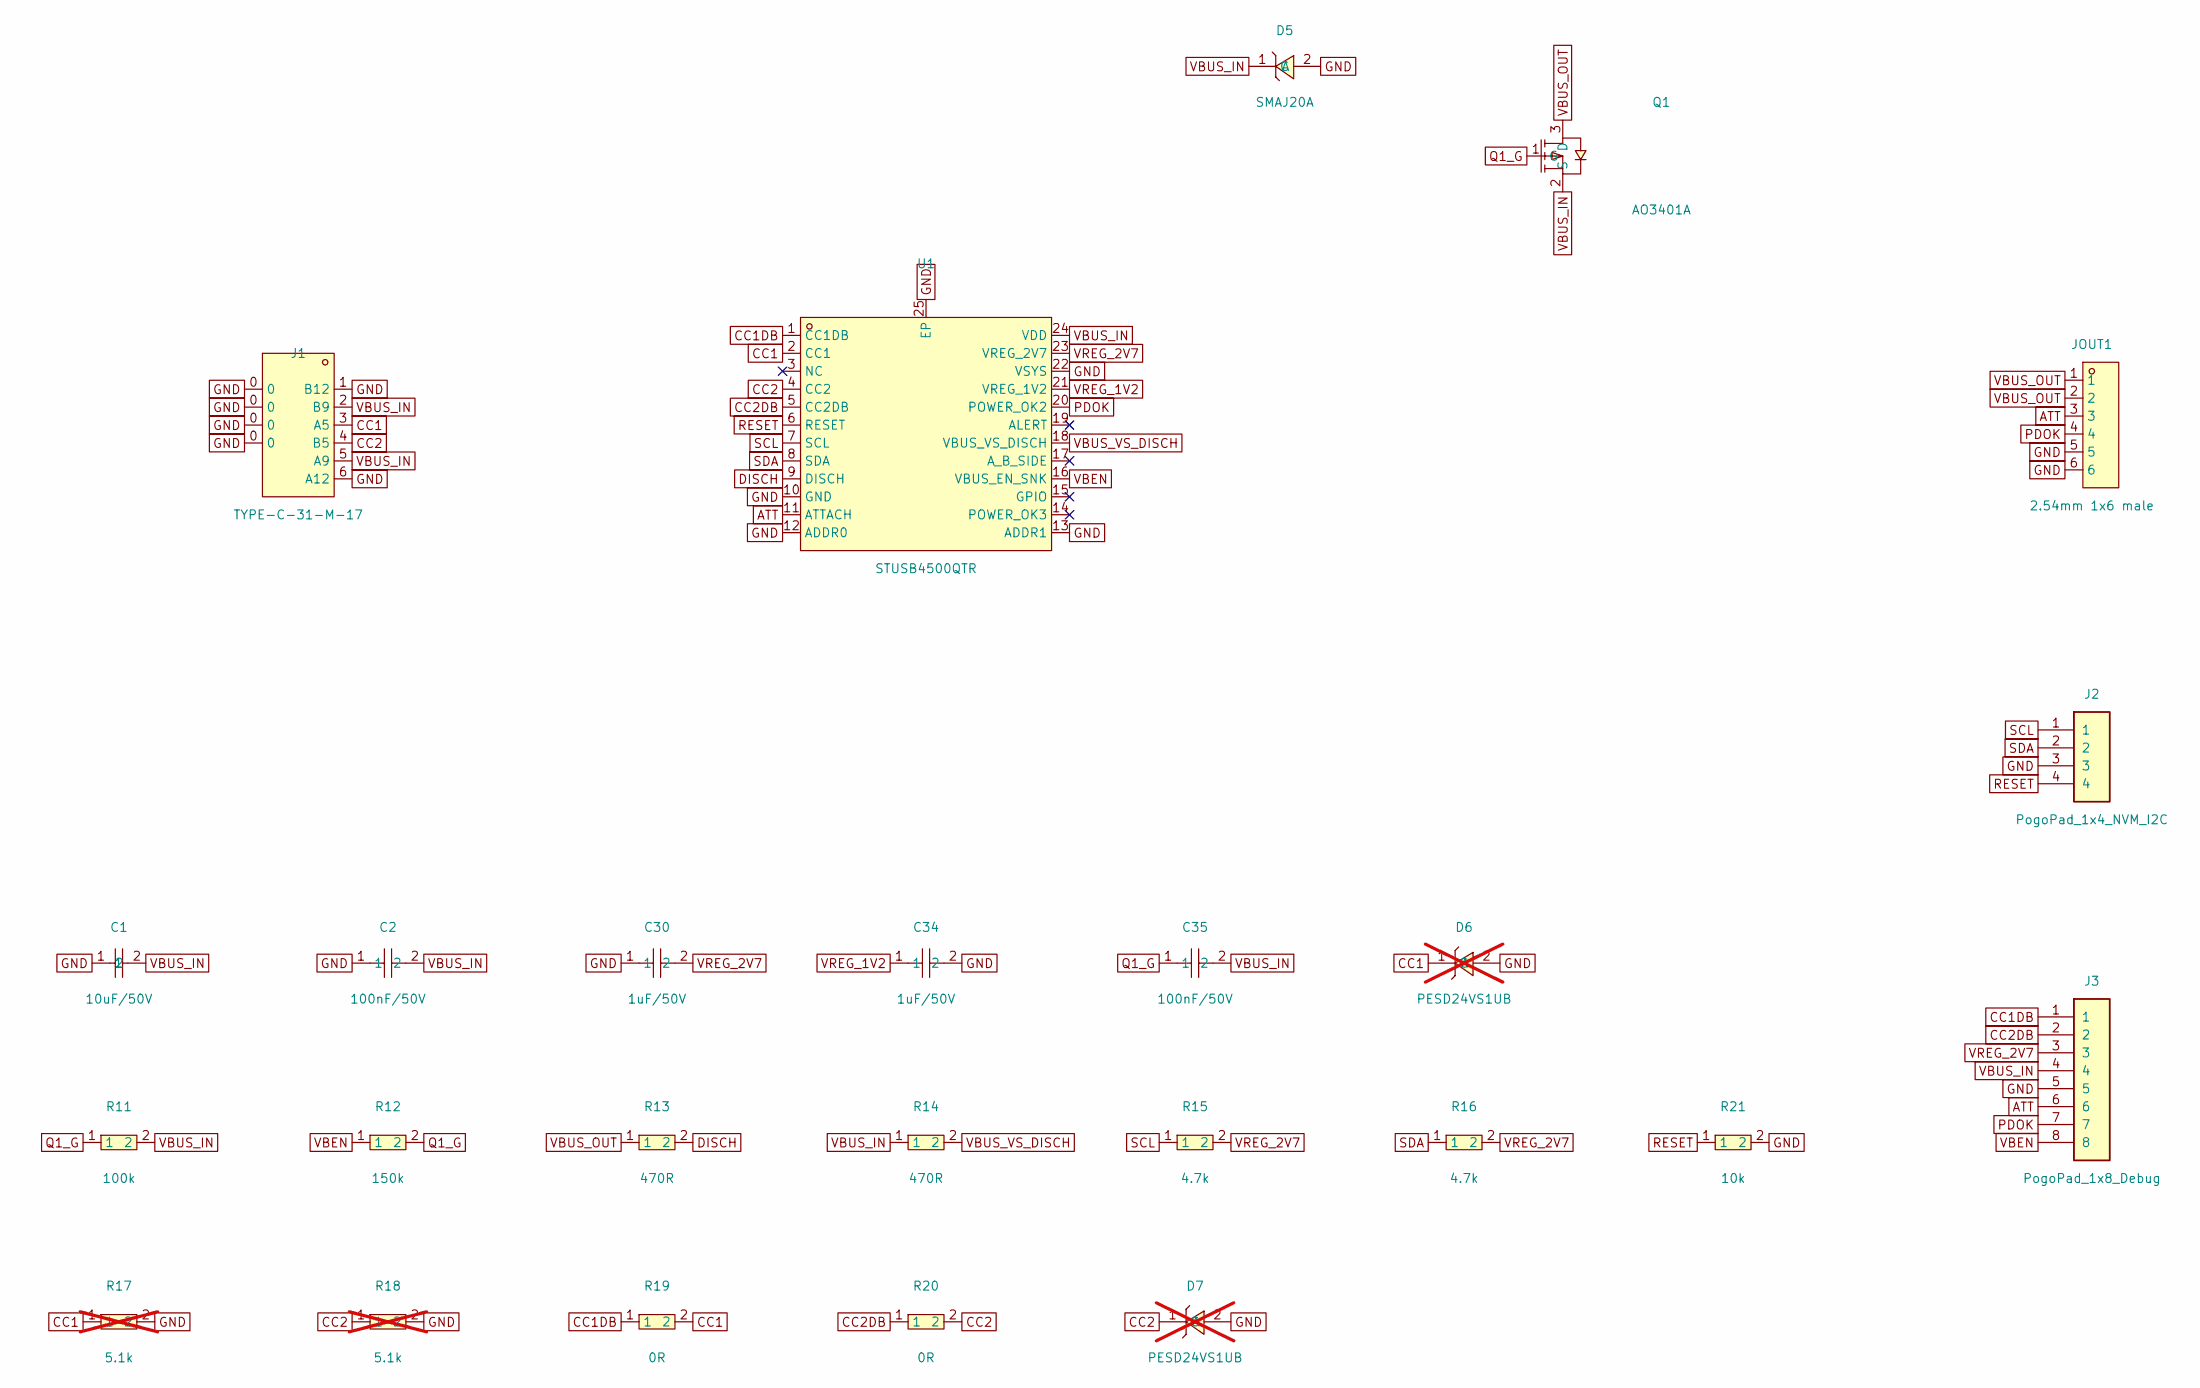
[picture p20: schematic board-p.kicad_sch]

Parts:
C1: 10uF/50V; C1206; LCSC C13585
C2, C35: 100nF/50V; C0603; LCSC C14663
C30, C34: 1uF/50V; C0603; LCSC C15849
D5: SMAJ20A; SMA_L4.2-W2.6-LS5.3-RD; LCSC C571370
D6, D7: PESD24VS1UB; SOD-523_L1.2-W0.8-LS1.6-RD; LCSC C85382; not fitted
J1: TYPE-C-31-M-17; USB-C-SMD_10P-P1.00-L6.8-W8.9; LCSC C283540
J2: PogoPad_1x4_NVM_I2C; PogoPad_1x04_P2.54mm
J3: PogoPad_1x8_Debug; PogoPad_1x08_P2.54mm
JOUT1: 2.54mm 1x6 male; HDR-TH_6P-P2.54-V-M; LCSC C492405
Q1: AO3401A; SOT-23_L2.9-W1.3-P1.90-LS2.4-BR; LCSC C347476
R11: 100k; R0603; LCSC C25803
R12: 150k; R0603; LCSC C22807
R13, R14: 470R; R0603; LCSC C23179
R15, R16: 4.7k; R0603; LCSC C23162
R17, R18: 5.1k; R0603; LCSC C23186; not fitted
R19, R20: 0R; R0603; LCSC C21189
R21: 10k; R0805; LCSC C17414
U1: STUSB4500QTR; QFN-24_L4.0-W4.0-P0.50-BL-EP2.8; LCSC C2678061

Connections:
ATT: J3.6, JOUT1.3, U1.11 (ATTACH)
CC1: D6.1 (C), J1.3 (A5), R17.1, R19.2, U1.2 (CC1)
CC1DB: J3.1, R19.1, U1.1 (CC1DB)
CC2: D7.1 (C), J1.4 (B5), R18.1, R20.2, U1.4 (CC2)
CC2DB: J3.2, R20.1, U1.5 (CC2DB)
DISCH: R13.2, U1.9 (DISCH)
GND: C1.1, C2.1, C30.1, C34.2, D5.2 (A), D6.2 (A), D7.2 (A), J1.0, J1.1 (B12), J1.6 (A12), J2.3, J3.5, JOUT1.5, JOUT1.6, R17.2, R18.2, R21.2, U1.10 (GND), U1.12 (ADDR0), U1.13 (ADDR1), U1.22 (VSYS), U1.25 (EP)
PDOK: J3.7, JOUT1.4, U1.20 (POWER_OK2)
Q1_G: C35.1, Q1.1 (G), R11.1, R12.2
RESET: J2.4, R21.1, U1.6 (RESET)
SCL: J2.1, R15.1, U1.7 (SCL)
SDA: J2.2, R16.1, U1.8 (SDA)
VBEN: J3.8, R12.1, U1.16 (VBUS_EN_SNK)
VBUS_IN: C1.2, C2.2, C35.2, D5.1 (C), J1.2 (B9), J1.5 (A9), J3.4, Q1.2 (S), R11.2, R14.1, U1.24 (VDD)
VBUS_OUT: JOUT1.1, JOUT1.2, Q1.3 (D), R13.1
VBUS_VS_DISCH: R14.2, U1.18 (VBUS_VS_DISCH)
VREG_1V2: C34.1, U1.21 (VREG_1V2)
VREG_2V7: C30.2, J3.3, R15.2, R16.2, U1.23 (VREG_2V7)

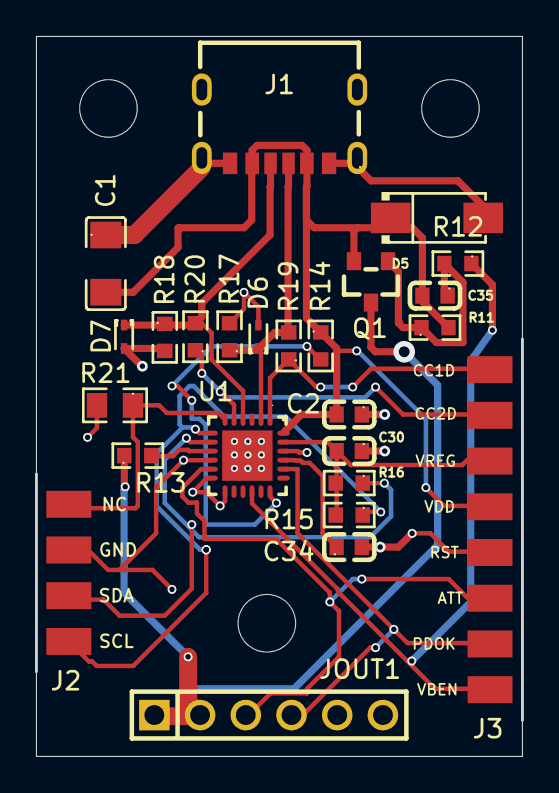
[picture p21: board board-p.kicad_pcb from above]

Board: 2 copper layers, 27.0 x 40.0 mm, 25 parts (0 on the bottom side), 18 nets.

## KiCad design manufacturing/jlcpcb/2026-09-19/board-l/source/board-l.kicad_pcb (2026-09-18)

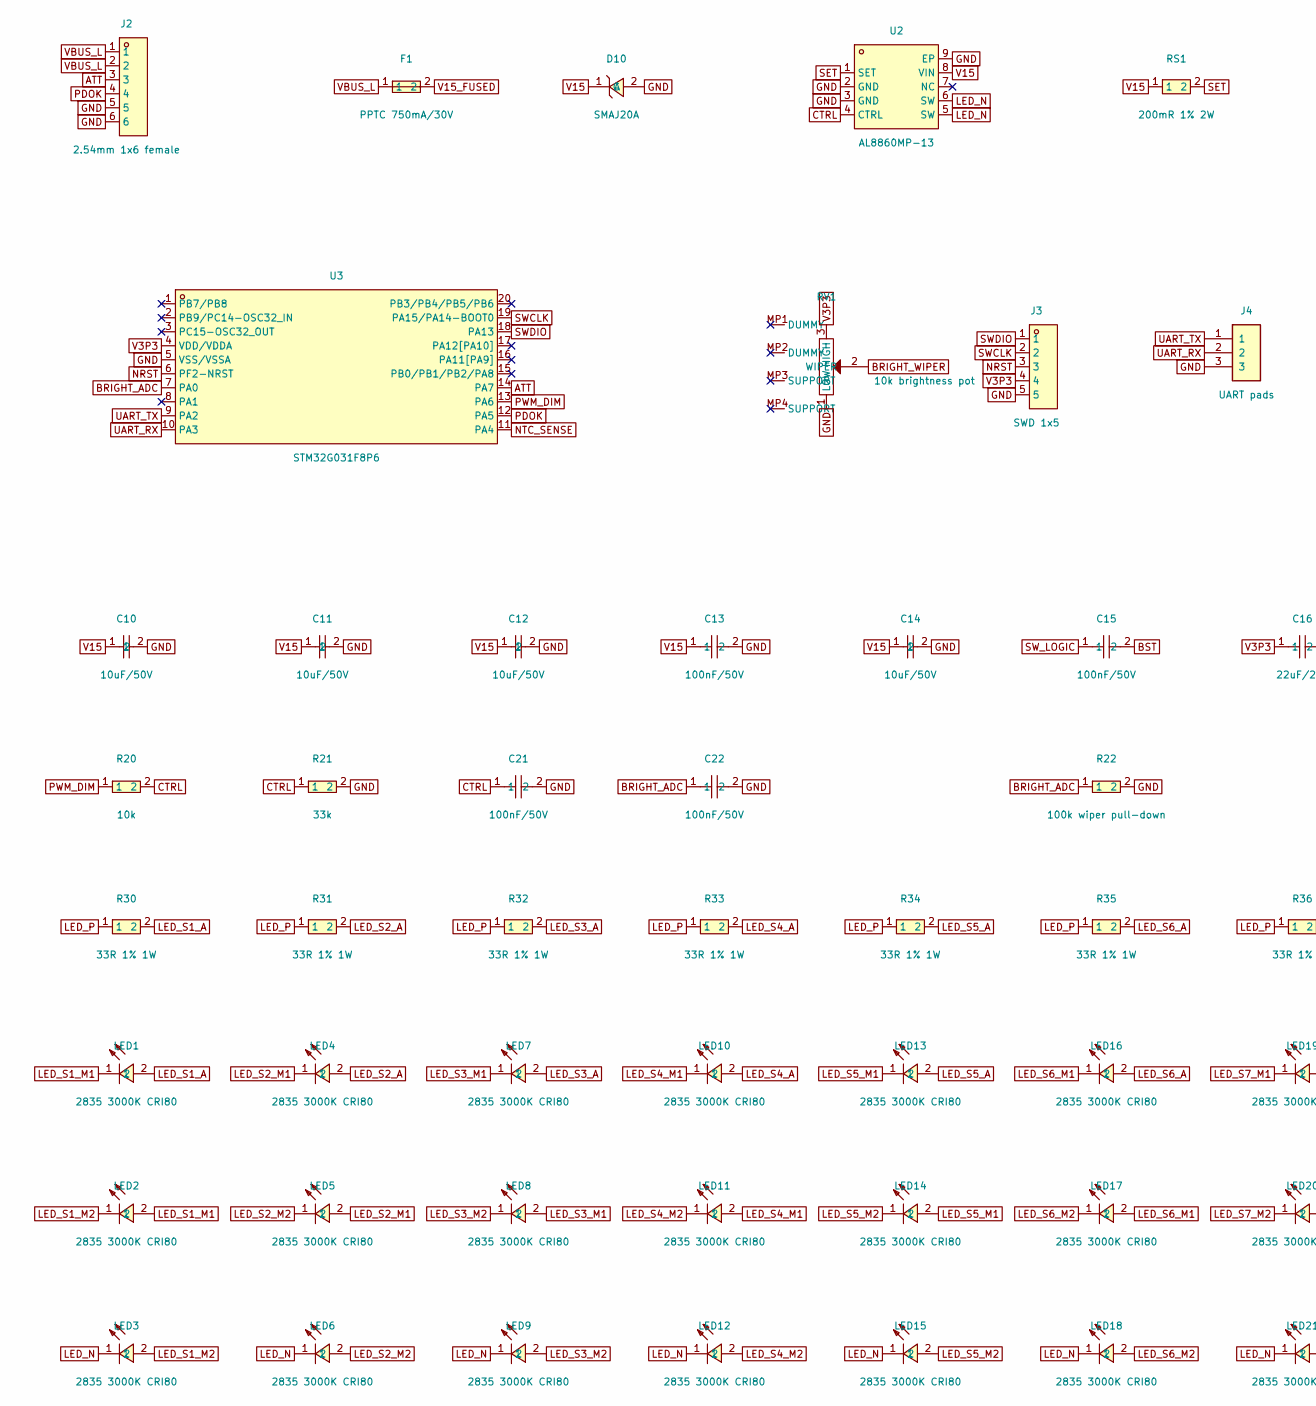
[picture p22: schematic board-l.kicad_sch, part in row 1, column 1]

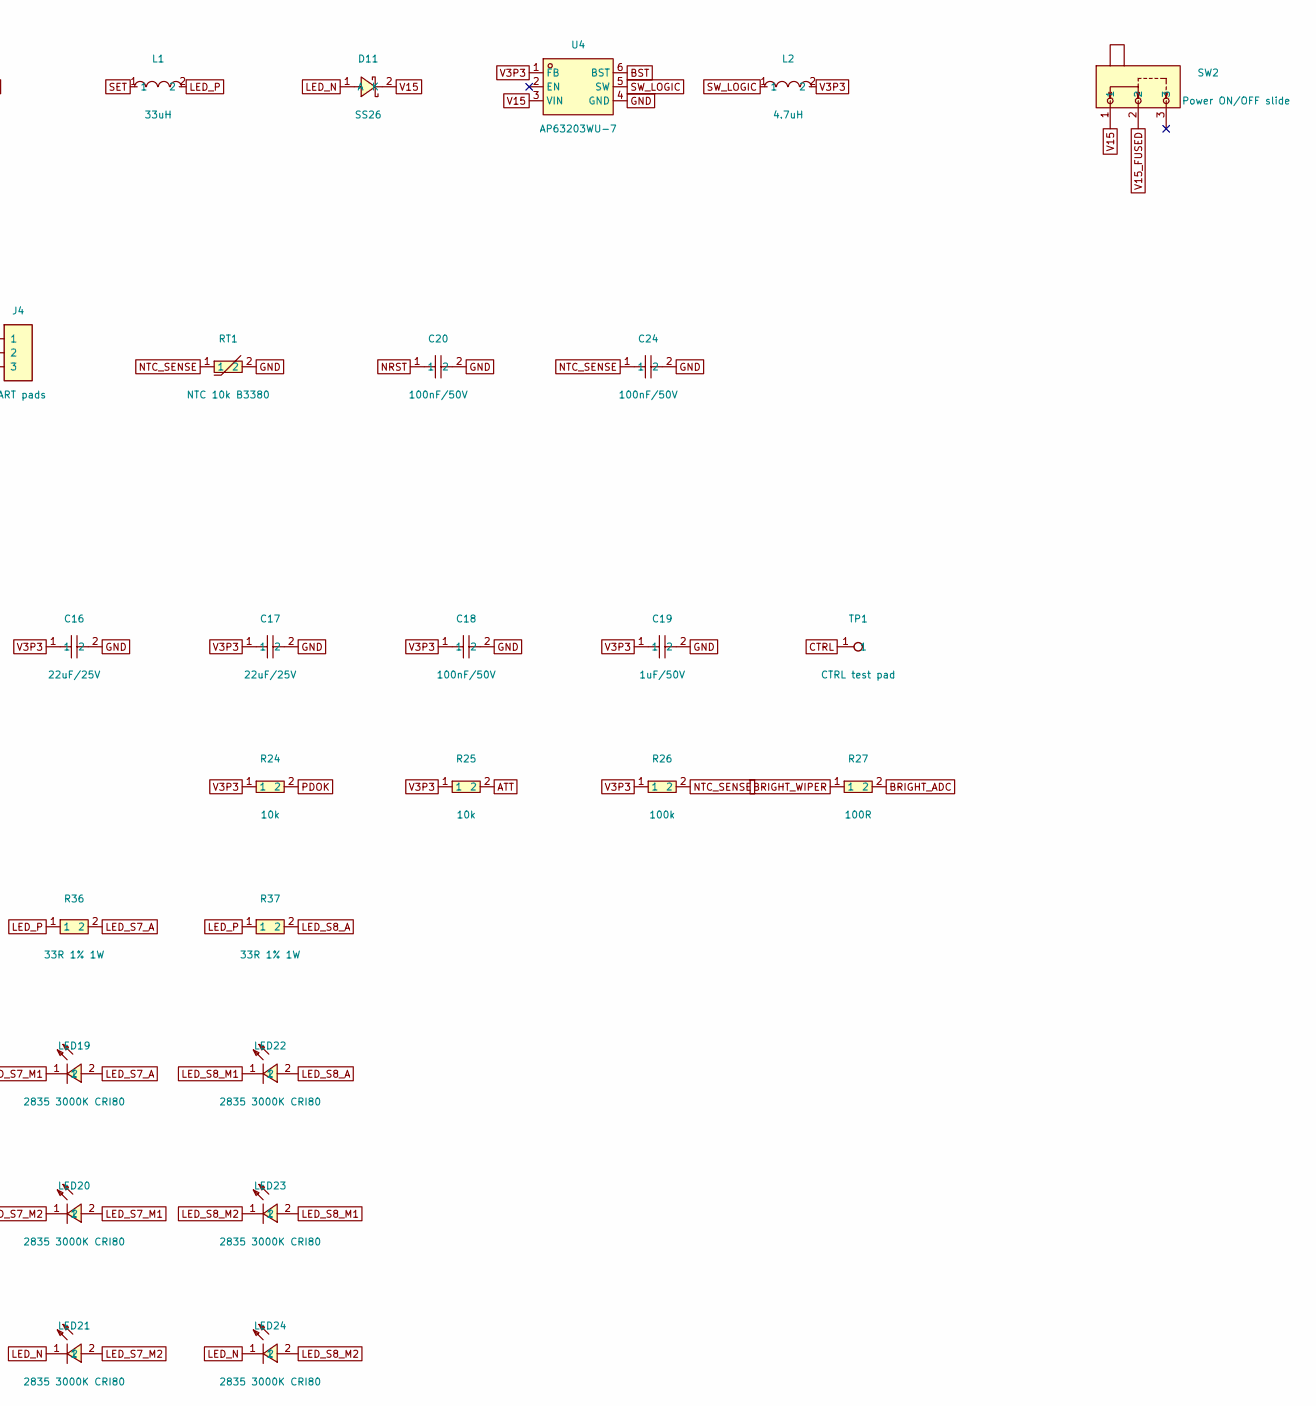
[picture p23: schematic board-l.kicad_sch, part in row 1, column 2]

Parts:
C10, C11, C12, C14: 10uF/50V; C1206; LCSC C13585
C13, C15, C18, C20, C21, C22, C24: 100nF/50V; C0603; LCSC C14663
C16, C17: 22uF/25V; C0805; LCSC C45783
C19: 1uF/50V; C0603; LCSC C15849
D10: SMAJ20A; SMA_L4.2-W2.6-LS5.3-RD; LCSC C571370
D11: SS26; SMA_L4.3-W2.6-LS5.0-FD; LCSC C7420363
F1: PPTC 750mA/30V; F1206; LCSC C976305
J2: 2.54mm 1x6 female; HDR-TH_6P-P2.54-V-F; LCSC C2832269
J3: SWD 1x5; HDR-TH_5P-P2.54-V-M; LCSC C492404
J4: UART pads; PogoPad_1x03_P2.54mm
L1: 33uH; IND-SMD_L7.0-W6.6_FXL0630; LCSC C177245
L2: 4.7uH; IND-SMD_L4.0-W4.0_FNR40XXS; LCSC C167874
LED1, LED2, LED3, LED4, LED5, LED6, LED7, LED8, LED9, LED10, LED11, LED12, LED13, LED14, LED15, LED16, LED17, LED18, LED19, LED20, LED21, LED22, LED23, LED24: 2835 3000K CRI80; LED-SMD_L3.3-W2.8-RD; LCSC C210315
R20, R24, R25: 10k; R0805; LCSC C17414
R21: 33k; R0603; LCSC C4216
R22: 100k wiper pull-down; R0603; LCSC C25803
R26: 100k; R0603; LCSC C25803
R27: 100R; R0603; LCSC C22775
R30, R31, R32, R33, R34, R35, R36, R37: 33R 1% 1W; R2512; LCSC C2934070
RS1: 200mR 1% 2W; R2512; LCSC C459674
RT1: NTC 10k B3380; R0603; LCSC C13564
RV1: 10k brightness pot; POT-TH_RK10J11E0034; LCSC C470643
SW2: Power ON/OFF slide; SW-TH_SS-12D01-G020; LCSC C5446803
TP1: CTRL test pad; TestPad_D1.5mm
U2: AL8860MP-13; MSOP-8_L3.0-W3.0-P0.65-LS4.9-BL-EP1.8; LCSC C500782
U3: STM32G031F8P6; TSSOP-20_L6.5-W4.4-P0.65-LS6.4-BL; LCSC C529334
U4: AP63203WU-7; TSOT-26_L2.9-W1.6-P0.95-LS2.8-BL; LCSC C780769

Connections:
ATT: J2.3, R25.2, U3.14 (PA7)
BRIGHT_ADC: C22.1, R22.1, R27.2, U3.7 (PA0)
BRIGHT_WIPER: R27.1, RV1.2 (WIPER)
BST: C15.2, U4.6 (BST)
CTRL: C21.1, R20.2, R21.1, TP1.1 (1_1), U2.4 (CTRL)
GND: C10.2, C11.2, C12.2, C13.2, C14.2, C16.2, C17.2, C18.2, C19.2, C20.2, C21.2, C22.2, C24.2, D10.2 (A), J2.5, J2.6, J3.5, J4.3, R21.2, R22.2, RT1.2, RV1.1 (LOW), U2.2 (GND), U2.3 (GND), U2.9 (EP), U3.5 (VSS/VSSA), U4.4 (GND)
LED_N: D11.1 (A), LED3.1, LED6.1, LED9.1, LED12.1, LED15.1, LED18.1, LED21.1, LED24.1, U2.5 (SW), U2.6 (SW)
LED_P: L1.2, R30.1, R31.1, R32.1, R33.1, R34.1, R35.1, R36.1, R37.1
LED_S1_A: LED1.2, R30.2
LED_S1_M1: LED1.1, LED2.2
LED_S1_M2: LED2.1, LED3.2
LED_S2_A: LED4.2, R31.2
LED_S2_M1: LED4.1, LED5.2
LED_S2_M2: LED5.1, LED6.2
LED_S3_A: LED7.2, R32.2
LED_S3_M1: LED7.1, LED8.2
LED_S3_M2: LED8.1, LED9.2
LED_S4_A: LED10.2, R33.2
LED_S4_M1: LED10.1, LED11.2
LED_S4_M2: LED11.1, LED12.2
LED_S5_A: LED13.2, R34.2
LED_S5_M1: LED13.1, LED14.2
LED_S5_M2: LED14.1, LED15.2
LED_S6_A: LED16.2, R35.2
LED_S6_M1: LED16.1, LED17.2
LED_S6_M2: LED17.1, LED18.2
LED_S7_A: LED19.2, R36.2
LED_S7_M1: LED19.1, LED20.2
LED_S7_M2: LED20.1, LED21.2
LED_S8_A: LED22.2, R37.2
LED_S8_M1: LED22.1, LED23.2
LED_S8_M2: LED23.1, LED24.2
NRST: C20.1, J3.3, U3.6 (PF2-NRST)
NTC_SENSE: C24.1, R26.2, RT1.1, U3.11 (PA4)
PDOK: J2.4, R24.2, U3.12 (PA5)
PWM_DIM: R20.1, U3.13 (PA6)
SET: L1.1, RS1.2, U2.1 (SET)
SWCLK: J3.2, U3.19 (PA15/PA14-BOOT0)
SWDIO: J3.1, U3.18 (PA13)
SW_LOGIC: C15.1, L2.1, U4.5 (SW)
UART_RX: J4.2, U3.10 (PA3)
UART_TX: J4.1, U3.9 (PA2)
V3P3: C16.1, C17.1, C18.1, C19.1, J3.4, L2.2, R24.1, R25.1, R26.1, RV1.3 (HIGH), U3.4 (VDD/VDDA), U4.1 (FB)
V15: C10.1, C11.1, C12.1, C13.1, C14.1, D10.1 (C), D11.2 (K), RS1.1, SW2.1, U2.8 (VIN), U4.3 (VIN)
V15_FUSED: F1.2, SW2.2
VBUS_L: F1.1, J2.1, J2.2

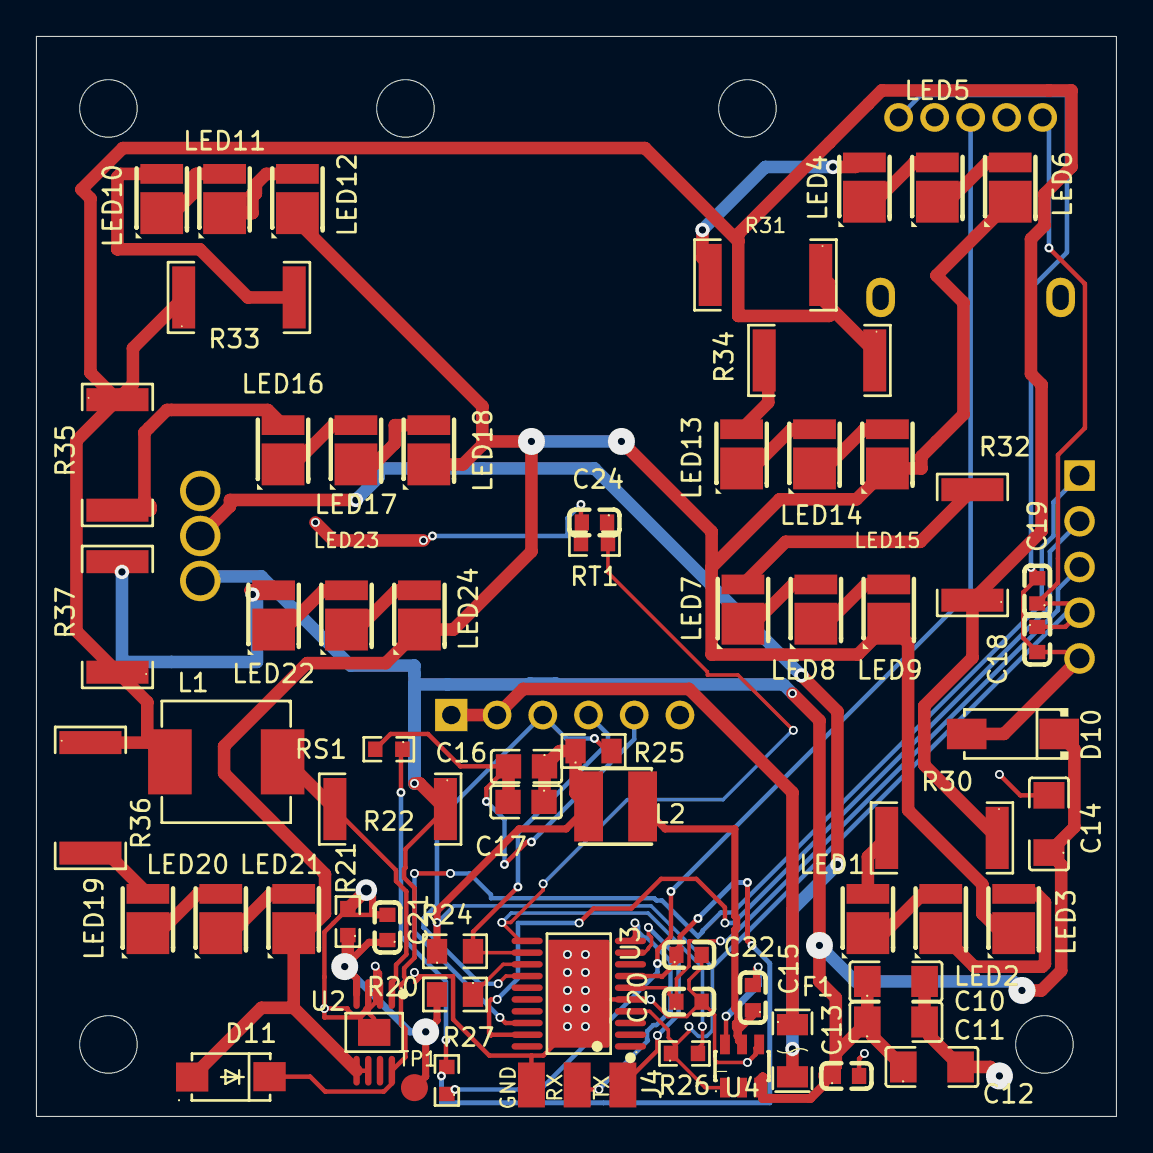
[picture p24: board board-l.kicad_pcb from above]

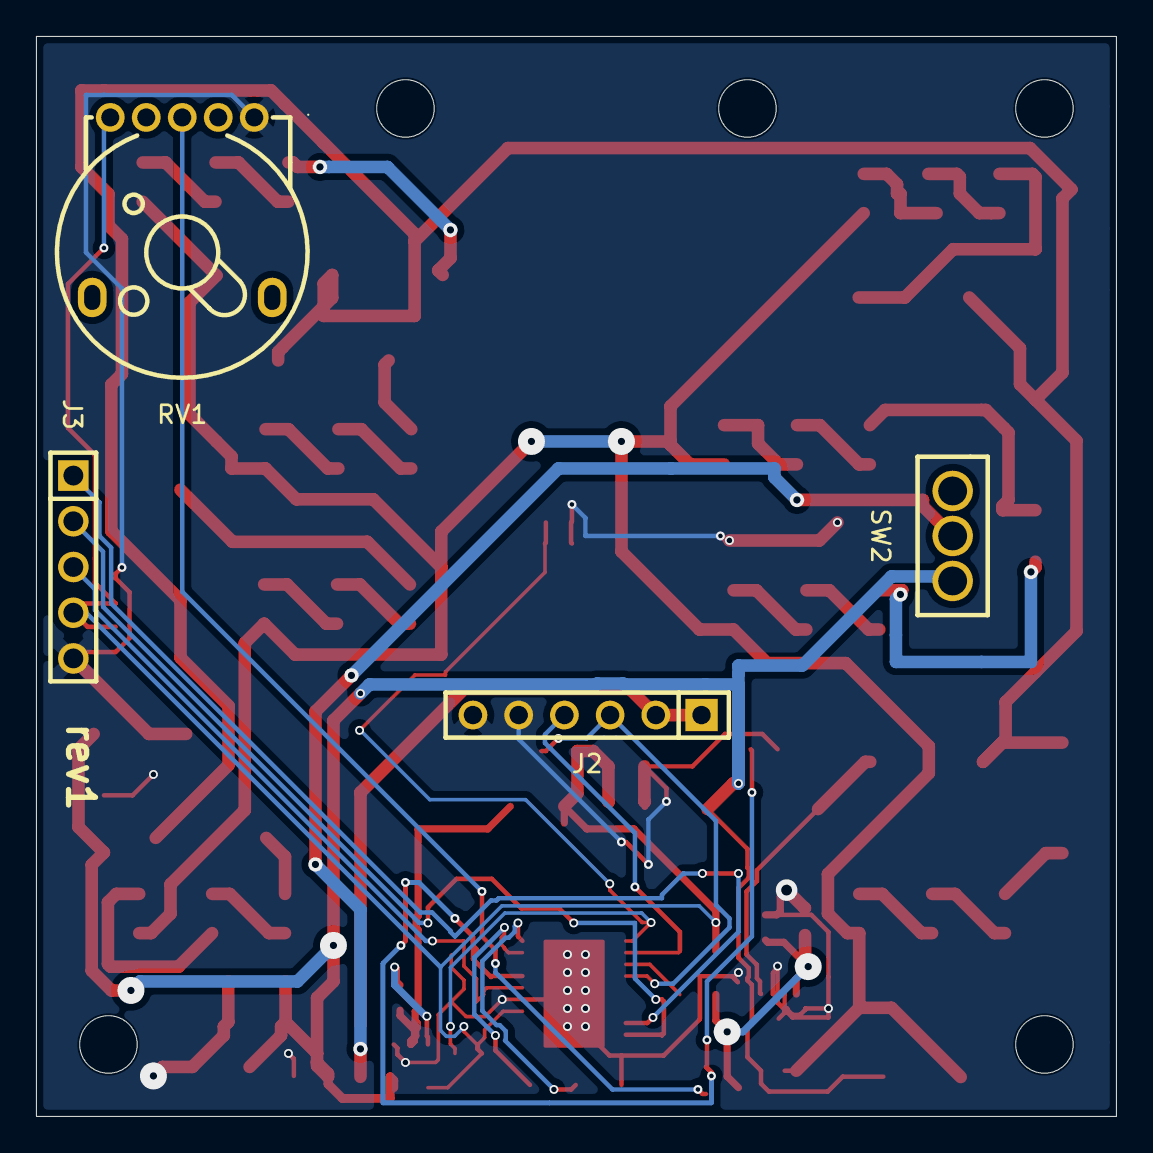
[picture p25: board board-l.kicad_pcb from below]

Board: 2 copper layers, 60.0 x 60.0 mm, 69 parts (4 on the bottom side), 46 nets.

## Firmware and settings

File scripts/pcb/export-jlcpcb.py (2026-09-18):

#!/usr/bin/env python3
"""Export the all-connectors-fitted JLCPCB order without changing design sources."""

import argparse
import collections
import csv
import hashlib
import importlib
import importlib.util
import json
import math
import os
from pathlib import Path
import re
import shutil
import subprocess
import sys
import zipfile

ROOT = Path(__file__).resolve().parents[2]
sys.path.insert(0, str(ROOT / 'scripts/schgen'))
from sexp import atom, find_all, load

BOARDS = ('board-p', 'board-l', 'swd-adapter')
FIT = {'board-p': set(), 'board-l': {'J3'}, 'swd-adapter': {'J1', 'J2'}}
LAYERS = 'F.Cu,B.Cu,F.Mask,B.Mask,F.Silkscreen,B.Silkscreen,Edge.Cuts,F.Paste,B.Paste'


def require(condition, message):
    if not condition:
        raise ValueError(message)


def props(node):
    return {atom(p[1]): atom(p[2]) for p in find_all(node, 'property')}


def natural(ref):
    return [int(v) if v.isdigit() else v for v in re.split(r'(\d+)', ref)]


def write_csv(path, columns, rows, **kwargs):
    with path.open('w', newline='') as stream:
        writer = csv.DictWriter(stream, fieldnames=columns, **kwargs)
        writer.writeheader()
        writer.writerows(rows)


def digest(path):
    return hashlib.sha256(path.read_bytes()).hexdigest()


def run(args, log):
    result = subprocess.run([str(v) for v in args], cwd=ROOT, text=True, capture_output=True)
    with log.open('a') as stream:
        stream.write('\n$ ' + ' '.join(str(v) for v in args) + '\n' + result.stdout + result.stderr)
    require(result.returncode == 0, f'Command failed ({result.returncode}); see {log}: {args}')
    return result.stdout.strip()


def snapshot_text(text, kind, board, identities, changes):
    pattern = r'(?ms)^\t\(' + kind + r'(?: |\n).*?^\t\)'

    def update(match):
        block = match.group()
        ref_match = re.search(r'\(property "Reference" "([^"]+)"', block)
        if not ref_match:
            return block
        ref = ref_match[1]
        if kind == 'footprint':
            def clean_line(line_match):
                line = line_match.group()
                start = re.search(r'\(start ([^)]*)\)', line)
                end = re.search(r'\(end ([^)]*)\)', line)
                if start and end and start[1] == end[1] and re.search(r'\(layer "[FB]\.SilkS"\)', line):
                    changes.append({'file_type': kind, 'ref': ref, 'field': 'degenerate_silkscreen_line',
                                    'old': start[1], 'new': 'omitted zero-length line'})
                    return ''
                return line
            block = re.sub(r'(?ms)^\t\t\(fp_line\n.*?^\t\t\)\n?', clean_line, block)
        if ref in identities:
            lcsc = identities[ref]['lcsc']
            for name in ('LCSC', 'LCSC Part'):
                prop = r'(\(property "' + name + r'" ")([^"]*)(")'
                old = re.search(prop, block)
                if old and old[2] != lcsc:
                    changes.append({'file_type': kind, 'ref': ref, 'field': name,
                                    'old': old[2], 'new': lcsc})
                    block = re.sub(prop, lambda m: m[1] + lcsc + m[3], block)
        if ref in FIT[board]:
            if kind == 'footprint':
                block, count = re.subn(r'(\(attr[^)]*)\bdnp\b', r'\1', block)
            else:
                block, count = re.subn(r'\(dnp yes\)', '(dnp no)', block)
            require(count == 1, f'{board}/{ref}: expected one DNP flag in {kind}')
            block = block.replace(' (hand-fit)', '')
        return block

    return re.sub(pattern, update, text)


def export_board(board, output, cli, inventory, converter):
    dest = output / board
    require(not dest.exists(), f'Refusing to overwrite existing release: {dest}')
    source = dest / 'source'
    raw = dest / 'raw'
    gerbers = dest / 'gerbers'
    checks = dest / 'checks'
    for folder in (source, raw, gerbers, checks):
        folder.mkdir(parents=True)
    log = checks / 'commands.log'
    spec = importlib.import_module(board.replace('-', '_') + '_spec')
    identities = {p['refdes']: line for line in inventory['lines']
                  for p in line['placements'] if p['board'] == board}
    original = ROOT / 'boards' / board
    pcb = load(original / (board + '.kicad_pcb'))
    footprints = {}
    for fp in find_all(pcb, 'footprint'):
        ref = props(fp)['Reference']
        if ref in spec.COMPONENTS:
            require(ref not in footprints, f'Duplicate {board}/{ref}')
            footprints[ref] = fp
        else:
            require('exclude_from_bom' in [atom(v) for v in find_all(fp, 'attr')[0][1:]],
                    f'Unknown assembly footprint {board}/{ref}')
    require(set(footprints) == set(spec.COMPONENTS), f'{board}: spec/PCB reference mismatch')
    included = {}
    excluded = []
    for ref, component in spec.COMPONENTS.items():
        _, value, lcsc, footprint, dnp, _ = component
        fp = footprints[ref]
        attrs = [atom(v) for v in find_all(fp, 'attr')[0][1:]]
        require(atom(fp[1]) == footprint, f'{board}/{ref}: footprint mismatch')
        require(('dnp' in attrs) == dnp, f'{board}/{ref}: source population mismatch')
        if not lcsc:
            require(any(p['board'] == board and p['refdes'] == ref for p in inventory['exclusions']),
                    f'Unregistered bare pad {board}/{ref}')
            excluded.append({'Designator': ref, 'Reason': 'Bare copper; no component', 'LCSC': ''})
            continue
        require(identities[ref]['lcsc'] == lcsc, f'{board}/{ref}: registry identity mismatch')
        require(props(fp).get('LCSC') == lcsc, f'{board}/{ref}: schematic LCSC/PCB mismatch')
        if dnp and ref not in FIT[board]:
            excluded.append({'Designator': ref, 'Reason': 'Intentional circuit DNP', 'LCSC': lcsc})
        else:
            require(not {'exclude_from_bom', 'exclude_from_pos_files'} & set(attrs),
                    f'{board}/{ref}: fitted part is excluded')
            included[ref] = (identities[ref]['mpn'], lcsc, footprint.split(':')[-1])
    changes = []
    hashes = {}
    for suffix in ('.kicad_pcb', '.kicad_sch', '.kicad_pro'):
        path = original / (board + suffix)
        hashes[str(path.relative_to(ROOT))] = digest(path)
        content = path.read_text()
        if suffix in ('.kicad_pcb', '.kicad_sch'):
            content = snapshot_text(content, 'footprint' if suffix == '.kicad_pcb' else 'symbol',
                                    board, identities, changes)
        # Keep project-relative library/model links valid in the retained release snapshot.
        root_relative = os.path.relpath(ROOT, source)
        content = content.replace('${KIPRJMOD}/../../', '${KIPRJMOD}/' + root_relative + '/')
        (source / path.name).write_text(content)
    for name in ('fp-lib-table', 'sym-lib-table'):
        content = (original / name).read_text().replace('${KIPRJMOD}/../../',
                    '${KIPRJMOD}/' + os.path.relpath(ROOT, source) + '/')
        (source / name).write_text(content)
    board_path = source / (board + '.kicad_pcb')
    sch_path = source / (board + '.kicad_sch')
    run([cli, 'pcb', 'drc', '--refill-zones', '--save-board', '--schematic-parity',
         '--format', 'json', '-o', checks / 'drc.json', board_path], log)
    drc = json.loads((checks / 'drc.json').read_text())
    errors = [v for key in ('violations', 'unconnected_items', 'schematic_parity')
              for v in drc[key] if v['severity'] == 'error']
    require(not errors and not drc['unconnected_items'], f'{board}: DRC errors or unrouted connections')
    require(all(v['type'] == 'extra_footprint' for v in drc['schematic_parity']),
            f'{board}: schematic parity mismatch')
    run([cli, 'sch', 'erc', '--format', 'json', '-o', checks / 'erc.json', sch_path], log)
    erc = json.loads((checks / 'erc.json').read_text())
    erc_violations = [v for sheet in erc['sheets'] for v in sheet['violations']]
    require(not any(v['severity'] == 'error' for v in erc_violations), f'{board}: ERC errors')
    run([cli, 'sch', 'export', 'netlist', '--format', 'kicadsexpr', '-o',
         raw / (board + '.net'), sch_path], log)
    run([sys.executable, ROOT / 'scripts/schgen/verify_netlist.py',
         board.replace('-', '_') + '_spec', raw / (board + '.net')], log)
    if board == 'board-l':
        run([sys.executable, ROOT / 'scripts/schgen/verify_power_switch.py', '--netlist',
             raw / (board + '.net')], log)
    run([cli, 'pcb', 'export', 'gerbers', '-l', LAYERS, '--use-drill-file-origin',
         '--subtract-soldermask', '-o', gerbers, board_path], log)
    run([cli, 'pcb', 'export', 'drill', '--format', 'excellon', '--drill-origin', 'plot',
         '--excellon-units', 'mm', '--excellon-separate-th', '--excellon-oval-format', 'route',
         '-o', gerbers, board_path], log)
    run([cli, 'pcb', 'export', 'pos', '--format', 'csv', '--units', 'mm',
         '--use-drill-file-origin', '--exclude-dnp', '-o', raw / 'positions.csv', board_path], log)
    grouped = collections.defaultdict(list)
    for ref, identity in included.items():
        grouped[identity].append(ref)
    bom_input = [{'Designator': ','.join(sorted(refs, key=natural)), 'Designation': mpn,
                  'Footprint': footprint, 'Quantity': len(refs)}
                 for (mpn, lcsc, footprint), refs in sorted(grouped.items())]
    write_csv(raw / 'bom.csv', ['Designator', 'Designation', 'Footprint', 'Quantity'], bom_input, delimiter=';')
    bom_rows = converter.convert_bom(raw / 'bom.csv', dest / 'bom.csv')
    for row in bom_rows:
        row['JLCPCB Part #'] = included[row['Designator'].split(',')[0]][1]
    write_csv(dest / 'bom.csv', ['Comment', 'Designator', 'Footprint', 'JLCPCB Part #'], bom_rows)
    with (raw / 'positions.csv').open() as stream:
        positions = list(csv.DictReader(stream))
    setup = find_all(pcb, 'setup')[0]
    origin_node = find_all(setup, 'aux_axis_origin')
    ox, oy = [float(atom(v)) for v in origin_node[0][1:]] if origin_node else (0, 0)
    cpl = []
    corrections = json.loads((ROOT / 'manufacturing/jlcpcb-rotation-corrections.json').read_text()).get(board, {})
    require(set(corrections) <= set(included), f'{board}: correction targets an unfitted part')
    for row in positions:
        ref = row['Ref']
        if ref not in included:
            continue
        at = find_all(footprints[ref], 'at')[0]
        x, y = float(row['PosX']), float(row['PosY'])
        require(math.isclose(x, float(atom(at[1])) - ox, abs_tol=0.0001)
                and math.isclose(y, oy - float(atom(at[2])), abs_tol=0.0001),
                f'{board}/{ref}: coordinate/origin mismatch')
        # JLCPCB's KiCad 10 guide preserves exported PosY; it is already Cartesian Y-up.
        correction = corrections.get(ref)
        if correction:
            require(correction['lcsc'] == included[ref][1], f'{board}/{ref}: rotation correction identity changed')
        rotation = (float(row['Rot']) + (correction['offset_degrees'] if correction else 0)) % 360
        cpl.append({'Designator': ref, 'Mid X': f'{x:.4f}mm', 'Mid Y': f'{y:.4f}mm',
                    'Layer': row['Side'].capitalize(), 'Rotation': f'{rotation:g}'})
    require(len(cpl) == len(included) and {r['Designator'] for r in cpl} == set(included),
            f'{board}: BOM/CPL reference mismatch')
    write_csv(dest / 'cpl.csv', ['Designator', 'Mid X', 'Mid Y', 'Layer', 'Rotation'],
              sorted(cpl, key=lambda r: natural(r['Designator'])))
    write_csv(dest / 'excluded.csv', ['Designator', 'Reason', 'LCSC'], excluded)
    for side, layer in [('top', 'F'), ('bottom', 'B')]:
        run([cli, 'pcb', 'export', 'svg', '--mode-single', '--fit-page-to-board',
             '--exclude-drawing-sheet', '--sketch-pads-on-fab-layers',
             '-l', f'{layer}.Cu,{layer}.Fab,{layer}.Silkscreen,Edge.Cuts',
             '-o', dest / f'assembly-{side}.svg', *(['--mirror'] if side == 'bottom' else []), board_path], log)
    files = sorted(gerbers.iterdir())
    require({'.gtl', '.gbl', '.gts', '.gbs', '.gto', '.gbo', '.gm1', '.gtp', '.gbp', '.drl'}
            <= {p.suffix for p in files}, f'{board}: missing fabrication layer')
    for path in files:
        data = path.read_text()
        require(('M30' in data if path.suffix == '.drl' else
                 ('M02*' in data if path.suffix != '.gbrjob' else True)), f'Incomplete {path}')
    with zipfile.ZipFile(dest / f'{board}-gerbers.zip', 'w', zipfile.ZIP_DEFLATED) as archive:
        for path in files:
            archive.write(path, path.name)
    result = {'board': board, 'fitted_components': len(included), 'bom_lines': len(bom_rows),
              'assembly_sides': dict(collections.Counter(r['Layer'] for r in cpl)),
              'population_overrides': sorted(FIT[board]), 'excluded': excluded,
              'source_hashes': hashes, 'normalized_stale_fields': changes,
              'drc_errors': len(errors), 'unconnected': len(drc['unconnected_items']),
              'erc_errors': 0, 'erc_warnings': len(erc_violations),
              'drc_warnings': len(drc['violations']), 'parity_warnings': len(drc['schematic_parity']),
              'origin_mm': [ox, oy], 'coordinate_convention': 'KiCad CSV Cartesian X/Y; no additional reflection',
              'rotation_corrections': corrections,
              'rotation_policy': 'Native KiCad rotations plus recorded JLCPCB corrections; confirm placement preview'}
    (checks / 'export-validation.json').write_text(json.dumps(result, indent=2) + '\n')
    print(json.dumps(result | {'source_hashes': 'retained', 'normalized_stale_fields': len(changes)}))
    return result


def main():
    parser = argparse.ArgumentParser(description=__doc__)
    parser.add_argument('output', type=Path)
    parser.add_argument('--boards', nargs='+', choices=BOARDS, default=BOARDS)
    parser.add_argument('--kicad-cli', default=shutil.which('kicad-cli') or
                        '/Applications/KiCad/KiCad.app/Contents/MacOS/kicad-cli')
    parser.add_argument('--converter', type=Path, default=Path.home() /
                        '.claude/skills/jlcpcb-bom-generate-from-kicad/scripts/convert_to_jlcpcb.py')
    args = parser.parse_args()
    output = args.output.resolve()
    output.mkdir(parents=True, exist_ok=True)
    module = importlib.util.spec_from_file_location('jlc_converter', args.converter)
    converter = importlib.util.module_from_spec(module)
    module.loader.exec_module(converter)
    inventory = json.loads((ROOT / '.claude/skills/component-spec-audit/references/inventory.json').read_text())
    results = [export_board(board, output, args.kicad_cli, inventory, converter) for board in args.boards]
    if (output / 'manifest.json').exists():
        previous = json.loads((output / 'manifest.json').read_text())['boards']
        results += [r for r in previous if r['board'] not in args.boards]
        results.sort(key=lambda r: BOARDS.index(r['board']))
    manifest = {'variant': 'JLCPCB fitted connectors; intentional circuit DNP preserved',
                'git_commit': subprocess.check_output(['git', 'rev-parse', 'HEAD'], cwd=ROOT, text=True).strip(),
                'kicad_version': subprocess.check_output([args.kicad_cli, '--version'], text=True).strip(),
                'boards': results}
    (output / 'manifest.json').write_text(json.dumps(manifest, indent=2) + '\n')
    for result in results:
        for path, expected in result['source_hashes'].items():
            require(digest(ROOT / path) == expected, f'Source changed during export: {path}')


if __name__ == '__main__':
    main()

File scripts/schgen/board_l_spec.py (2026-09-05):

"""Board L (driver, control, LED array) spec — from doc/src/content/docs/architecture/board-l.mdx.

LED polarity per the library symbol drawing: pin 1 = cathode (K), pin 2 = anode (A).
SS26: pin 1 = A, pin 2 = K. SMAJ20A: pin 1 = C, pin 2 = A. AL8860 EP = pin 9.
RV1 single-unit pot: 1 low, 2 wiper, 3 high; MP1–MP4 isolated mounting terminals.
"""

PROJECT_NAME = 'board-l'
OUT = 'boards/board-l/board-l.kicad_sch'
PAPER = 'A2'  # 71 parts + title block did not fit A3 without collisions

_C100N = ('CC0603KRX7R9BB104', '100nF/50V', 'C14663', 'zudo-led-lamp:C0603')
_C10U = ('CL31A106KBHNNNE', '10uF/50V', 'C13585', 'zudo-led-lamp:C1206')
_C22U = ('CL21A226MAQNNNE', '22uF/25V', 'C45783', 'zudo-led-lamp:C0805')
_R10K = ('0805W8F1002T5E', '10k', 'C17414', 'zudo-led-lamp:R0805')

COMPONENTS = {
    'SW2': ('SS-12D01-G020', 'Power ON/OFF slide', 'C5446803', 'zudo-led-lamp:SW-TH_SS-12D01-G020', False, (444.5, 50.8)),
    # power input and LED driver (top row)
    'J2':   ('PM254V-11-06-H85', '2.54mm 1x6 female', 'C2832269', 'zudo-led-lamp:HDR-TH_6P-P2.54-V-F', False, (38.1, 50.8)),
    'F1':   ('BSMD1206-075-30V', 'PPTC 750mA/30V', 'C976305', 'zudo-led-lamp:F1206', False, (88.9, 50.8)),
    'D10':  ('SMAJ20A_C571370', 'SMAJ20A', 'C571370', 'zudo-led-lamp:SMA_L4.2-W2.6-LS5.3-RD', False, (127, 50.8)),
    'U2':   ('AL8860MP-13', 'AL8860MP-13', 'C500782', 'zudo-led-lamp:MSOP-8_L3.0-W3.0-P0.65-LS4.9-BL-EP1.8', False, (177.8, 50.8)),
    'RS1':  ('RLP25FEER200', '200mR 1% 2W', 'C459674', 'zudo-led-lamp:R2512', False, (228.6, 50.8)),
    'L1':   ('FXL0630-330-M', '33uH', 'C177245', 'zudo-led-lamp:IND-SMD_L7.0-W6.6_FXL0630', False, (266.7, 50.8)),
    'D11':  ('SS26_C7420363', 'SS26', 'C7420363', 'zudo-led-lamp:SMA_L4.3-W2.6-LS5.0-FD', False, (304.8, 50.8)),
    'U4':   ('AP63203WU-7', 'AP63203WU-7', 'C780769', 'zudo-led-lamp:TSOT-26_L2.9-W1.6-P0.95-LS2.8-BL', False, (342.9, 50.8)),
    'L2':   ('FNR4030S4R7MT', '4.7uH', 'C167874', 'zudo-led-lamp:IND-SMD_L4.0-W4.0_FNR40XXS', False, (381, 50.8)),
    # MCU, knob, interfaces (second row)
    'U3':   ('STM32G031F8P6', 'STM32G031F8P6', 'C529334', 'zudo-led-lamp:TSSOP-20_L6.5-W4.4-P0.65-LS6.4-BL', False, (76.2, 101.6)),
    'RV1': ('RK10J11E0034', '10k brightness pot', 'C470643', 'zudo-led-lamp:POT-TH_RK10J11E0034', False, (165.1, 101.6)),
    'J3':   ('PZ254V-11-05P', 'SWD 1x5 (hand-fit)', 'C492404', 'zudo-led-lamp:HDR-TH_5P-P2.54-V-M', True, (203.2, 101.6)),
    # dnp=False like Board P's J2/J3 and TP1: a bare-copper pad group has no part to
    # leave unpopulated. It is kept out of the BOM by its empty LCSC field instead.
    'J4':   ('Conn_1x03', 'UART pads', '', 'zudo-led-lamp:PogoPad_1x03_P2.54mm', False, (241.3, 101.6)),
    'RT1':  ('NCP18XH103F03RB', 'NTC 10k B3380', 'C13564', 'zudo-led-lamp:R0603', False, (279.4, 101.6)),
    'C20':  (*_C100N, False, (317.5, 101.6)),
    'C24':  (*_C100N, False, (355.6, 101.6)),
    # capacitors (third row)
    'C10':  (*_C10U, False, (38.1, 152.4)),
    'C11':  (*_C10U, False, (73.66, 152.4)),
    'C12':  (*_C10U, False, (109.22, 152.4)),
    'C13':  (*_C100N, False, (144.78, 152.4)),
    'C14':  (*_C10U, False, (180.34, 152.4)),
    'C15':  (*_C100N, False, (215.9, 152.4)),
    'C16':  (*_C22U, False, (251.46, 152.4)),
    'C17':  (*_C22U, False, (287.02, 152.4)),
    'C18':  (*_C100N, False, (322.58, 152.4)),
    'C19':  ('CL10A105KB8NNNC', '1uF/50V', 'C15849', 'zudo-led-lamp:C0603', False, (358.14, 152.4)),
    # control-path passives (fourth row)
    'R20':  (*_R10K, False, (38.1, 177.8)),
    'R21':  ('0603WAF3302T5E', '33k', 'C4216', 'zudo-led-lamp:R0603', False, (73.66, 177.8)),
    'C21':  (*_C100N, False, (109.22, 177.8)),
    'C22':  (*_C100N, False, (144.78, 177.8)),
    'R22': ('0603WAF1003T5E', '100k wiper pull-down', 'C25803', 'zudo-led-lamp:R0603', False, (215.9, 177.8)),
    'R24':  (*_R10K, False, (287.02, 177.8)),
    'R25':  (*_R10K, False, (322.58, 177.8)),
    'R26':  ('0603WAF1003T5E', '100k', 'C25803', 'zudo-led-lamp:R0603', False, (358.14, 177.8)),
    'R27':  ('0603WAF1000T5E', '100R', 'C22775', 'zudo-led-lamp:R0603', False, (393.7, 177.8)),
    'TP1':  ('TestPad', 'CTRL test pad', '', 'zudo-led-lamp:TestPad_D1.5mm', False, (393.7, 152.4)),
}

# ballast row + LED array: string n (1..8) = R(29+n) + LED(3n-2), LED(3n-1), LED(3n)
_BALLAST = ('FRC2512F33R0TS', '33R 1% 1W', 'C2934070', 'zudo-led-lamp:R2512')
_LED = ('HL-AM-2835H421W-S1-08-HR3', '2835 3000K CRI80', 'C210315', 'zudo-led-lamp:LED-SMD_L3.3-W2.8-RD')
for _n in range(1, 9):
    _x = 38.1 + 35.56 * (_n - 1)
    COMPONENTS[f'R{29 + _n}'] = (*_BALLAST, False, (_x, 203.2))
    COMPONENTS[f'LED{3 * _n - 2}'] = (*_LED, False, (_x, 228.6))
    COMPONENTS[f'LED{3 * _n - 1}'] = (*_LED, False, (_x, 254))
    COMPONENTS[f'LED{3 * _n}'] = (*_LED, False, (_x, 279.4))

# Keep control values clear of their pin labels
LABEL_OVERRIDES = {
    'SW2': {'Value': (462.28, 53.34)},
    'RV1': {'Value': (165.1 + 17.78, 101.6 + 2.54)},
}

EXTERNAL_COMPONENTS = {}
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

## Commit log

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2026-07-26 Add control-side research: logic rail, MCU, knob, modulation
    Research for issue #7: 15V->3.3V logic rail (buck vs LDO with honest
    dissipation math), CH32V003/STM32C0-G0/PY32F0 MCU candidates with
    programming-interface and macOS toolchain notes, potentiometer vs
    rotary-encoder knob options with an honest JLCPCB-availability
    verdict, fire/wave modulation pseudocode with PWM-frequency and
    gamma-correction notes, and safe default-OFF + fault-handling
    sketches. All parts verified against the local JLCPCB DB. Final
    selection intentionally left open for the architecture sub-issue.
2026-07-26 Add power/ docs section: USB-PD Board-P audit distilled from zudo-pd
    Adapts zudo-pd's reusable Board A USB-PD 15V sink core into this
    project's Board P, as an audit rather than a copy: every LCSC number
    re-verified against the local JLCPCB DB, and every rating claim
    re-checked against primary manufacturer datasheets.
    - board-p-front-end.mdx: adapted topology, net table, Mermaid diagram,
    downstream interface, component list.
    - ratings-matrix.mdx: per-part worst-case ratings vs 15V nominal and
    the SMAJ20A ~32.4V clamp ceiling. Resolves the C456012 USB-C
    receptacle discrepancy (manufacturer datasheet + JLCPCB catalog both
    show a 5V/3A headline rating, not the 20V/3A zudo-pd's docs clai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
2026-07-26 Fix set -e/pipefail bug in PR-preview URL extraction; tighten docs
    Self-review (codex-review timed out mid-investigation; fell back to a
    foreground pass) found that grep finding no match inside the
    DEPLOY_URL=$(... | head -1) assignment aborts the script under GitHub
    Actions' default `bash -eo pipefail`, skipping the intended graceful
    "no preview URL yet" fallback and turning a non-fatal case into a red
    job. Added `|| true` to the pipeline.
    Also corrected the how-to doc's description of what the "Edit
    Cloudflare Workers" token template grants (it already includes
    Zone -> Workers Routes -> Edit) and called out the Zone Resources
    scoping step that actually trips people up when creating the to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
2026-07-26 Fix self-review findings in control-research pages
    - modulation-algorithms: the flicker pseudocode's smoothing param had
    its filter math backwards from its prose description (higher value
    actually made it more twitchy, not lazier) - renamed to
    responsiveness and corrected the explanation.
    - control-logic-rail: LDO price column claimed a "1-9" quantity break
    that doesn't exist for either part; labeled with actual tiers.
    - mcu-candidates: softened an unverified specific GPIO-count claim for
    the CH32V003 SOP-8 variant.
2026-07-26 docs(power): apply self-review fixes to Board P audit pages
    Drop forward-references to sibling doc sections that do not exist yet,
    and correct the C456012 headline-rating undersell factor from 3x to 4x
    (5V/3A headline vs the 20V/5A datasheet-verified replacement).
2026-07-26 fix(docs): use bracketed admonition title, correct the scaffold's syntax note
    `:::danger{title="..."}` is Docusaurus syntax, not this toolchain's — MDX
    parsed the braces as a JS expression and the build failed with
    "title is not defined". The correct form is `:::danger[Title]`.
    The scaffolded doc/CLAUDE.md (and its generated claude-md/root.mdx) documents
    the wrong form, which is where the mistake came from; corrected both so the
    next reader is not misled. Worth reporting upstream to zudo-doc.
2026-07-26 fix(docs): escape comparison operators in driver-ics table
    `<0.3V` at the start of a table cell was parsed as a JSX tag open, failing
    the MDX compile with "Unexpected character 0 before name". Wrapped both
    threshold values in inline code, which also reads better as literal values.
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2026-07-26 docs: fix cross-page anchors, order research sidebar, refresh CI token status
    Confirm-pass fixes for issue #9:
    - board-l.mdx linked control-safety headings as
    #fault-handling-sketch-knob-fault-fallback (parent+child concatenated);
    the real anchors are #knob-fault-fallback and
    #over-temperature-derating-hook. 3 dead anchors.
    - The 5 control-research pages had no sidebar_position, so they sorted
    arbitrarily against the LED pages' 1-4. Assigned 5-9 in reading order:
    logic rail, MCU, knob, modulation, safety.
    - The CI how-to page was written while CLOUDFLARE_API_TOKEN was still
    missing. It is now set and the pipeline is verified end-to-end, so the
    page led with a stale "one step s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
2026-07-26 docs: clarify admonition syntax and both failure modes of Docusaurus style
    Sync guidance to match upstream fix in create-zudo-doc@4.4.7 (zudolab/zudo-doc#3104).
    Docusaurus-style `{title="..."}` fails in two ways: either the build fails with
    ReferenceError, or it builds but silently drops the title. The silent-drop case
    is more dangerous because no error surfaces. Update docs to state both outcomes
    and require always using the bracketed `:::note[Custom Title]` form.
    Note: scaffolder is one-shot, so already-generated files must be synced by hand.
2026-07-26 feat(doc): list all top-level categories in the header nav
    The header nav still carried the scaffold defaults (Getting Started +
    Claude), so the three categories this project actually exists to document —
    architecture, power, research — were unreachable from the header and only
    findable by guessing a URL.
    Per zudo-doc's navigation rules (header holds 3-6 top-level categories, each
    categoryMatch a single top-level directory):
    - Add the four missing category index.mdx landing pages (architecture, power,
    research, how-to). The rules require every category directory to have one;
    without it the category has no landing page for its header tab to point at.
    Each is a short intro plus <Ca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
2026-07-26 feat: rename docs site from scaffold placeholder to project name
    Replace the default scaffold siteName "Doc" with "zudo-led-lamp" in zfb.config.ts
    and update the welcome prose in getting-started index. Verified: pnpm build green
    at 36 pages, dist/index.html renders <title>zudo-led-lamp</title>.
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2026-07-31 feat: capture Board P schematic from the locked net table
    Generated by scripts/schgen/gen_board_p.py: all 24 components placed
    with global labels per pin, verified two ways with kicad-cli --
    ERC passes with zero violations (including warnings) and the exported
    netlist matches doc/architecture/board-p.mdx net-for-net (17 nets,
    89 nodes, 6 intentional no-connects).
    - symbols lib: all pins retyped passive (EasyEDA import had bogus
    Input types), Conn_1x04/Conn_1x08 pogo-pad symbols added
    - footprints: PogoPad_1x04/1x08_P2.54mm hand-made pad arrays added
    - C2/C35 use C14663 (0603, Basic) per the recommended Extended-fee
    swap in the docs; DNP parts (R17/R18, D6/D7) carry the dnp flag
    - verify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
    [board-p.kicad_sch]
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2026-07-31 fix: schematic readability — labels outside bodies, Board L on A2
    - reference/value text now placed from the symbol's pin extents
    (above/below the body) instead of a fixed offset that landed inside
    large IC bodies; per-ref overrides for Q1 and SW1 where vertical
    net labels occupy the default spots
    - Board L moved to A2: the 68-part grid collided with the A3 title
    block and bottom border
    - connectivity unchanged: both boards still ERC-clean and
    netlist-verified against their specs
    [board-l.kicad_sch, board-p.kicad_sch]
2026-07-31 fix: apply design-review findings to both boards and docs
    Independent electrical review (netlists confirmed pin-for-pin against
    datasheets; three real problems found, all fixed before fab):
    Board P:
    - C35 soft-start re-referenced gate-to-SOURCE (VBUS_IN), not GND.
    Ground-referenced it let Q1 conduct ~16ms at every plug-in and slam
    on un-soft-started at the 5->15V contract step
    - R12 56k -> 150k (C22807): old divider put VGS at -12.8V in a 20V
    mis-contract, over the AO3401A's +/-12V abs max; now -8.0V there
    - U1.RESET now reaches GND via new R21 10k (C17414) and is brought
    out on J2.4 so the programming jig can recover a wedged NVM write
    Board L:
    - ballast R30-R37: 1206 250mW -> 251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
    [board-l.kicad_sch, board-p.kicad_sch]
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2026-08-01 Correct stale part-count comment in board_l_spec.py
    59db76d added R27, R28, and TP1 to board-l without updating the paper-size
    comment; the dict has 71 components now, not 68.
    [board_l_spec.py]
2026-08-01 Add schgen verify.sh and README documenting the regen+verify workflow
    verify.sh records the exact kicad-cli invocation that produces the netlist
    consumed by verify_netlist.py (previously undocumented — 59db76d marked the
    netlist "verified" but the export was run by hand). It exports via
    `kicad-cli sch export netlist --format kicadsexpr` for a named board, then
    diffs against the spec through verify_netlist.py, printing PASS/FAIL.
    Degrades gracefully when kicad-cli isn't installed: prints a SKIPPED marker
    and exits 0, since this is a local-only check (no KiCad on the CI runner).
    README.md documents the edit-spec -> regen -> verify -> commit-together
    workflow and explains what the new CI re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
2026-08-01 Make schematic-generator UUIDs deterministic; regen both boards
    gen_schematic.py assigned every uuid via uuid.uuid4() (random), so two runs
    from an unchanged spec never produced the same file — only the opaque
    identifiers differed, never COMPONENTS/NETS/PAPER content (verified via a
    UUID-normalized diff of consecutive runs before this change). This blocks
    the CI regen-idempotency check added in the next commit: `git diff
    --exit-code boards/` after a regen would fail on every run regardless of
    whether the spec actually changed.
    new_uuid() now derives a uuid5 from a stable identity string (project name
    plus ref/net/pin/index), so regenerating from an unchanged spec reproduces
    the committed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
    [board-l.kicad_sch, board-p.kicad_sch]
2026-08-01 CI: watch scripts/schgen/** and enforce regen-idempotency
    Widen both path filter lists from the two spec files to the whole
    scripts/schgen/** tree, so changes to the generator/verifier scripts
    themselves (schgen_core.py, sexp.py, gen_schematic.py, verify_netlist.py,
    verify.sh, README.md) trigger this workflow too.
    Add a pure-Python regen-idempotency step: run gen_schematic.py for both
    boards on the checked-out tree, then git diff --exit-code boards/. This
    needs no KiCad (sexp.py is a self-contained parser) so it runs on the
    ubuntu-latest runner. It catches "spec and committed schematic drifted
    apart" (e.g. spec edited without regenerating, or a hand-edited
    .kicad_sch) but not wiring mistake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
2026-08-01 Fix untruthful OPEN coverage reasons and add machine-readable blocking_fact_ids lint
    The JST cov-jst-project-map entry blamed unsourced catalog facts (all PASS)
    for an open Board P/L signal-mapping domain, when the real gap is that no
    fact captures the JOUT1/J2 binding at all (it only lives in pin-map.json/
    interactions.json). The Murata cov-c13564-context entry bundled 4
    current-primary PASS facts under an "unsourced older-catalog" rationale
    that contradicted the skill's own SKILL.md. Both are corrected to cite only
    the facts that truthfully keep each domain open.
    Six coverage.json files also carried a copy-pasted boilerplate sentence
    fragment glued on without a sentence break; repaired wi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
2026-08-01 Confirm Alps EC11L1525G01 primary source unavailable; add real-operating-point bench-gate
    Retried manufacturer-primary retrieval for EC11L1525G01 (issue #42). A
    control test against the sibling EC11E15244G1 detail page (HTTP 200)
    shows the block is specific to this part, not a generic bot filter,
    and no EC11L series appears in any current encoder sub-category
    listing on tech.alpsalpine.com. Recorded as a new dated SOURCE
    UNAVAILABLE entry; fact-c2991196-detents and fact-c2991196-label-conflict
    stay UNSOURCED/unresolved as neither outcome branch authorizes a
    generator/schematic correction here.
    Added the encoder real-operating-point bench-gate coverage item: the
    real 3.3 V/10k pull-up (R22/R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
2026-08-02 Recover FXL0630/FNR4030 manufacturer-primary trust; add AL8860 duty-band fact
    Issue #45: attempted direct manufacturer-primary retrieval for the
    mirror-only power-stage secondaries.
    - FXL0630-330-M (Changjiang/cjiang): retrieved the manufacturer's own
    FXL0630 series spec sheet from cjiang.com.cn (plain HTTP; the site's
    HTTPS certificate is expired). Confirms manufacturer, inductance,
    tolerance, DCR max, absolute-maximum voltage, temperature range, and
    package -> PASS/PRIMARY-SPEC. Its ratings table shows only a single
    typical-labeled Isat/Irms column, not the mirror's separate max-design
    column, so fact-fxl-isat-max/irated-max and the dependent isat-margin
    stay UNSOURCED/NEEDS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
2026-08-02 Lock Wave-3 circuit-recheck decisions
    Convert Wave-2 evidence into mechanical specs for Wave-4 (#48, #49).
    Encoder: Alps primary retrieval failed (part-specific HTTP 403; EC11L
    absent from the current catalog), so no metadata change is authorized.
    NTC: Murata's 0.1 mA is an operating maximum, and the as-built 10k R26
    exceeds it by 68% at 25 C. 33k is rejected because its NTC-shorted
    asymptote (101.9 uA) already exceeds the limit. R26 moves to the
    existing 100k C25803 line: 33.6 uA worst case, 2.97x margin, with
    retabulated 104/69 ADC thresholds and a 160.5-cycle sample time.
    LED: locked acceptance bound of 0.30 V string-total Vf spread; the
    driver's own worst case already consumes 89% of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
2026-08-02 NTC divider R26: 10k -> 100k (line-c25803), regen board-l
    The as-built 10 kOhm divider drew 168 uA worst case at 25 C, 1.68x
    Murata's 0.1 mA operating-current maximum (fact-c13564-max-current).
    100 kOhm gives 33.6 uA worst case (2.97x margin, holds under a
    shorted-thermistor fault); 33 kOhm was evaluated and rejected since its
    NTC-shorted asymptote already exceeds the limit. Uses the existing
    line-c25803 (already placed at board-p R11) instead of a new
    inventory line, moving its footprint to R0603 to match board-p R11 and
    satisfy validate.py's per-LCSC package-consistency check. No encoder
    change: Alps manufacturer-primary retrieval failed (part-specific 403)
    and mirror-only evidence cannot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
    [board-l.kicad_sch]
2026-08-02 docs: sweep Wave-3 decisions into board-l, control-knob, board-p-front-end, next-steps (#49)
    Applies the locked circuit-recheck decisions (Wave-3, #47) to the docs: NTC
    divider R26 100kΩ with the corrected 0.1 mA operating-current limit and ADC/
    sample-time/beta-uncertainty caveats; LED current-sharing rewritten to the
    honest peak-vs-mean model with the locked 0.30 V spread acceptance bound and
    306 mW package rating (was a derived 288 mW); CTRL annotated as nominal-only
    with the 99.9% guaranteed floor; AL8860 DSW/DSW(MAX)/CTRL three-way duty
    distinction; encoder pulses/detents left unresolved with a caveat linking #32
    (no metadata change); BOOT0 overclaim replaced with the option-byte cavea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
2026-08-02 docs: fix bom.mdx R26 grouping and decisions.mdx stale risk-summary lines (#49 follow-up)
    Moves board-l:R26 from the 10kΩ/C17414 BOM line to the 100kΩ/C25803 line to
    match the merged #48 inventory state (Decision 2), updates the Board L
    unique-fitted-part-number/Basic-tier totals to match, and fixes three stale
    lines in decisions.mdx's open-risks summary: duty cycle 78%->81% with the
    DSW/DSW(MAX) band citation, the LED-imbalance claim rewritten to the honest
    peak-current finding (98.0% at the 0.30V acceptance limit, linking #52), and
    the R21/CTRL provability line marked Resolved to match board-l.mdx's own
    note. Also fixes a same-page anchor link in board-l.mdx introduced in the
    prior commi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
2026-08-02 fix(audit): make the blocking_fact_ids lint structural, not keyword-based
    An OPEN coverage entry could dodge the blocking_fact_ids requirement by
    rewording its reason to avoid the unavailable/lower-authority/UNSOURCED
    keywords. Replace that with a structural rule: any OPEN entry whose
    fact_ids contain a fact with verdict UNSOURCED or NEEDS BENCH, or citing
    a SOURCE UNAVAILABLE source, must name at least one in blocking_fact_ids.
    The keyword check stays as an additional guard.
    A NOT APPLICABLE fact does not address the domain and never blocks, so
    component-stm32g031f8p6's cov-c492404-fit keeps its empty array
    legitimately — resolved by wording, no whitelist and no data change.
    contract.md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
    [schgen_core.py]
2026-08-02 docs: correct LED overclaims, guard-band narrative, and encoder detent cell
    Append a dated Corrections section to the circuit-recheck decision
    artifact (original text left intact) covering two Decision 3 defects:
    1. "Inputs, all from PASS facts" is wrong. fact-al8860-peak-current and
    its chain (fact-al8860-current-max, fact-rlp25-resistance-min) are
    NEEDS BENCH. The leaves are manufacturer-primary PASS facts; it is
    the composition that no bench has confirmed. Doc wording therefore
    says "datasheet worst case, bench-unverified", not "guaranteed" —
    and not "mirror-derived", since no mirror is involved.
    2. The guard-band narrative was self-inconsistent. The fitted ballast
    F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
2026-08-02 docs: fix three pre-existing broken internal anchors (compound-slug rule)
    Closes #53. board-l.mdx knob-fault-fallback and over-temperature-derating-hook
    links gain the fault-handling-sketch- parent prefix; decisions.mdx driver-ics
    link updated to the heading renamed in 378b92f.
2026-08-02 docs: fix stale 'passes by construction' current-sharing claim in decisions.mdx
    The pre-existing rationale used the disavowed derived 0.288 W rating and
    asserted unconditional pass at the full Vf window, contradicting board-l's
    corrected analysis (142.5% of the 90 mA absolute maximum at full window;
    98% at the issue-35 acceptance bound).
2026-08-02 doc: publish the repo-root Claude skills, not the doc site's own
    `claudeResources.claudeDir` was `.claude`, which resolves against the
    doc-site project root — so the site published `doc/.claude` (three
    skills for editing this site) and never saw the 15 component-audit
    skills at the repo root. Point `claudeDir` at `../.claude` and widen
    `scanRoot` to `..` so CLAUDE.md discovery covers the whole repo while
    generated pages still land in `doc/src/content/docs`.
    Effects:
    - /docs/claude-skills/ now lists all 15 root skills.
    - /docs/claude-md/ gains `footprints.mdx` and `doc.mdx`; `root.mdx` now
    holds the repo-root CLAUDE.md (the component routing rules) instead of
    the doc site's own.
    - The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
2026-08-02 ci: trigger doc workflows on the repo-root sources the site now publishes
    The doc site's inputs moved outside doc/ when claudeResources was repointed
    at ../.claude, but pr-checks.yml and main-deploy.yml still filtered on
    doc/** only. A commit touching just .claude/skills/** or a repo-wide
    CLAUDE.md would change the built site while skipping both the PR build and
    the production deploy, leaving the published pages stale.
    Widen both paths filters, and add a drift check asserting the committed
    doc/src/content/docs output matches a fresh build — the generated pages are
    committed artifacts, so a source edit landing without a rebuild is now a red
    PR instead of silent staleness. Mirrors the board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
2026-08-02 fix(component-docs): apply self-review findings
    - read.ts: lstat the skills root itself, not only the segments below it; a
    symlinked `.claude/skills` would otherwise redirect every read while each
    individual segment looked clean.
    - adapters/circuit: read bundle files by name instead of destructuring a
    positional tuple, which would have silently misaligned if BUNDLE_FILES were
    reordered. routing.json is now read into a named binding with a comment
    explaining it is validated-but-not-projected until #59.
    - watch.ts: drop `unref()` on the debounce timer. The fs watcher keeps the
    loop alive in real use, but unref'ing left a latent path where a pending
    regeneration could be dropped o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
2026-08-02 fix(component-docs): scope anchor uniqueness per page, not per site
    `PublicInteraction.recordIds` is plural by design — one interaction is
    published on every participating record's page, and 6 of this corpus's 50
    span 2-4 records. The pipeline flattened interaction anchors across all
    records and asserted global uniqueness, so attaching an interaction to its
    participants aborted the build on exactly the fan-out the type exists to
    express.
    Anchors become HTML ids, where the real invariant is uniqueness within a
    document. Record-scoped nodes each carry a singular recordId and so live on
    one page, where global uniqueness is the stricter check and is kept.
    Interactions are now checked per page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
2026-08-02 feat(component-docs): project the full evidence corpus into the public view model
    Fills the arrays Wave 1 froze empty: aliases, sources, facts, coverage,
    interactions and pin maps now carry the real corpus — 32 records, 81 sources,
    369 facts, 109 coverage domains, 50 interactions, 33 pin maps, 140 pins.
    The joins move into `adapters/circuit/evidence.ts` and the projection becomes
    `projectIndex`, both pure over parsed JSON, so every relationship rule and every
    publication rule is provable against a fixture corpus without a filesystem, a
    subprocess, or an edit to the read-only evidence tree.
    Two decisions worth reviewing:
    - `PublicFact["value"]` widens to `number | SafeText | PublicFactVa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
2026-08-03 fix(schgen): keep bare-copper pad groups out of the assembly BOM
    next-steps.mdx requires footprint-only pad groups to be absent from the
    assembly BOM, but in_bom was hardcoded yes and the DNP flags disagreed:
    board-l J4 was dnp=True while board-p J2/J3 and board-l TP1 were False.
    A JLCPCB import would have carried placement rows with blank part
    numbers.
    in_bom is now derived from the LCSC field — an orderable line always has
    one, bare copper never does — and J4's misleading DNP marker is dropped.
    The three real DNP lines (D6/D7, R17/R18, board-l J3) keep in_bom=yes,
    dnp=yes since they are purchasable.
    [board-l.kicad_sch, board-p.kicad_sch]
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2026-08-23 fix(board-l): resolve PCB DRC violations
    [board-l.kicad_pcb]
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2026-09-05 Replace external rocker schematic with JLCPCB C496154 and audited slotted assets
    [board-l.kicad_sch]
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2026-09-05 Replace tall bottom controls with short slider and ALPS potentiometer (#115)
    * feat: replace tall controls with stopped ALPS pot and short slider
    * feat: route low-profile controls and audit assembly geometry
    * docs: publish ALPS potentiometer and slider evidence and previews
    * docs: fix rear-controls brightness section link
    [board-l.kicad_pcb, board-l.kicad_sch]
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
